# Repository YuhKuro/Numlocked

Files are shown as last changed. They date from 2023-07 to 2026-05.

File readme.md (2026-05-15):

GIF
## Directory:
- [Keyboard Hardware](hardware/readme.md)
- [Keyboard Firmware](firmware/readme.md)
- [Keyboard Case and Plate](case/readme.md)
- [Revision 1](Revision1/readme.md)
## Features
### **Keyboard Features:**
#### - **Modular split design**: Split 75% layout, flexible configuration with or without numpad
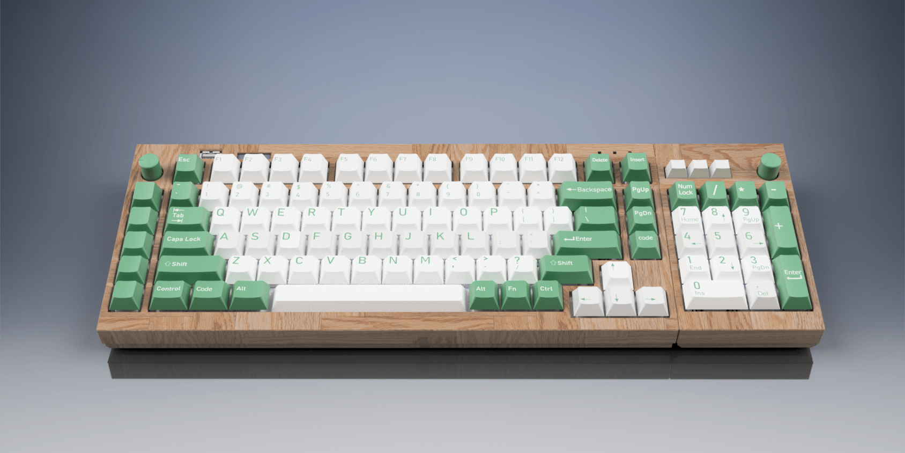
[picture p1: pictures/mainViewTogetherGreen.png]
Front

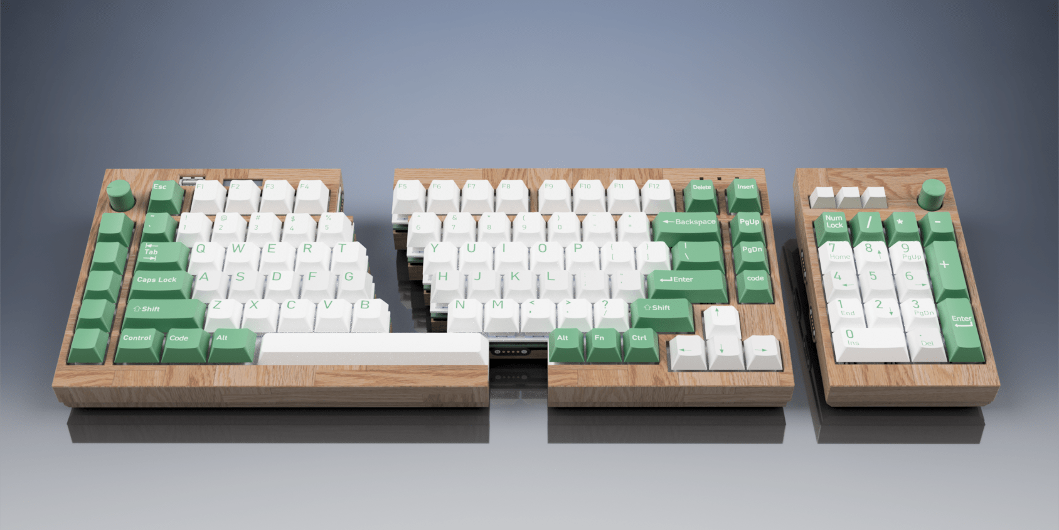
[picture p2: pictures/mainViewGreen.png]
Main

#### - **Magnetic connectors for quick configuration changes**
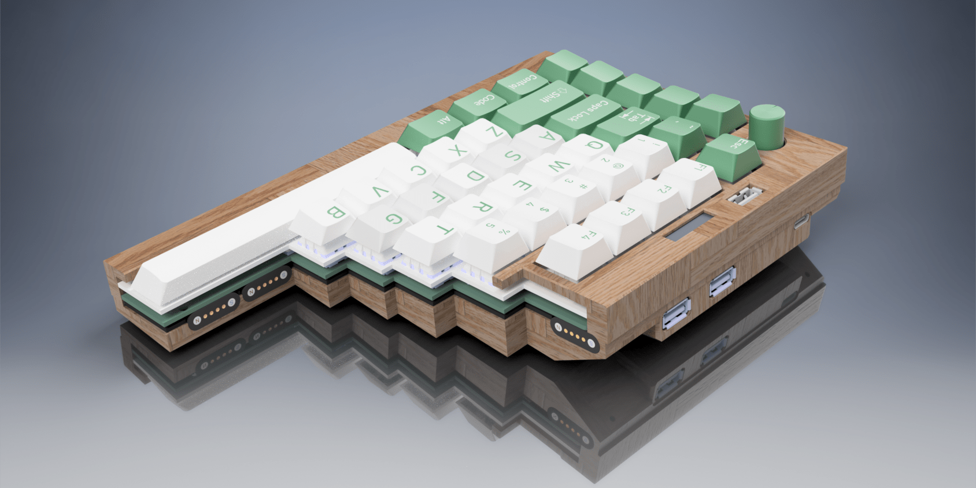
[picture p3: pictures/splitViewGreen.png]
magnets

#### - **Hot swappable & Gasket mount design**
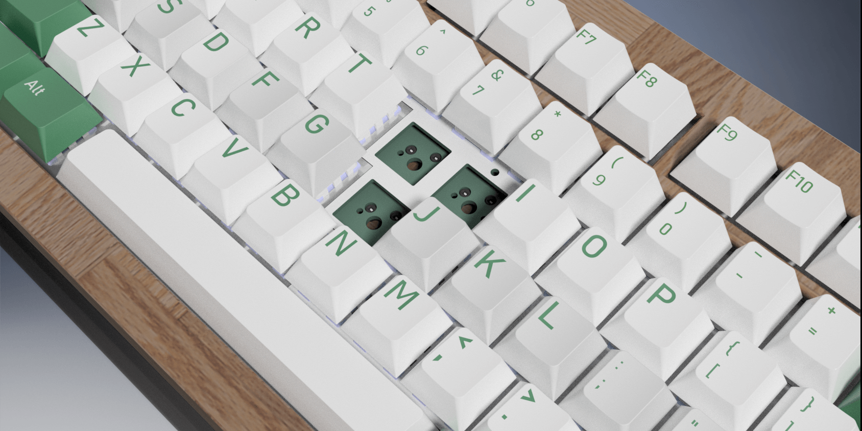
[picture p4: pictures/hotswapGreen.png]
Hotswap

#### - **Built-in USB Hub**: 3 USB-A ports (1 vertical, 2 horizontal)
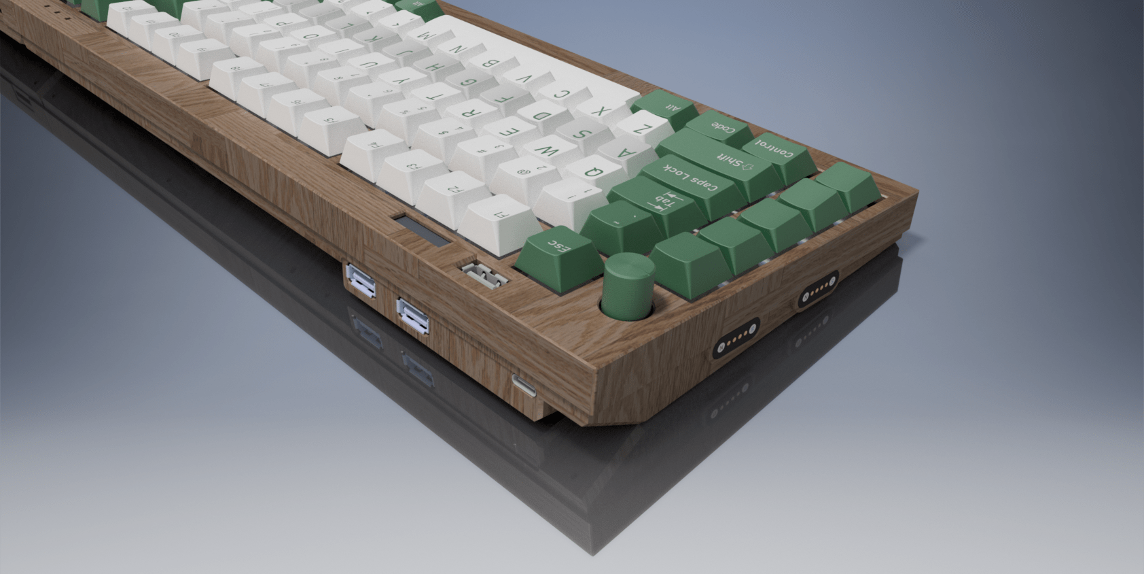
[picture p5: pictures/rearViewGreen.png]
Rear

#### - **Volume Knobs and Five Macro Keys**: Customizable for any function
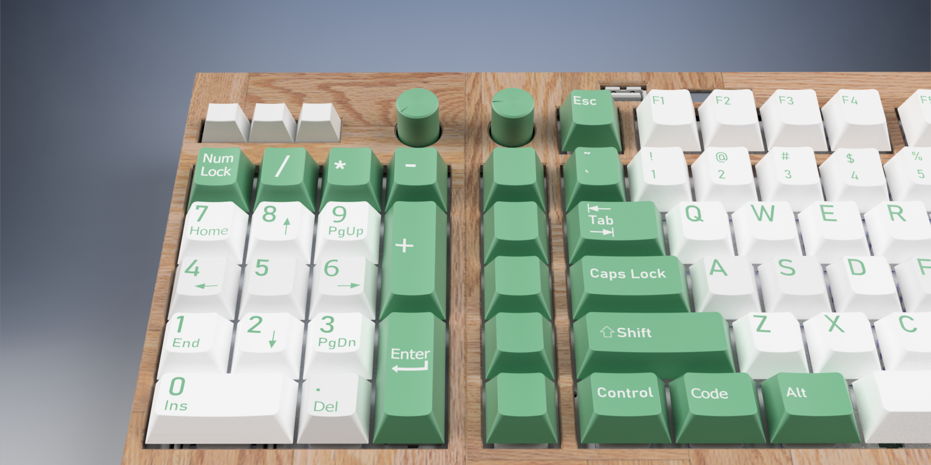
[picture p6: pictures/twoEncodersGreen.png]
Encoder

#### - **128x32 OLED**: Custom animations
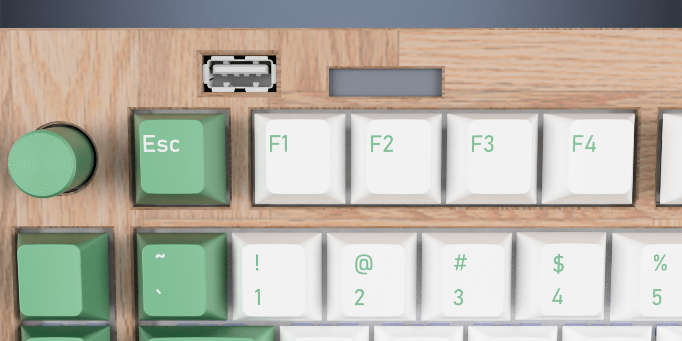
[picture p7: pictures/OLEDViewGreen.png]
OLED

#### - **Caps-lock, Num-lock and Scroll-Lock LEDs**
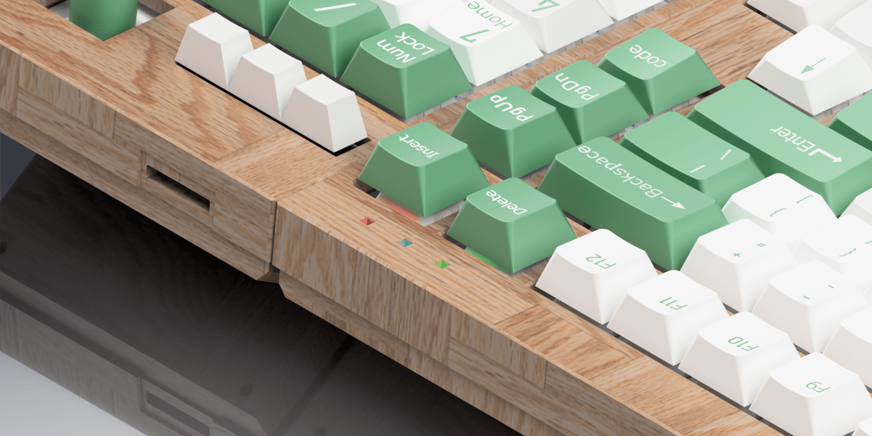
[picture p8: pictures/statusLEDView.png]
LEDs

#### -**Custom Hardware**: Three multilayer PCBs custom designed for Numlocked
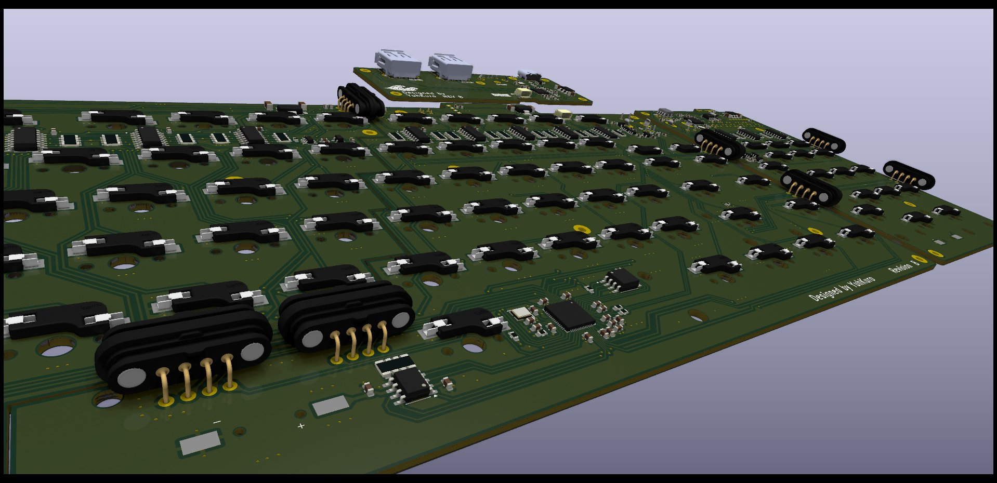
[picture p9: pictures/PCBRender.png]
Hardware

- **Shift-Registered Design**: Faster scanning than traditional matrix-based keyboards.
- **RP2040 chip**: Easy to program, very customizable, affordable.
- **Real-Time Clock (RTC)**: Keeps accurate time for the user.
#### - **Open Source**
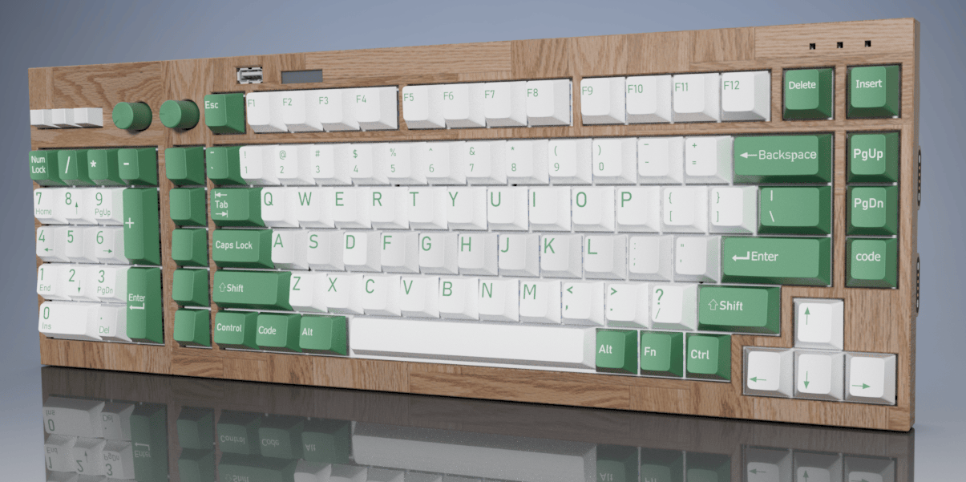
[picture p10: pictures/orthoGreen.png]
Ortho

- **Home Build**:
	- Akko CS Silver Switches
	- Durock V2 PCB Mount Stabilizers + holee mod
	- FR4 Plate
	- Resin 3D Printed case
- **Work Build**:
	- Akko CS Penguin case
	- Durock V2 PCB Mount Stabilizers + holee mod
	- FR4 Plate
	- Resin 3D Printed case

## Build Instructions
*See the [Build Guide](hardware/docs/buildInstructions.md) for detailed steps.*
## Customization
Firmware, coded in C, which leverages all the features of this keyboard are provided in this repo. [Learn more](firmware/readme.md)
Please note that QMK/VIA are currently incompatible with shift-register based keyboard designs.
## Commonly Asked Questions
- Why is it split?
	- I wanted to experiment with ergonomics. Another reason was production, The largest surface area my hotplate could manage was 400x400mm for reflow soldering.
- What was the total cost?
	- Will update once everything is complete.

## Thank you to:
- [SSD1306 library] (https://github.com/daschr/pico-ssd1306) by dachr. I added a function to print both images and text, but it was with his foundations that I was able to quickly get the OLED working.
- [cJSON library] (https://github.com/DaveGamble/cJSON) by DaveGamble. I swear I'm always using this. Its never failed me once. 
- And you, for viewing!

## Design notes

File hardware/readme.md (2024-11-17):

# Hardware

## Table of Contents
- [Introduction](#introduction)
- [Keyboard Fundamentals](#keyboard-fundamentals)
- [HUB PCB](#hub-pcb)
- [Leftside PCB](#left-side-pcb)
- [Rightside PCB](#right-side-pcb)
- [Numpad PCB](numpad-pcb)

## Introduction
The keyboard consists of four PCBs: A USB-Hub and three PCBs for each part of the keyboard: Leftside, Rightside and Numpad.
Each component is connected via magnetic pogo pins to transmit Power, Ground, keyboard signals and LED signals.

## Keyboard Fundamentals
Although most keyboards use a matrix-and-diode system, this keyboard uses a Parallel-load Serial-Shift shift-register approach.

Think of it like a train with containers moving along a circular track. Each container represents a key position, and the train can either load or shift its contents.

When the train is in "Load" mode, each container is set based on whether its corresponding key is pressed. If a key is not pressed, the container remains full; if it's pressed, the container will empty its contents out. 

In "Shift" mode, the train moves each container along, allowing us to check them one by one and identify which keys are pressed by checking which containers are empty.

In this keyboard, all shift registers are pulled up to 3V3 through a 10k-ohm resistor, so each key naturally sits at a high (3.3V) state, much like a full train car. When a key is pressed, it ground that bit on the shift register, reading it as low. By shifting the bits in the register the exact number of keys and feeding the information into an array, we will have a snapshot of what keys are pressed in that cycle. 

Since the SN74HC165DR Shift Registers used in this keyboard allow clocking in the range of a few MHz, there is practically zero chance a key input is missed as the next "load" phase is a just a few microseconds away.

This system also allows for minimal debouncing, requires zero diodes, only requires three pins to read any number of keys and true n-key rollover.

### Why this method?
Using shift registers allows for overall less individual soldering, easier programming and most importantly, only requires three pins (SH/~LD, CLK and Serial-Out).
If we chain shift registers beginning with the removable parts, such as the numpad, and transmit the serial-out to the next removable part, such as the right side, and finally to the left-side, we can manage a system with only one MCU by using multiplexers to avoid unknown values. 
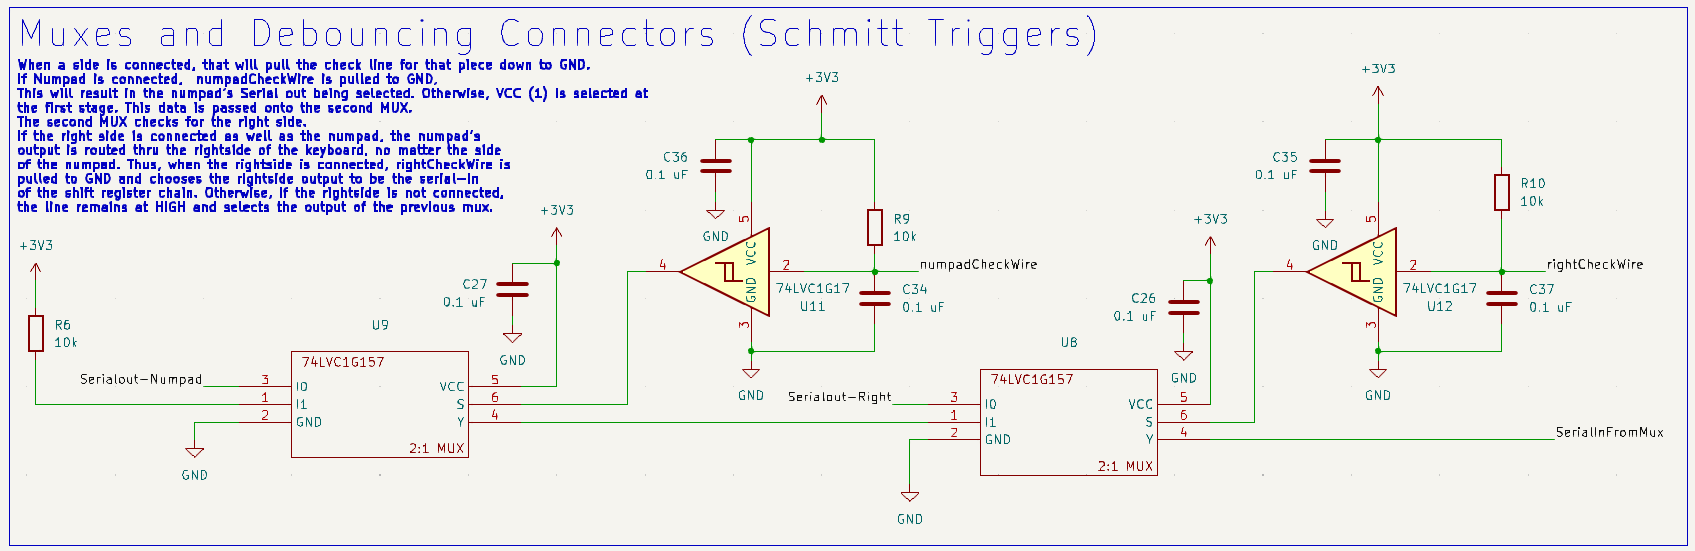
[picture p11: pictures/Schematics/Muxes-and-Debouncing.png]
Muxes and Connectors

We can do this by using multiplexers, which are basically data switches, and schmitt triggers which help ensure a clear signal. By using the schmitt triggers, the multiplexers always have a clean input on which component is connected. 

The flow chart into the first shift register of the left side is the following:

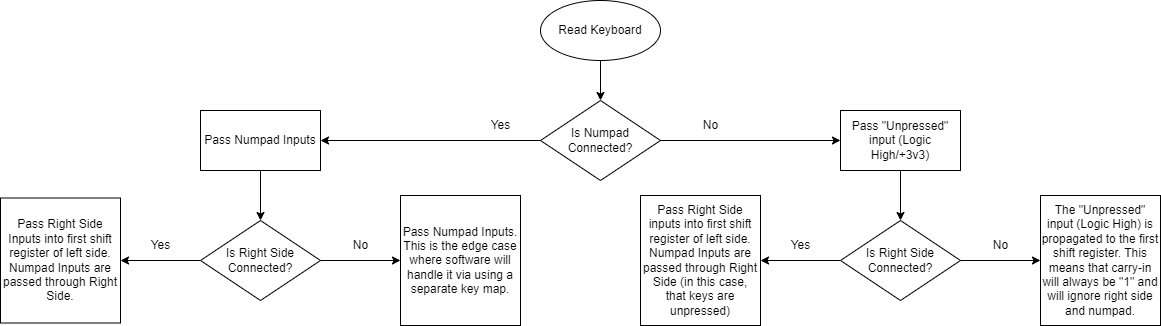
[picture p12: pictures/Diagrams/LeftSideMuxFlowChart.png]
Mux Flowchart


The edge case of numpad connected, but no right side is handled in software.

## Hub PCB
The Hub PCB is centered around a one-to-four USB 2.0 Full Speed HUB. There is one upstream USB-C port which connects to the user's computer and three USB-A ports for other peripherals, as well as an FFC cable which connects it to the keyboard itself.

To minimize space used in the case, there is a notched hole on the PCB itself to allow the FFC Cable to connect between the Hub to the keyboard PCB even when the two PCBs may be flush.

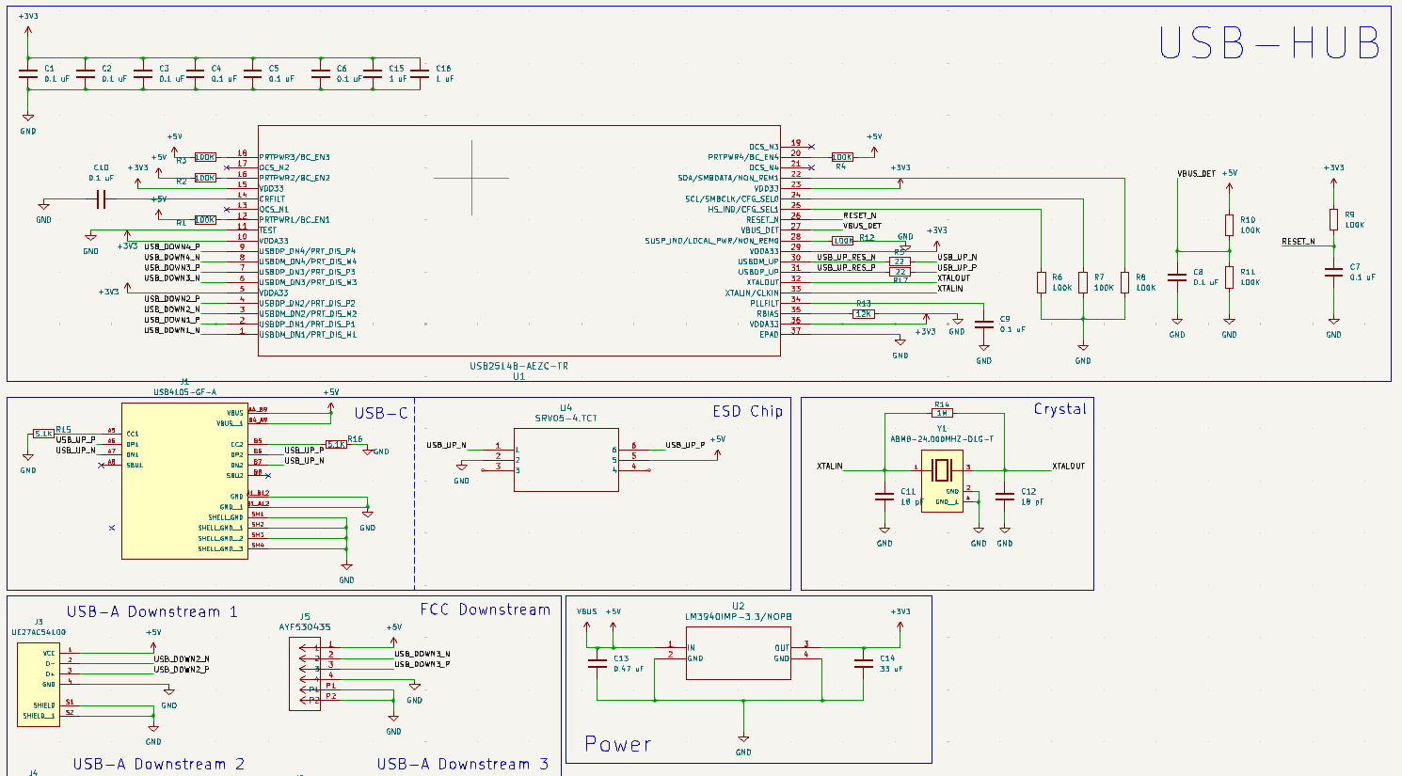
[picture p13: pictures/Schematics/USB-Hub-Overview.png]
USB Hub

## Left-Side PCB
The Left-Side PCB serves as the core of the keyboard’s functionality and is the only component capable of operating independently. This is due to the onboard RP2040 microcontroller, which manages all keyboard input processing. The Left-Side PCB features an FFC connector linking it to the USB Hub PCB, enabling seamless integration within the keyboard assembly.
The Left-Side PCB Features:
- FFC Connector to connect to the Hub
- RP2040 Microcontroller
	- 128 Mbit SPI Flash Memory
	- Crystal Oscillator
	- Header pins for Reset and USB Boot
- Five SN74HC165DR parallel-load serial-out shift registers to handle inputs
- Two four-pin magnetic pogo pins (2x4) to connect to the Numpad PCB.
- Three four-pin magnetic pogo pins (3x4) to connect to the Right-Side PCB
- Muxes and Debouncing Schmitt Triggers
- Real-time Clock (RTC) and CR1220 coin battery
### RP2040
The MCU for this keyboard is the RP2040, select for its cost, power efficiency and ease-of-programming, along with its plethora of GPIO pins and IO options. 
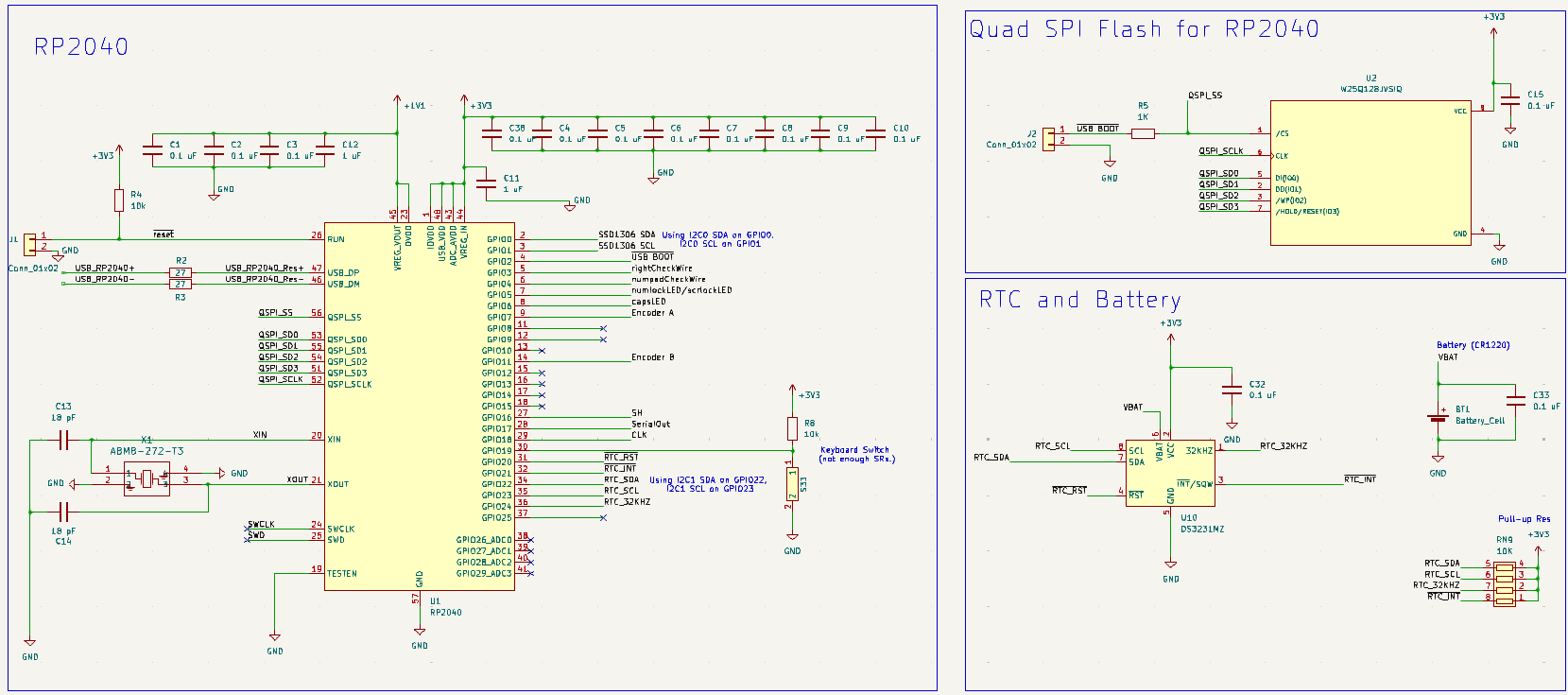
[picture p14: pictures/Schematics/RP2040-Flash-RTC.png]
RP2040 and Components

## Right-Side PCB
The Right-side PCB handles the right side of the keyboard's inputs and passes it the left-side of the keyboard.
Furthermore, the Right-Side PCB (if present) will also pass through the Numpad's data to the left side of the keyboard. This design was chosen to minimize the number of Magnetic Pogo Pin Connectors
## Numpad PCB
The Numpad PCB contains much of the same components as the Left-Side PCB.

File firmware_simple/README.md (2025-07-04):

# Firmware for Numlocked Keyboard

Firmware used to interface with windows/linux/probably MacOS but I don't have one to test :(

## To Build:

### Prerequisites:
You need the following:
1. [Raspberry Pi Pico SDK](https://github.com/raspberrypi/pico-sdk)
2. cmake, python3, a native compiler, and a GCC compiler: ```sudo apt install cmake python3 build-essential gcc-arm-none-eabi libnewlib-arm-none-eabi libstdc++-arm-none-eabi-newlib```
3. [Picotool](https://github.com/raspberrypi/picotool) is nice to have for flashing

### Commands:

You will likely have to modify the `CMakeLists.txt` file's fifth line which sets the Pico SDK directory. By default, it is set to my setup where the pico-sdk directory is located two directoies above this one.

It is the usual cmake.
```
mkdir build
cd build
cmake ..
make
```

Then, you can use picotool to flash. Move to wherever you installed picotool and:  
```
sudo ./picotool load PARENT/Numlocked/firmware/build/numlocked.uf2

sudo ./picotool verify PARENT/Numlocked/firmware/build/numlocked.uf2

sudo ./picotool reboot
```

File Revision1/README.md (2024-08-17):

# Numlocked: Shift
 A 75% + 25% Keyboard with extras
 ## Features:
 - "standard" 75% ANSI US QWERTY Layout
 - Hot Swappable
 - Integrated Fingerprint Sensor
 - Leftside Numpad
 - Volume Knob, Dedicated Media Keys
 - Four extra keys above the keypad, nine extra F keys. 
 - Separate USB hub with two USB-A ports and one USB-C connection
 - 128x32 OLED
 
Front of Keyboard PCB:
Front of Keyboard PCB
Back of keyboard PCB:
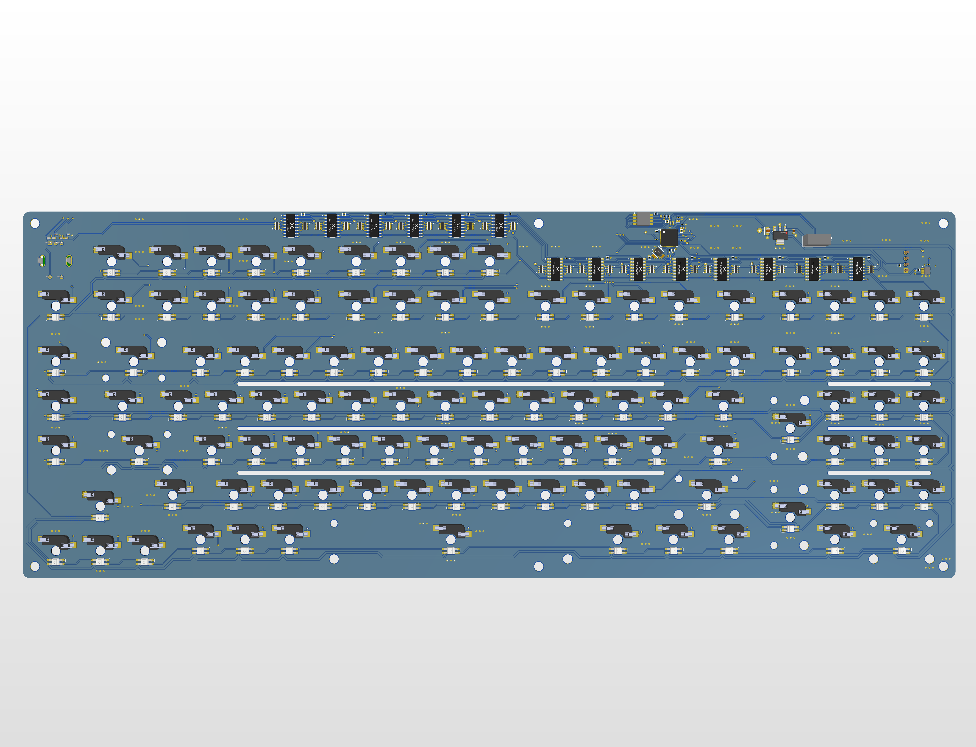
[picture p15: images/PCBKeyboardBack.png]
Back of Keyboard PCB


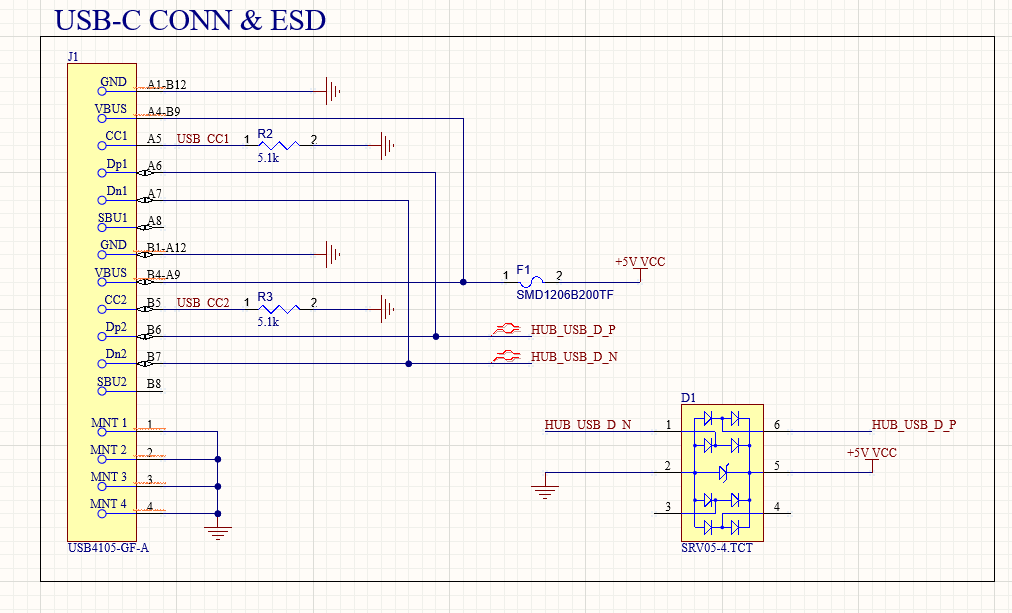
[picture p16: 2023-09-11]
Revision1/images/Schematic/HUB/USB-CSCH.png

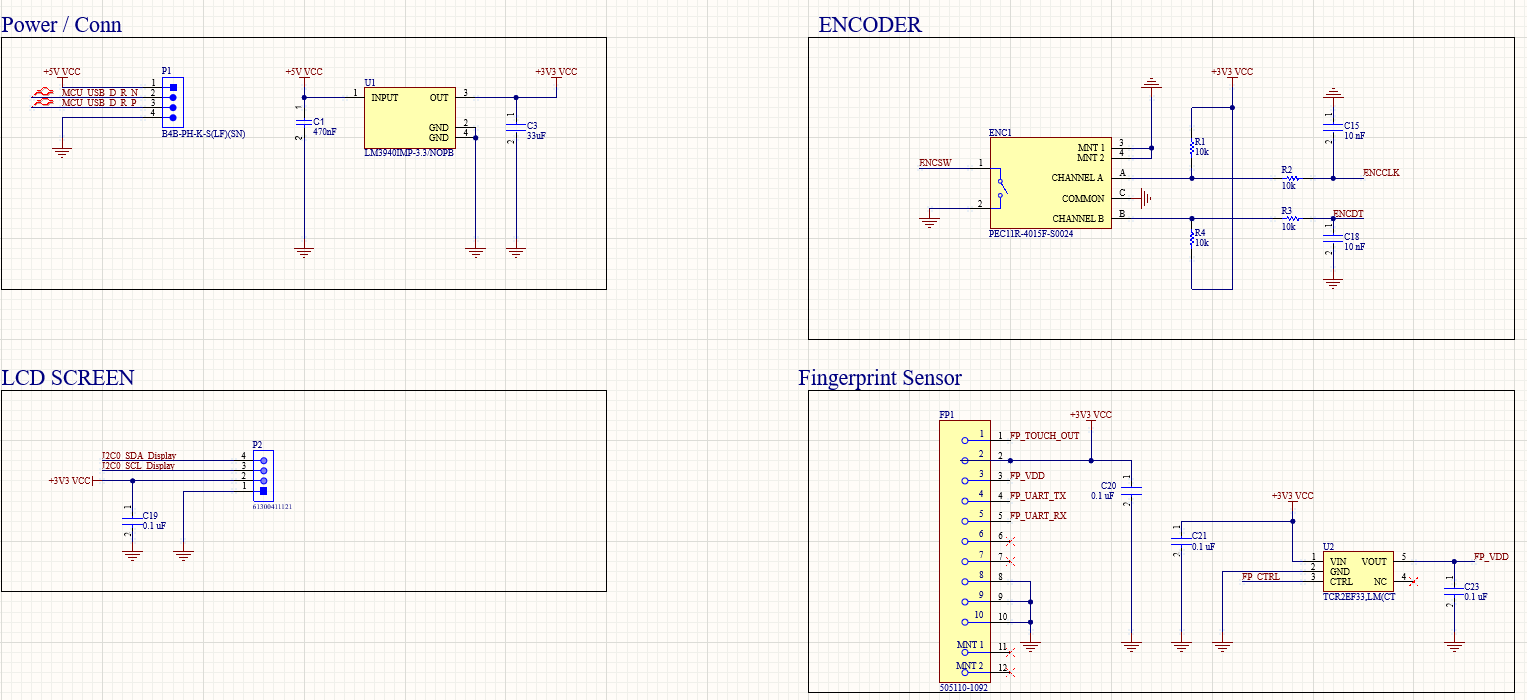
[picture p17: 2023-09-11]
Revision1/images/Schematic/Keyboard/AuxilarySch.PNG

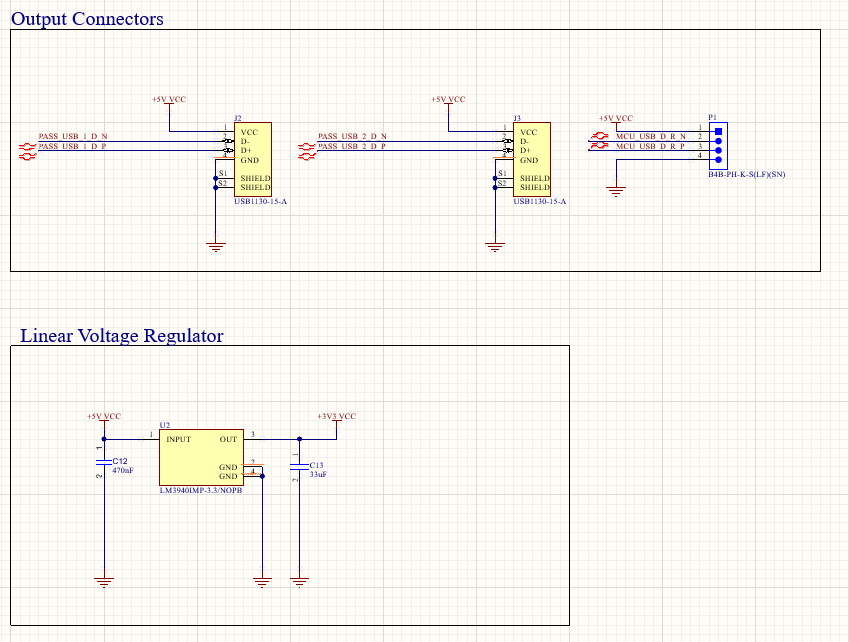
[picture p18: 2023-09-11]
Revision1/images/Schematic/HUB/OutputandPower.PNG

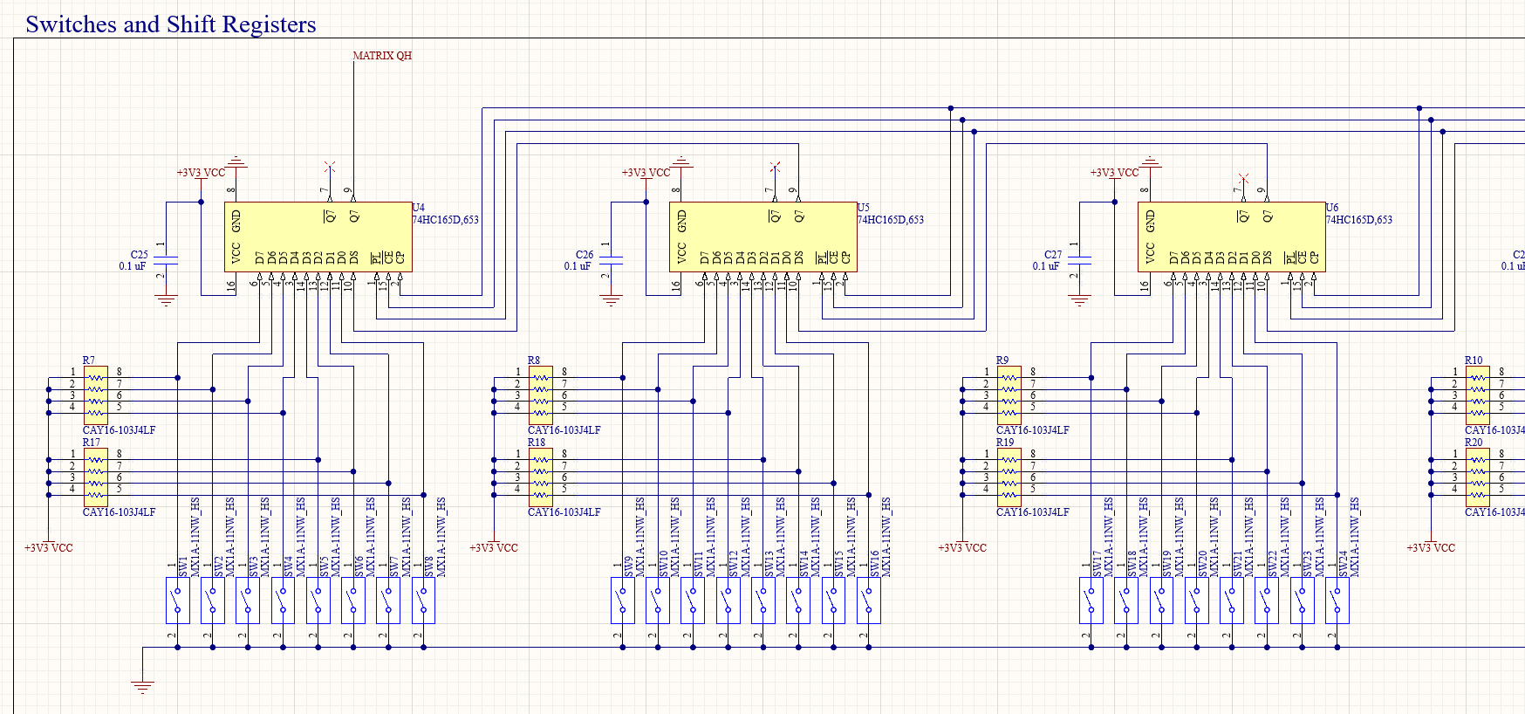
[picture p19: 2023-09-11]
Revision1/images/Schematic/Keyboard/ShiftRegisterSCH.png

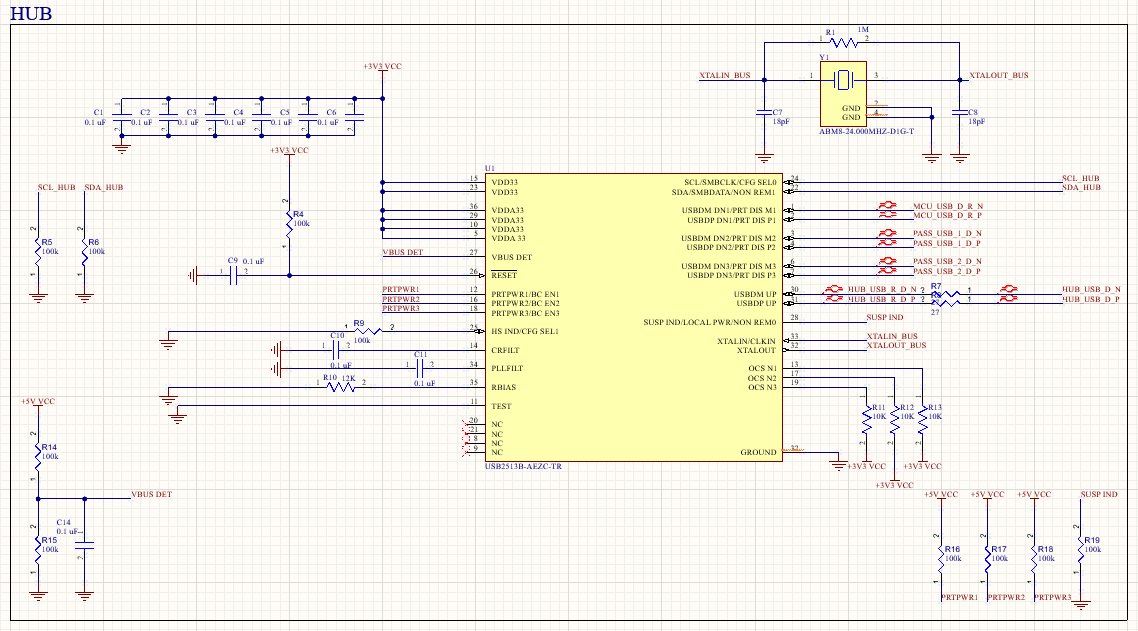
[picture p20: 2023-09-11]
Revision1/images/Schematic/HUB/HUBsch.PNG

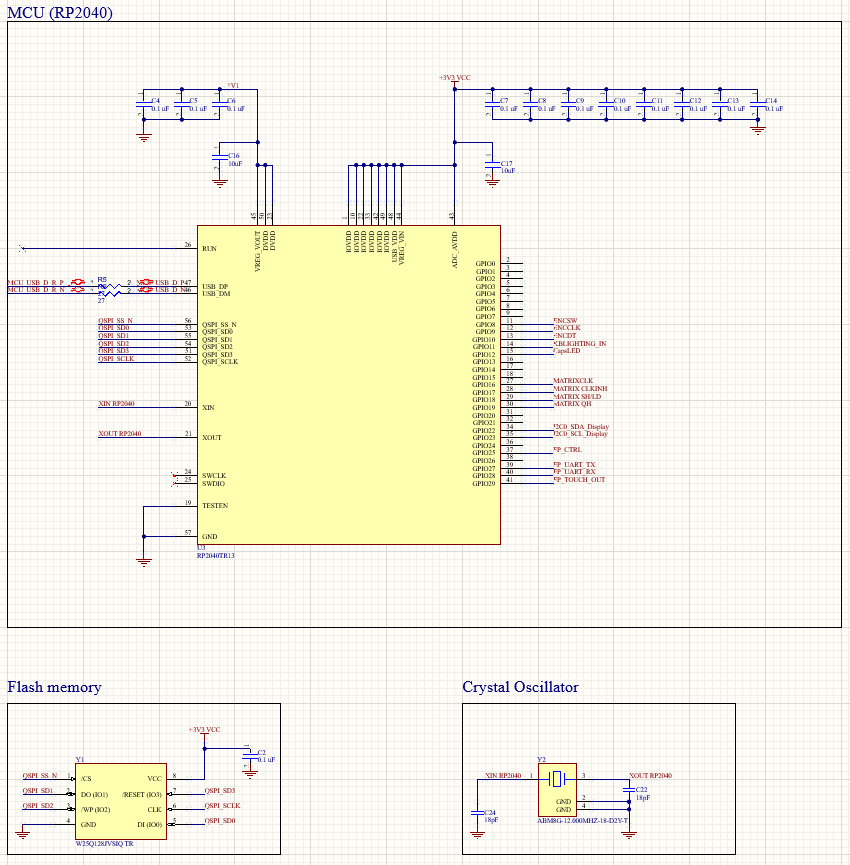
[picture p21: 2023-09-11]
Revision1/images/Schematic/Keyboard/RP2040SCH.PNG

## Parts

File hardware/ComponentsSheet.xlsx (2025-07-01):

Type | Value | Package | Amount
Res | 5.1k | 0603 | 95
RP2040 |  | QFN | 4
Cap | 1 uF | 0603 | 480
Res Array | 10k | 1206 | 100
1x2 pin |  | 2mm | 50
USB-C |  |  | 9
Res | 100k | 0402 | 500
Cap | 10 uF | 0603 | 100
Bat |  | CR1220 | 5
USB-A |  | Vert | 5
USB Hub | 1 to 4 | QFN | 2
Res | 10k | 0603 | 990
Schmitt Trig |  |  | 16
Cap | 18 pF | 0603 | 91
Cap | 10 uF | 1206 | 97
Res Array | 10k | 2012 | 78
Res | 100k | 603 | 474
PEC-11R |  |  | 1
LED |  | 2401 | 50
Res | 1M | 603 | 99
FFC | 4 pin | 0.5 mm | 1
Shift Reg | 8-to-1 | SOP-16 | 28
Push Switch |  |  | 5
LDO | 5V to 3.3V | SOT-223 | 2 - 3?
ESD |  | SOT-23-6 | 3
Res | 82 ohm | 603 | 18
Flash | 128mBit |  | 2
Res | 240 ohm | 603 | 100
Mux | 2 to 1 | TSOP | 6
Crystal | 12 Mhz |  | 2
Cap | 0.1 uF | 603 | 450
Cap | 0.1 uF | 1206 | 100
Cap | 0.47 uF |  | 16
Cap | 0.33 uF |  | 2
XTAL | 24 mHz |  | 3
Res | 27 ohm | 603 | 4
Res | 22 ohm | 603 | 8

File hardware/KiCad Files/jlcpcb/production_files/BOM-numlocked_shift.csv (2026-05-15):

Comment | Designator | Footprint | LCSC
0.1 uF | C1,C10,C15,C18,C2,C22,C23,C24,C25,C26,C27,C28,C3,C30,C34,C35,C36,C37,C38,C39,C4,C5,C6,C7,C8,C9 | C_0603_1608Metric | C129176
1K | R5 | R_0603_1608Metric | C14676
10 uF | C29,C31 | C_0603_1608Metric | C18800
RP2040 | U1 | QFN-56-1EP_7x7mm_P0.4mm_EP3.2x3.2mm | C2040
ABM8-272-T3 | X1 | Crystal_SMD_Abracon_ABM8AIG-4Pin_3.2x2.5mm | C20625731
1 uF | C11,C12 | C_0603_1608Metric | C2214844
18 pF | C13,C14 | C_0603_1608Metric | C388905
27 | R2,R3 | R_0603_1608Metric | C403127
SN74HC165DR | U13,U4,U5,U6,U7 | SOP-16_3.9x9.9mm_P1.27mm | C61060
74LVC1G17 | U11,U12 | SOT-23-5 | C7836
10K | RN1,RN10,RN11,RN2,RN3,RN4,RN5,RN6,RN7,RN8 | R_Array_Convex_4x1206 | C784821
W25Q128JVSIQ | U2 | SOIC127P790X216-8N | C97521
10k | R10,R4,R6,R9 | R_0603_1608Metric | C98220
~ | S32 | SW_Cherry_Kalih_1.00u
Conn_01x02 | J2 | PinSocket_1x02_P2.00mm_Vertical
~ | S38 | SW_Cherry_Kalih_1.00u
~ | S36 | SW_Cherry_Kalih_1.00u
~ | S4 | SW_Cherry_Kalih_1.00u
~ | S31 | SW_Cherry_Kalih_1.00u
~ | S20 | SW_Cherry_Kalih_1.00u
~ | S2 | SW_Cherry_Kalih_1.00u
~ | S35 | SW_Cherry_Kalih_1.00u
~ | S8 | SW_Cherry_Kalih_2.25u
~ | S30 | SW_Cherry_Kalih_1.00u
~ | S37 | SW_Cherry_Kalih_1.00u
~ | S33 | SW_Cherry_Kalih_6.25u
~ | S10 | SW_Cherry_Kalih_1.00u
~ | S25 | SW_Cherry_Kalih_1.00u
~ | S24 | SW_Cherry_Kalih_1.00u
Conn_01x04 | J7 | Magnetic_Pogo_Pin_4pos
~ | S21 | SW_Cherry_Kalih_1.00u
~ | S14 | SW_Cherry_Kalih_1.00u
~ | S29 | SW_Cherry_Kalih_1.00u
~ | S19 | SW_Cherry_Kalih_1.00u
Conn_01x04 | J6 | Magnetic_Pogo_Pin_4pos
~ | S1 | SW_Cherry_Kalih_1.00u
~ | S34 | SW_Cherry_Kalih_1.00u
~ | S26 | SW_Cherry_Kalih_1.00u
~ | S11 | SW_Cherry_Kalih_1.25u
~ | S15 | SW_Cherry_Kalih_1.00u
~ | S9 | SW_Cherry_Kalih_1.25u
~ | S6 | SW_Cherry_Kalih_1.5u
~ | S17 | SW_Cherry_Kalih_1.00u
~ | S28 | SW_Cherry_Kalih_1.00u
~ | S7 | SW_Cherry_Kalih_1.75u
~ | S3 | SW_Cherry_Kalih_1.00u
~ | S16 | SW_Cherry_Kalih_1.00u
~ | S18 | SW_Cherry_Kalih_1.00u
~ | S5 | SW_Cherry_Kalih_1.00u
SSD1306 | Brd1 | SSD1306-0.91-OLED-4pin-128x32
~ | S27 | SW_Cherry_Kalih_1.00u
~ | S12 | SW_Cherry_Kalih_1.25u
Conn_01x04 | J5 | Magnetic_Pogo_Pin_4pos
~ | S13 | SW_Cherry_Kalih_1.00u
~ | S23 | SW_Cherry_Kalih_1.00u
~ | S22 | SW_Cherry_Kalih_1.00u
NC | C19 | C_0603_1608Metric
Conn_01x04 | J3 | Magnetic_Pogo_Pin_4pos
~ | U9 | SC-74-6_1.55x2.9mm_P0.95mm
33 uF | C17 | C_1206_3216Metric
SM04B-SRSS-TB | J8 | CONN_SM04B-SRSS-TB_JST
0.47 uF | C16 | C_1206_3216Metric
LM3940IMP-3.3/NOPB | U3 | SOT-223
~ | U8 | SC-74-6_1.55x2.9mm_P0.95mm
Conn_01x04 | J4 | Magnetic_Pogo_Pin_4pos
1K | R8 | R_0603_1608Metric
LED (capslock R) | D2 | LED_0805_2012Metric_Pad1.15x1.40mm_HandSolder
82 | R11 | R_0603_1608Metric_Pad0.98x0.95mm_HandSolder
Conn_01x02 | J1 | PinSocket_1x02_P2.00mm_Vertical
PEC11R-4215F-S0024 | MT1 | XDCR_PEC11R-4215F-S0024
10k | R1 | R_0603_1608Metric
10k | R7 | R_0603_1608Metric
10k | R14 | R_0603_1608Metric
0.01 uF | C20 | C_0603_1608Metric
10k | R12 | R_0603_1608Metric
10k | R13 | R_0603_1608Metric
0.01 uF | C21 | C_0603_1608Metric
~ | S39 | SW_Cherry_Kalih_1.00u
~ | S40 | SW_Cherry_Kalih_1.00u
DNF | R15 | R_0603_1608Metric

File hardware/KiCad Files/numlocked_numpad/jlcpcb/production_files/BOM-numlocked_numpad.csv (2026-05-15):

Comment | Designator | Footprint | LCSC
240 | R5 | R_0603_1608Metric | C114613
0.1 uF | C12,C13,C14,C17,C18,C19,C2,C20,C21,C22,C23,C24,C25,C26,C28,C29,C3,C4,C9 | C_0603_1608Metric | C129176
1K | R11 | R_0603_1608Metric | C14676
RP2040 | U6 | QFN-56-1EP_7x7mm_P0.4mm_EP3.2x3.2mm | C2040
ABM8G-12.000MHZ-18-D2Y-T | X1 | Crystal_SMD_Abracon_ABM8AIG-4Pin_3.2x2.5mm | C20625731
15 pF | C10,C11 | C_0603_1608Metric | C388905
27 | R8,R9 | R_0603_1608Metric | C403127
SN74HC165DR | U2,U3,U4 | SN74HC165DR | C61060
1 uF | C15,C16 | C_0603_1608Metric | C77046
10K | RN1,RN2,RN3,RN4,RN5,RN6 | R_Array_Convex_4x1206 | C784821
W25Q128JVSIQ | U7 | SOIC_128JVSIQ_WIN | C97521
10k | R1,R12,R13,R14,R2,R6,R7 | R_0603_1608Metric | C98220
~ | S9 | SW_Cherry_Kalih_1.00u
~ | S2 | SW_Cherry_Kalih_1.00u
~ | S17 | SW_Cherry_Kalih_1.00u
~ | S8 | SW_Cherry_Kalih_1.00u
Conn_01x04 | J3 | Magnetic_Pogo_Pin_4pos
~ | S6 | SW_Cherry_Kalih_1.00u
~ | S3 | SW_Cherry_Kalih_1.00u
~ | OLED1 | PinSocket_1x07_P2.54mm_Vertical
~ | S12 | SW_Cherry_Kalih_1.00u
Conn_01x04 | J4 | Magnetic_Pogo_Pin_4pos
~ | S11 | SW_Cherry_Kalih_1.00u
~ | S10 | SW_Cherry_Kalih_1.00u
~ | S16 | SW_Cherry_Kalih_1.00u
~ | S15 | SW_Cherry_Kalih_2.00u_vert
~ | S1 | SW_Cherry_Kalih_1.00u
~ | S18 | SW_Cherry_Kalih_1.00u
~ | S19 | SW_Cherry_Kalih_1.00u
~ | SW1 | SK13D07VG4
~ | S7 | SW_Cherry_Kalih_2.00u
~ | S20 | SW_Cherry_Kalih_2.00u_vert
~ | S14 | SW_Cherry_Kalih_1.00u
Conn_01x02 | J5 | PinSocket_1x02_P2.00mm_Vertical
33 uF | C7 | C_1206_3216Metric
1k | R3 | R_0603_1608Metric
~ | U5 | SC-74-6_1.55x2.9mm_P0.95mm
0.47 uF | C6 | C_1206_3216Metric
Conn_01x04 | J2 | Magnetic_Pogo_Pin_4pos
~ | U9 | SC-74-6_1.55x2.9mm_P0.95mm
LM3940IMP-3.3/NOPB | U1 | SOT-223
~ | U10 | SC-74-6_1.55x2.9mm_P0.95mm
Conn_01x04 | J1 | Magnetic_Pogo_Pin_4pos
LED Power | D1 | LED_0603_1608Metric
SM04B-SRSS-TB | J7 | CONN_SM04B-SRSS-TB_JST
Conn_01x02 | J6 | PinSocket_1x02_P2.00mm_Vertical
0 | R10 | R_0603_1608Metric
10 uF | C1 | C_0603_1608Metric

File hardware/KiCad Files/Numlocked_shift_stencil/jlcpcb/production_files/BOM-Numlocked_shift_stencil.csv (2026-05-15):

Comment | Designator | Footprint | LCSC
0.1 uF | C1,C10,C15,C18,C2,C22,C23,C24,C25,C26,C27,C28,C3,C30,C34,C35,C36,C37,C38,C39,C4,C5,C6,C7,C8,C9 | C_0603_1608Metric | C129176
1K | R5 | R_0603_1608Metric | C14676
10 uF | C29,C31 | C_0603_1608Metric | C18800
RP2040 | U1 | QFN-56-1EP_7x7mm_P0.4mm_EP3.2x3.2mm | C2040
ABM8-272-T3 | X1 | Crystal_SMD_Abracon_ABM8AIG-4Pin_3.2x2.5mm | C20625731
1 uF | C11,C12 | C_0603_1608Metric | C2214844
18 pF | C13,C14 | C_0603_1608Metric | C388905
27 | R2,R3 | R_0603_1608Metric | C403127
SN74HC165DR | U13,U4,U5,U6,U7 | SOP-16_3.9x9.9mm_P1.27mm | C61060
74LVC1G17 | U11,U12 | SOT-23-5 | C7836
10K | RN1,RN10,RN11,RN2,RN3,RN4,RN5,RN6,RN7,RN8 | R_Array_Convex_4x1206 | C784821
W25Q128JVSIQ | U2 | SOIC127P790X216-8N | C97521
10k | R10,R4,R6,R9 | R_0603_1608Metric | C98220
Conn_01x02 | J1 | PinSocket_1x02_P2.00mm_Vertical
~ | S4 | SW_Cherry_Kalih_1.00u
~ | S20 | SW_Cherry_Kalih_1.00u
10k | R13 | R_0603_1608Metric
~ | U8 | SC-74-6_1.55x2.9mm_P0.95mm
0.01 uF | C21 | C_0603_1608Metric
1K | R8 | R_0603_1608Metric
10k | R12 | R_0603_1608Metric
LM3940IMP-3.3/NOPB | U3 | SOT-223
SM04B-SRSS-TB | J8 | CONN_SM04B-SRSS-TB_JST
10k | R14 | R_0603_1608Metric
10k | R7 | R_0603_1608Metric
~ | U9 | SC-74-6_1.55x2.9mm_P0.95mm
0.01 uF | C20 | C_0603_1608Metric
NC | C19 | C_0603_1608Metric
0.47 uF | C16 | C_1206_3216Metric
10k | R1 | R_0603_1608Metric
33 uF | C17 | C_1206_3216Metric
Conn_01x02 | J2 | PinSocket_1x02_P2.00mm_Vertical
~ | S3 | SW_Cherry_Kalih_1.00u
PEC11R-4215F-S0024 | MT1 | XDCR_PEC11R-4215F-S0024
SSD1306 | Brd1 | SSD1306-0.91-OLED-4pin-128x32
~ | S5 | SW_Cherry_Kalih_1.00u
Conn_01x04 | J5 | Magnetic_Pogo_Pin_4pos
~ | S21 | SW_Cherry_Kalih_1.00u

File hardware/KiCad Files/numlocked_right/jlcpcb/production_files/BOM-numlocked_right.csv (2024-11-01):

Comment | Designator | Footprint | LCSC
~ | S2 | SW_Cherry_Kalih_1.00u
~ | S26 | SW_Cherry_Kalih_1.00u
~ | S42 | SW_Cherry_Kalih_2.00u
~ | S12 | SW_Cherry_Kalih_1.00u
Conn_01x04 | J1 | Magnetic_Pogo_Pin_4pos
~ | S28 | SW_Cherry_Kalih_1.00u
~ | S11 | SW_Cherry_Kalih_1.00u
~ | S41 | SW_Cherry_Kalih_1.00u
Conn_01x04 | J2 | Magnetic_Pogo_Pin_4pos
~ | S36 | SW_Cherry_Kalih_1.00u
~ | S19 | SW_Cherry_Kalih_1.00u
~ | S31 | SW_Cherry_Kalih_1.00u
~ | S25 | SW_Cherry_Kalih_1.00u
~ | S23 | SW_Cherry_Kalih_1.00u
~ | S1 | SW_Cherry_Kalih_1.00u
~ | S33 | SW_Cherry_Kalih_1.00u
~ | S45 | SW_Cherry_Kalih_1.00u
~ | S13 | SW_Cherry_Kalih_1.00u
~ | S7 | SW_Cherry_Kalih_1.00u
~ | S49 | SW_Cherry_Kalih_1.00u
~ | S29 | SW_Cherry_Kalih_1.00u
~ | S40 | SW_Cherry_Kalih_1.00u
~ | S17 | SW_Cherry_Kalih_1.00u
~ | S24 | SW_Cherry_Kalih_1.00u
~ | S6 | SW_Cherry_Kalih_1.00u
~ | S37 | SW_Cherry_Kalih_2.25u
~ | S15 | SW_Cherry_Kalih_1.00u
~ | S34 | SW_Cherry_Kalih_1.00u
~ | S9 | SW_Cherry_Kalih_1.00u
~ | S21 | SW_Cherry_Kalih_1.00u
~ | S43 | SW_Cherry_Kalih_1.00u
~ | S4 | SW_Cherry_Kalih_1.00u
~ | S10 | SW_Cherry_Kalih_1.00u
~ | S16 | SW_Cherry_Kalih_1.00u
~ | S38 | SW_Cherry_Kalih_1.75u
~ | S3 | SW_Cherry_Kalih_1.00u
~ | S20 | SW_Cherry_Kalih_1.00u
~ | S27 | SW_Cherry_Kalih_1.00u
LED (capslock R) | D1 | LED_0805_2012Metric
~ | S22 | SW_Cherry_Kalih_1.00u
~ | S18 | SW_Cherry_Kalih_1.00u
LED (numlock G) | D3 | LED_0805_2012Metric
~ | S32 | SW_Cherry_Kalih_1.00u
~ | S30 | SW_Cherry_Kalih_1.00u
~ | S44 | SW_Cherry_Kalih_1.00u
~ | S46 | SW_Cherry_Kalih_1.00u
~ | S35 | SW_Cherry_Kalih_1.75u
~ | S5 | SW_Cherry_Kalih_1.00u
~ | S8 | SW_Cherry_Kalih_1.00u
LED (scrlock Y) | D4 | LED_0805_2012Metric
~ | S39 | SW_Cherry_Kalih_1.00u
~ | S47 | SW_Cherry_Kalih_1.00u
~ | S14 | SW_Cherry_Kalih_1.00u
~ | S48 | SW_Cherry_Kalih_1.00u
Conn_01x04 | J4 | Magnetic_Pogo_Pin_4pos
10K | RN5 | R_Array_Convex_4x1206
10K | RN4 | R_Array_Convex_4x1206
LM3940IMP-3.3/NOPB | U8 | SOT-223
R | R1 | R_0603_1608Metric
10k | R6 | R_0603_1608Metric
SN74HC165DR | U2 | SOIC127P600X175-16N
10K | RN14 | R_Array_Convex_4x1206
R | R4 | R_0603_1608Metric
0.1 uF | C16 | C_0603_1608Metric
10K | RN3 | R_Array_Convex_4x1206
0.1 uF | C5 | C_0603_1608Metric
10K | RN6 | R_Array_Convex_4x1206
0.1 uF | C9 | C_0603_1608Metric
~ | U7 | SC-74-6_1.55x2.9mm_P0.95mm
10K | RN1 | R_Array_Convex_4x1206
SN74HC165DR | U3 | SOIC127P600X175-16N
10K | RN7 | R_Array_Convex_4x1206
33 uF | C13 | C_1206_3216Metric
10K | RN2 | R_Array_Convex_4x1206
R | R3 | R_0603_1608Metric
0.1 uF | C3 | C_0603_1608Metric
SN74HC165DR | U4 | SOIC127P600X175-16N
10K | RN11 | R_Array_Convex_4x1206
0.1 uF | C2 | C_0603_1608Metric
0.47 uF | C12 | C_1206_3216Metric
SN74HC165DR | U6 | SOIC127P600X175-16N
SN74HC165DR | U5 | SOIC127P600X175-16N
10K | RN12 | R_Array_Convex_4x1206
10 uF | C11 | C_0603_1608Metric
0.1 uF | C1 | C_0603_1608Metric
0.1 uF | C7 | C_0603_1608Metric
SN74HC165DR | U9 | SOIC127P600X175-16N
0.1 uF | C6 | C_0603_1608Metric
10K | RN8 | R_Array_Convex_4x1206
10K | RN13 | R_Array_Convex_4x1206
10 uF | C8 | C_0603_1608Metric
R | R5 | R_0603_1608Metric
10K | RN9 | R_Array_Convex_4x1206
Conn_01x04 | J3 | Magnetic_Pogo_Pin_4pos
0.1 uF | C15 | C_0603_1608Metric
0.1 uF | C14 | C_0603_1608Metric
Conn_01x04 | J5 | Magnetic_Pogo_Pin_4pos
0.1 uF | C10 | C_0603_1608Metric
10k | R7 | R_0603_1608Metric
10K | RN10 | R_Array_Convex_4x1206
0.1 uF | C4 | C_0603_1608Metric
SN74HC165DR | U1 | SOIC127P600X175-16N
74LVC1G17 | U10 | SOT-23-5

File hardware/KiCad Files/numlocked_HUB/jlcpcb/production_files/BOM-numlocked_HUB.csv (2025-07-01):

Comment | Designator | Footprint | LCSC
1 uF | C15 | C_0603_1608Metric
100K | R6 | R_0603_1608Metric
USB4105-GF-A | J1 | GCT_USB4105-GF-A
UE27AC54100 | J3 | AMPHENOL_UE27AC54100
SM04B-SRSS-TB | J5 | CONN_SM04B-SRSS-TB_JST
0.1 uF | C5 | C_0603_1608Metric
USB2514B-AEZC-TR | U1 | QFN36_6X6MC_MCH
5.1K | R16 | R_0603_1608Metric
0.1 uF | C9 | C_0603_1608Metric
100K | R8 | R_0603_1608Metric
UE27AC54100 | J4 | AMPHENOL_UE27AC54100
0.1 uF | C1 | C_0603_1608Metric
0.1 uF | C10 | C_0603_1608Metric
22 | R5 | R_0603_1608Metric
100K | R12 | R_0603_1608Metric
18 pF | C11 | C_0603_1608Metric
0.47 uF | C13 | C_1206_3216Metric
100K | R7 | R_0603_1608Metric
0.1 uF | C4 | C_0603_1608Metric
100K | R3 | R_0603_1608Metric
0.1 uF | C6 | C_0603_1608Metric
33 uF | C14 | C_1206_3216Metric
1M | R14 | R_0603_1608Metric
0.1 uF | C8 | C_0603_1608Metric
100K | R9 | R_0603_1608Metric
100K | R4 | R_0603_1608Metric
SRV05-4.TCT | U4 | SO6_SOT23-6L
5.1K | R15 | R_0603_1608Metric
0.1 uF | C2 | C_0603_1608Metric
100K | R10 | R_0603_1608Metric
12K | R13 | R_0603_1608Metric
100K | R1 | R_0603_1608Metric
0.1 uF | C7 | C_0603_1608Metric
18 pF | C12 | C_0603_1608Metric
0.1 uF | C3 | C_0603_1608Metric
ABM8-24.000MHZ-D1G-T | Y1 | Crystal_SMD_Abracon_ABM8G-4Pin_3.2x2.5mm
100K | R2 | R_0603_1608Metric
LM3940IMP-3.3/NOPB | U2 | SOT-223
100K | R11 | R_0603_1608Metric
1 uF | C16 | C_0603_1608Metric
~ | J2 | UBAS-4R-D14D-4D(LF)(SN)
22 | R17 | R_0603_1608Metric

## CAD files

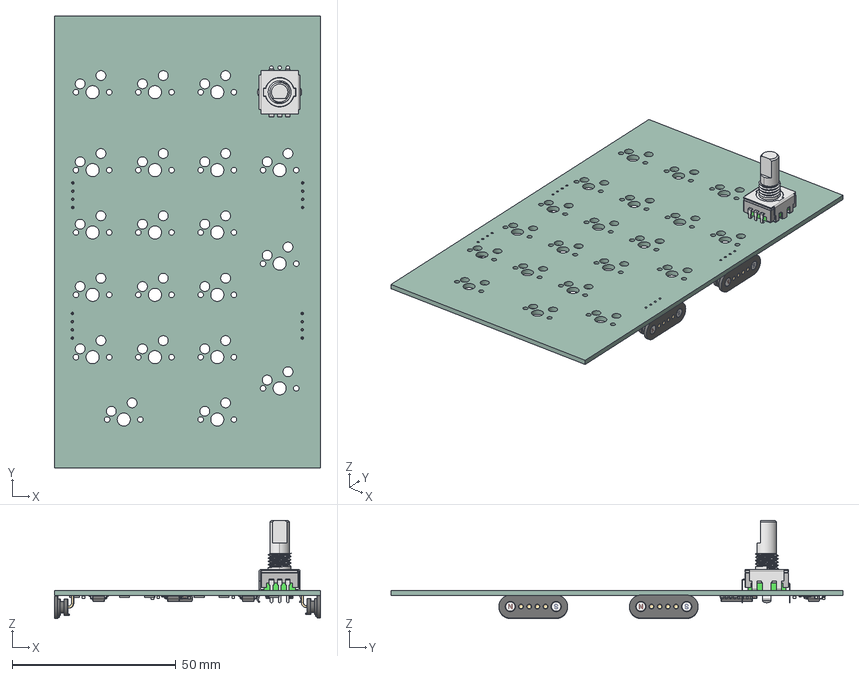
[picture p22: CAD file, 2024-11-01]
hardware/KiCad Files/numlocked_numpad/numlocked_numpad.step
81.4 x 138.1 x 30.1 mm
PEC11R-4215F-S0024
Magnetic Pogo Connector 4 Pin (Type 3) x 4
R_Array_Convex_4x1206 x 6
C_0603_1608Metric x 7
R_0603_1608Metric x 5
SOIC_16_39x99mm_P127mm x 3
SOT_223
LED_0603_1608Metric
numlocked_numpad_PCB

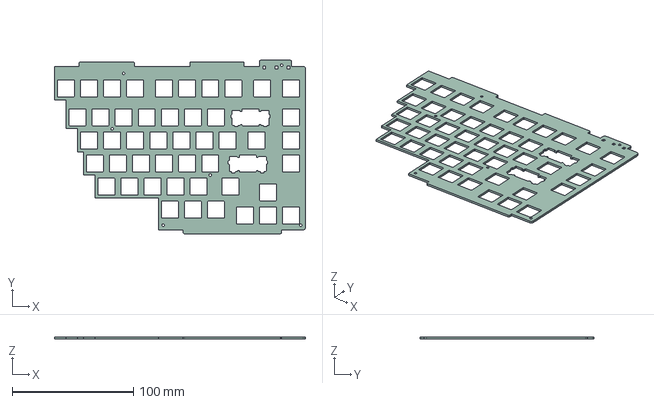
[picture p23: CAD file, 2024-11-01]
hardware/KiCad Files/numlocked_right_plate/numlocked_right_plate.step
207.1 x 143.2 x 1.60 mm

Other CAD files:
case/BotNumpadCase.ipt
case/BottomLeftCase.ipt
case/BottomRightCase.ipt
case/NumpadPlate.ipt
case/TopCase.ipt
case/TopNumpadCase.ipt
case/TopRightCase.ipt
case/keycaps/ASDF Row/4_Numpad.ipt
case/keycaps/ASDF Row/5_Numpad.ipt
case/keycaps/ASDF Row/6_Numpad.ipt
case/keycaps/ASDF Row/Key_A.ipt
case/keycaps/ASDF Row/Key_Apostrophe.ipt
case/keycaps/ASDF Row/Key_Caps_Lock.ipt
case/keycaps/ASDF Row/Key_D.ipt
case/keycaps/ASDF Row/Key_F.ipt
case/keycaps/ASDF Row/Key_G.ipt
case/keycaps/ASDF Row/Key_H.ipt
case/keycaps/ASDF Row/Key_J.ipt
case/keycaps/ASDF Row/Key_K.ipt
case/keycaps/ASDF Row/Key_L.ipt
case/keycaps/ASDF Row/Key_S.ipt
case/keycaps/ASDF Row/Key_Semicolon.ipt
case/keycaps/ASDF Row/Key_code.ipt
case/keycaps/ASDF Row/Key_empty.ipt
case/keycaps/ASDF Row/OldVersions/4_Numpad.0001.ipt
case/keycaps/ASDF Row/OldVersions/6_Numpad.0001.ipt
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

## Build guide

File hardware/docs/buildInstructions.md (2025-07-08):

# Build Instructions

## PCB

#### Required Tools

- [400mm x 400 mm Hot Plate]

- [Hot Air Rework Station]†

- [Solder Paste]

- [Soldering Iron]

- [Solder]

- A few fine pairs of tweezers

- [Solder Wick]†
  
  Non-technical tools

- [Nitrile Gloves]

- An unused plastic card or something to spread the solder paste

- Isopropyl Alcohol, I suggest above 90% (99% is my go-to.)
  
  - Or better yet, [Board Cleaner]
  
  †: You do not *need* these items if you execute making them perfectly (Impossible).

#### Soldering (Reflow)

Begin by placing your stencil over your pads and spreading your solder paste thinly.

Place the SMD components carefully onto the PCB, ensuring orientation is accurate.

Place your PCB and preheat to around 180 C. Leave for around 3 minutes.

Ramp up heat to 350 C. 

Let rest.

### Case
Drill

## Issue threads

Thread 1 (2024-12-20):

Shift modifer not working off cold boot

YuhKuro, 2024-12-20:
There is a known issue where the when booting on Windows with the keyboard already plugged in, the shift modifier will refuse to function.
Other modifier keys such as "Alt" and "Ctrl" function as normal, and the "shift" keypress itself is registered.

Unplugging and replugging in the keyboard will not resolve the issue. Restarting has resolved it everytime.

This issue happens very rarely (once every 50 or so boots), I have never had it happen twice in one day.

YuhKuro, 2025-06-26:
This was an issue with Windows powertools, Not the keyboard.

Closed 2025-06-26.

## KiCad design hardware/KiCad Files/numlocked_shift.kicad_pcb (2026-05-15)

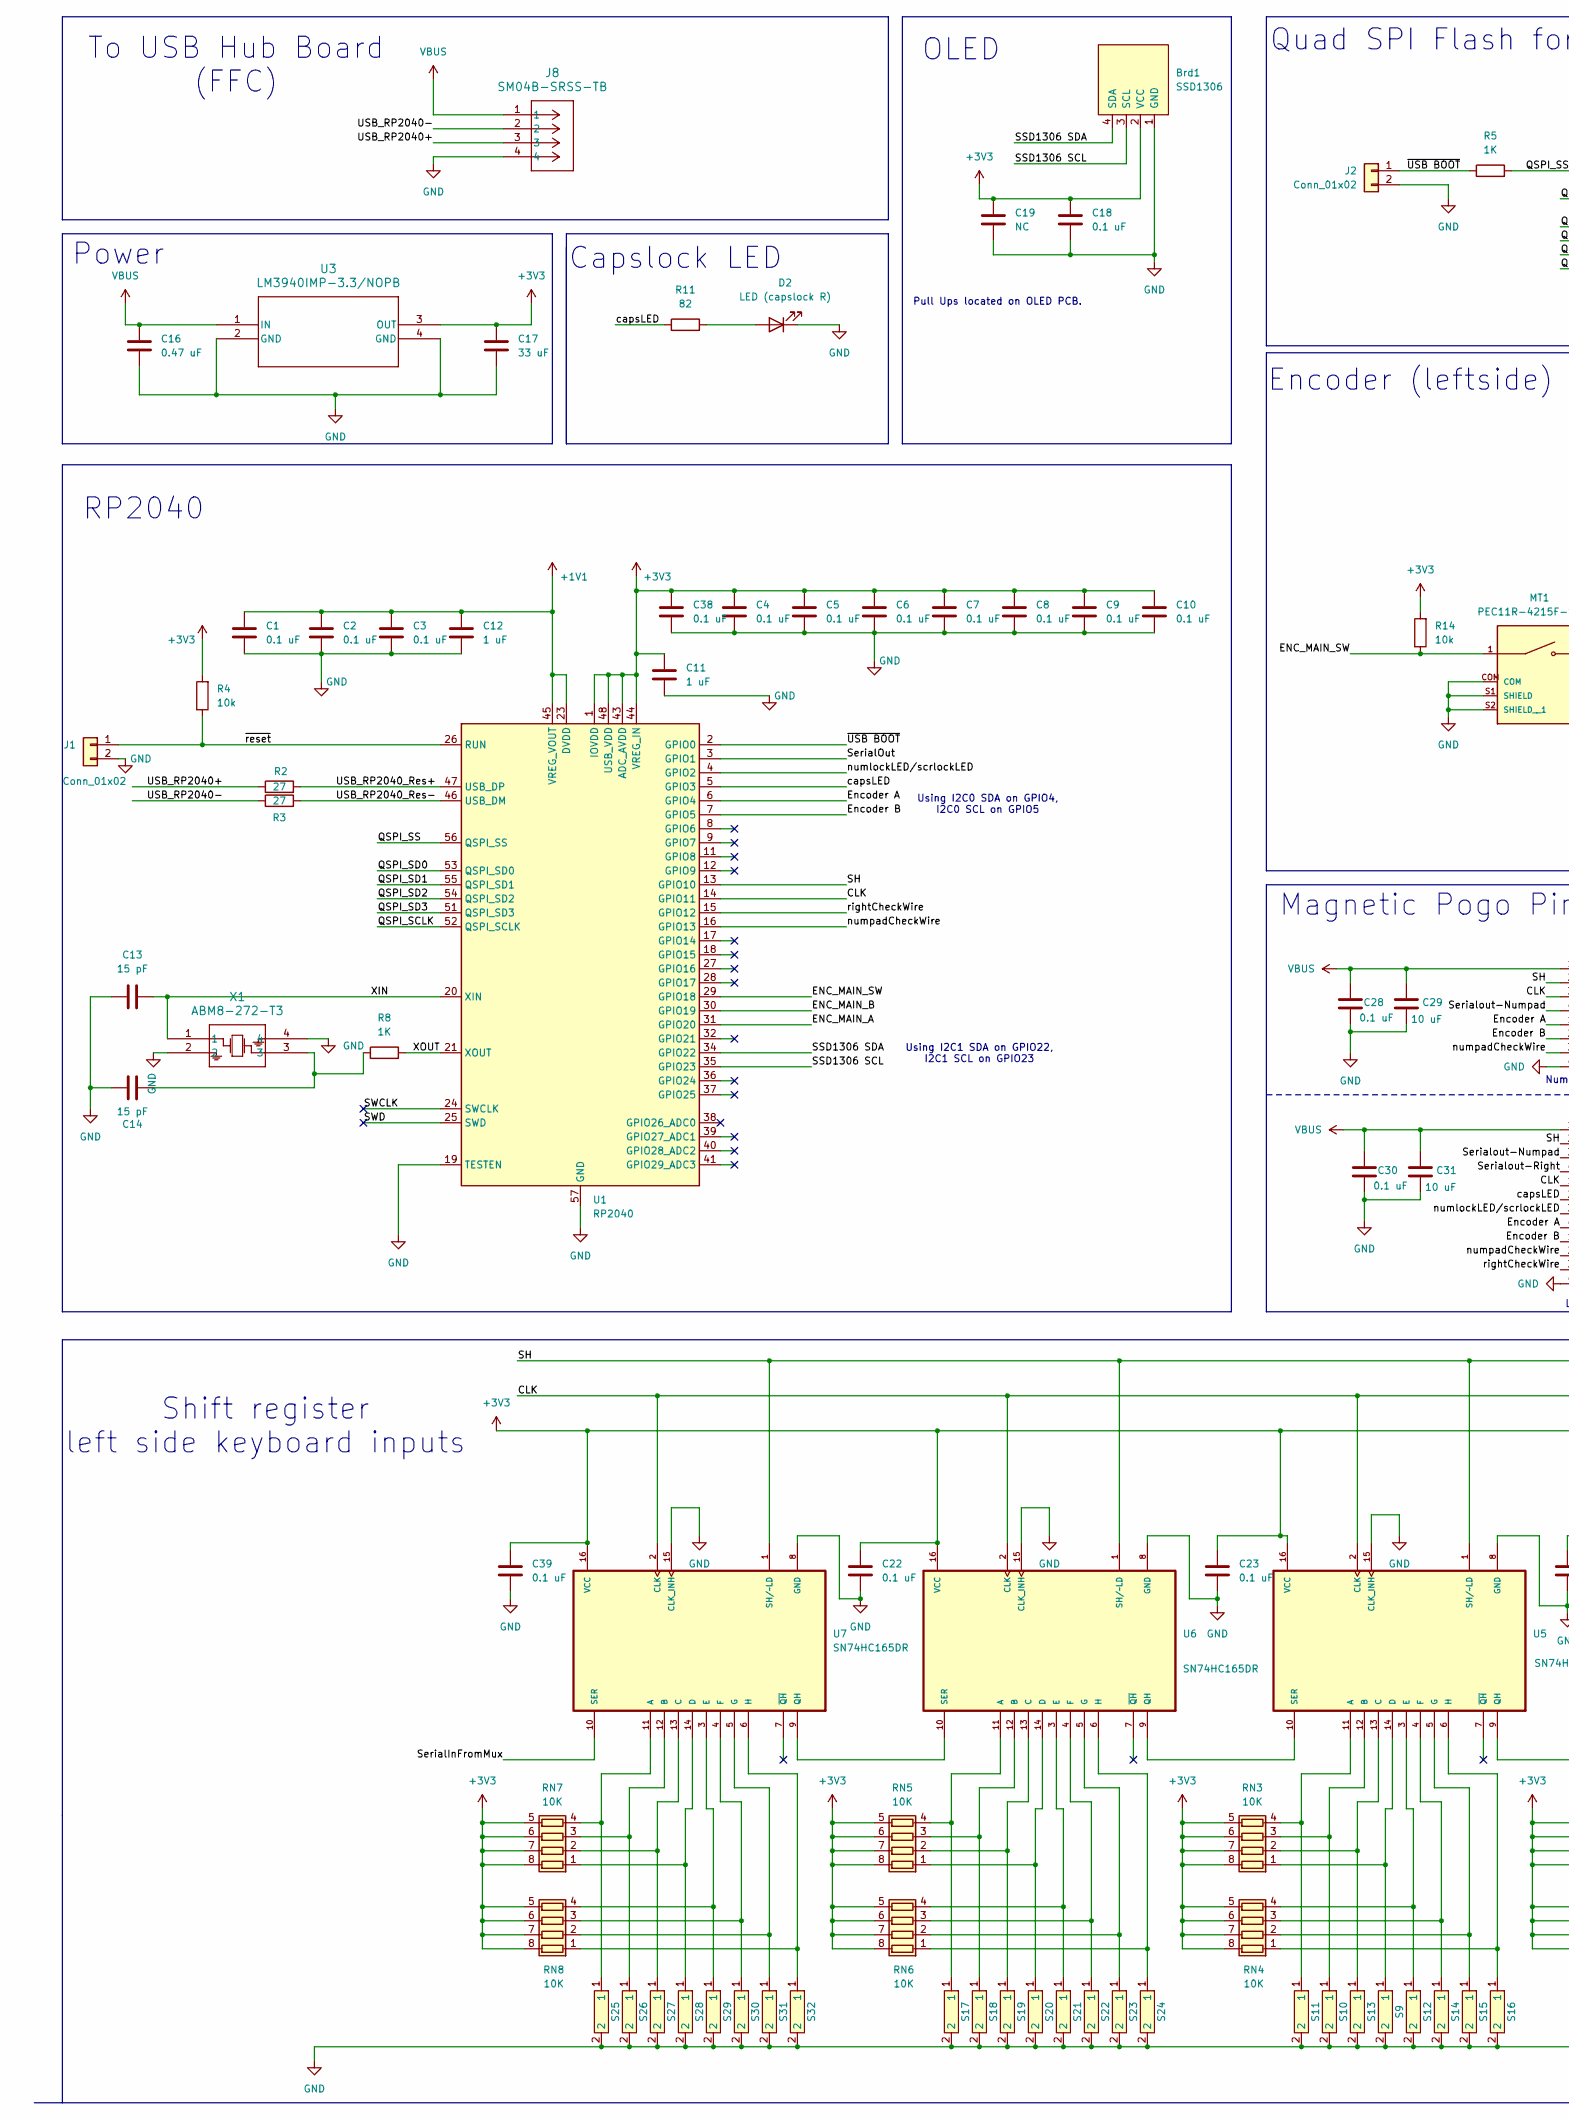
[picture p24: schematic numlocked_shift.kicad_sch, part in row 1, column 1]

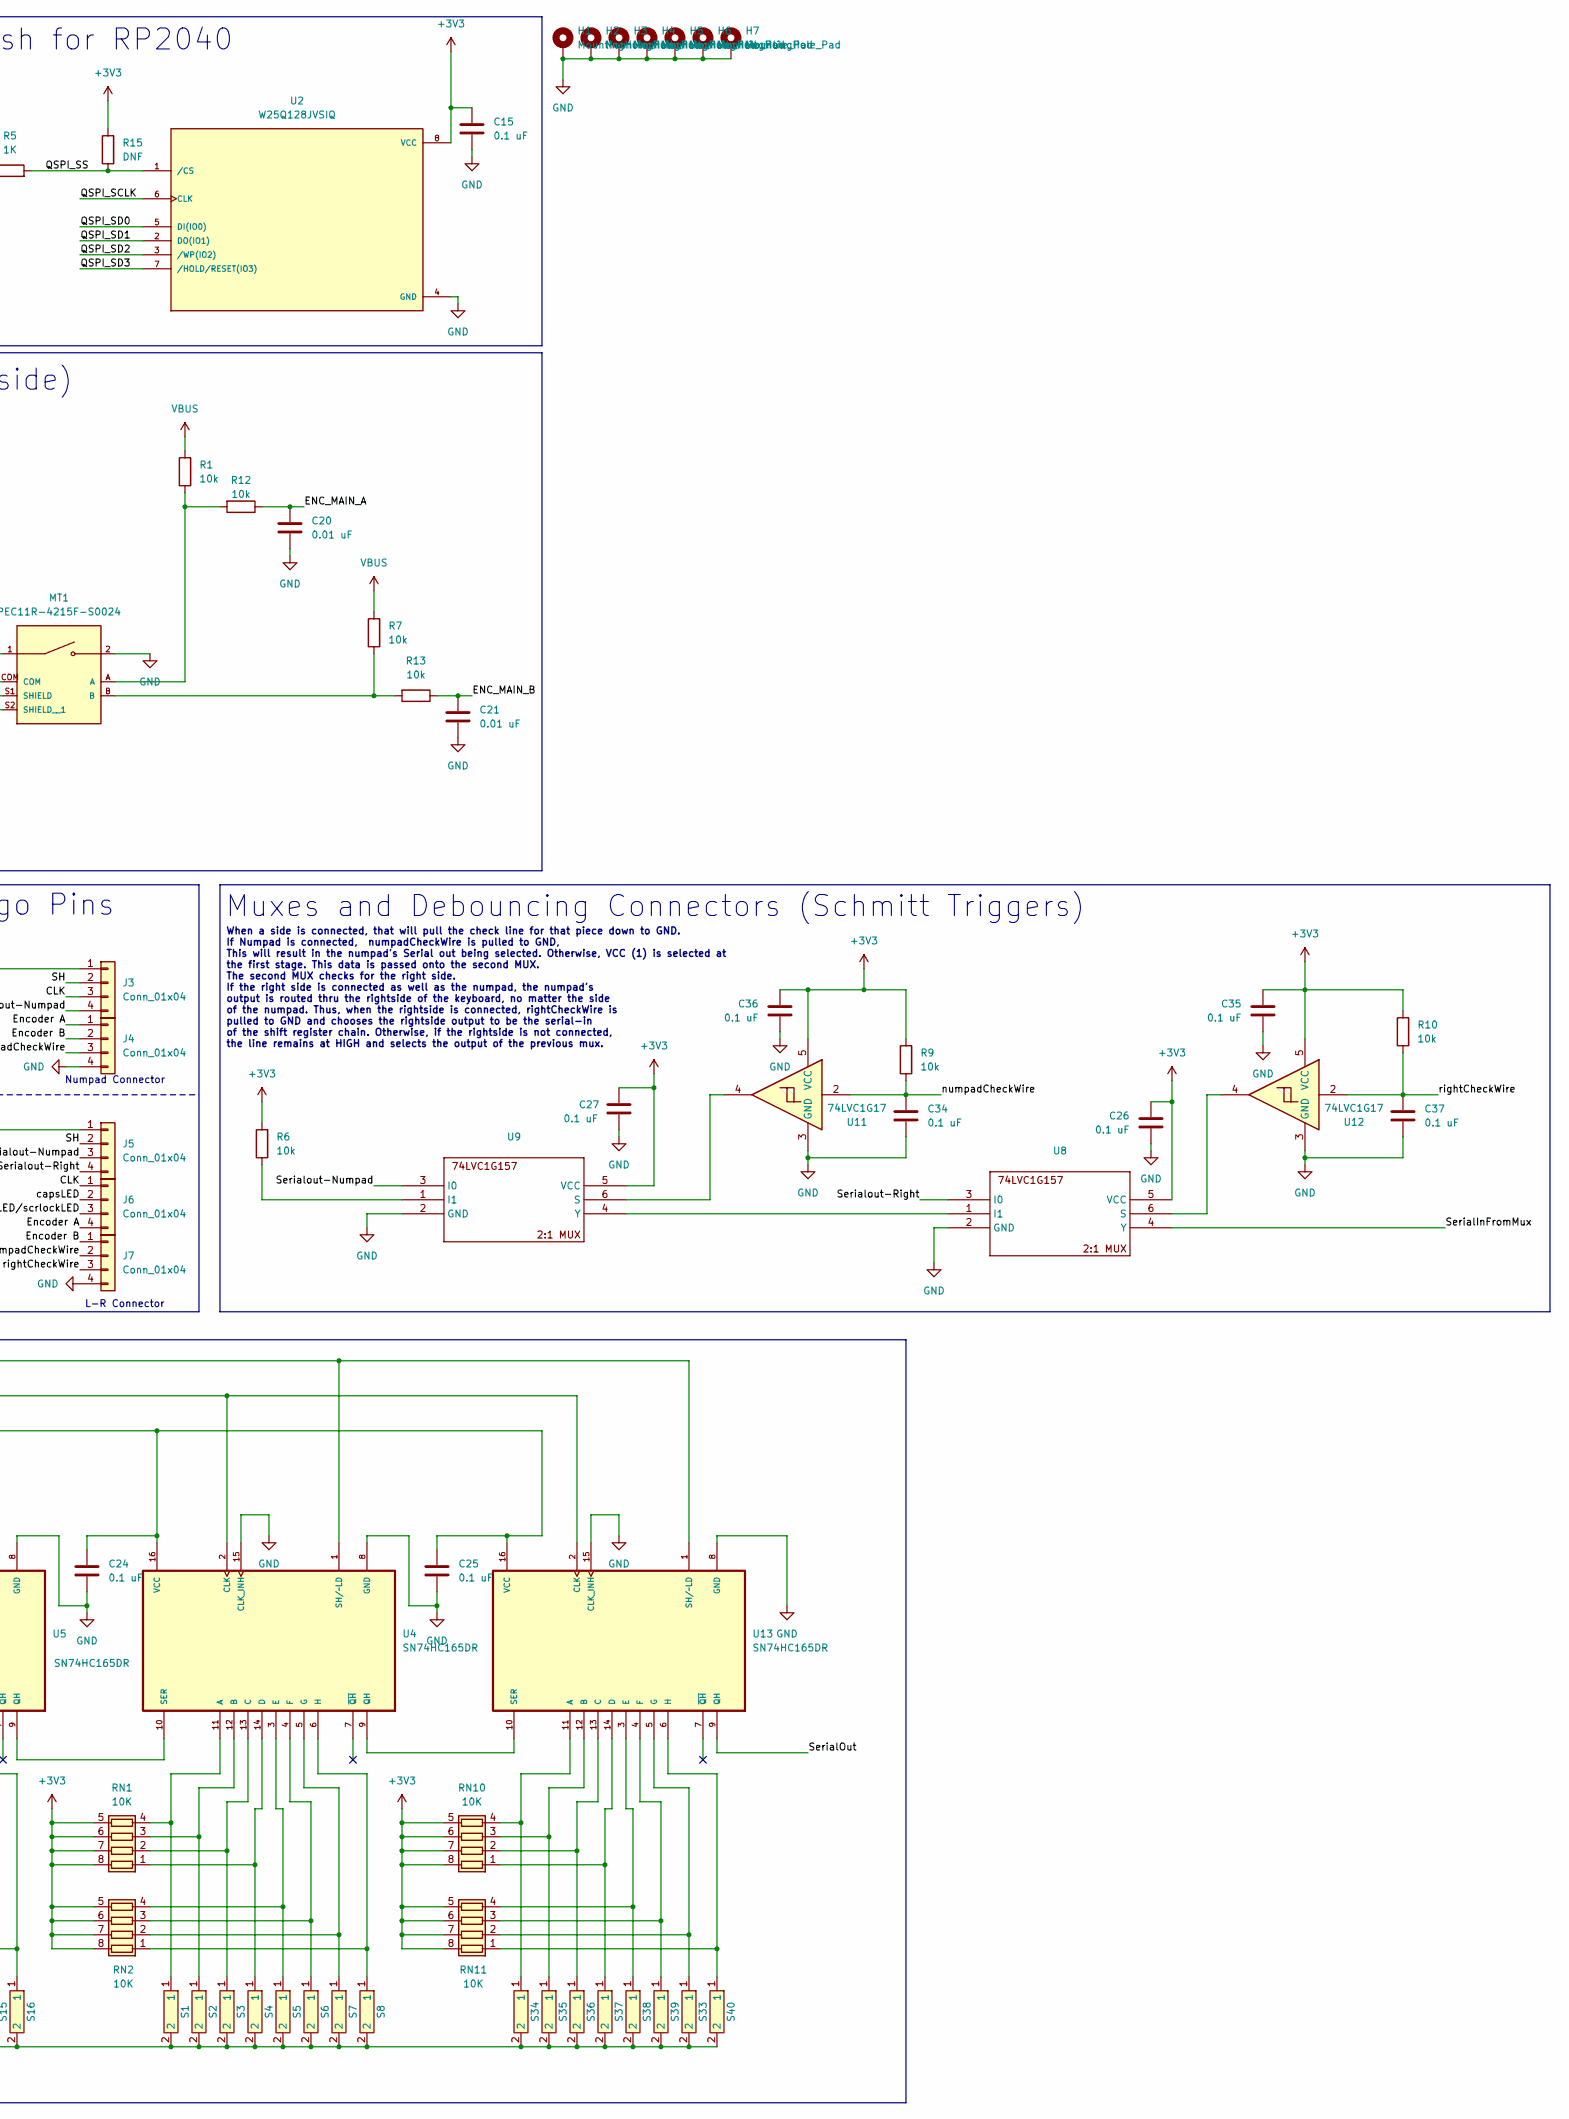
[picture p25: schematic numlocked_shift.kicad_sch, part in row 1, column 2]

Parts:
Brd1: SSD1306; SSD1306-0.91-OLED-4pin-128x32
C1, C2, C3, C4, C5, C6, C7, C8, C9, C10, C18, C22, C23, C24, C25, C26, C27, C28, C30, C34, C35, C36, C37, C38, C39: 0.1 uF; C_0603_1608Metric
C11, C12: 1 uF; C_0603_1608Metric
C13, C14: 15 pF; C_0603_1608Metric
C15: 0.1 uF; C_0603_1608Metric; PARTREV 8/11/2022
C16: 0.47 uF; C_1206_3216Metric
C17: 33 uF; C_1206_3216Metric
C19: NC; C_0603_1608Metric
C20, C21: 0.01 uF; C_0603_1608Metric
C29, C31: 10 uF; C_0603_1608Metric
D2: LED (capslock R); LED_0805_2012Metric_Pad1.15x1.40mm_HandSolder
H1, H2, H3, H4, H5, H6, H7: MountingHole_Pad; MountingHole_2.2mm_M2_Pad
J1, J2: Conn_01x02; PinSocket_1x02_P2.00mm_Vertical
J3, J4, J5, J6, J7: Conn_01x04; Magnetic_Pogo_Pin_4pos
J8: SM04B-SRSS-TB; CONN_SM04B-SRSS-TB_JST
MT1: PEC11R-4215F-S0024; XDCR_PEC11R-4215F-S0024; PARTREV Rev. 09/19
R1, R4, R6, R7, R9, R10, R12, R13, R14: 10k; R_0603_1608Metric
R2, R3: 27; R_0603_1608Metric
R5, R8: 1K; R_0603_1608Metric
R11: 82; R_0603_1608Metric_Pad0.98x0.95mm_HandSolder
R15: DNF; R_0603_1608Metric
RN1, RN2, RN3, RN4, RN5, RN6, RN7, RN8, RN10, RN11: 10K; R_Array_Convex_4x1206
S1, S2, S3, S4, S5, S10, S13, S14, S15, S16, S17, S18, S19, S20, S21, S22, S23, S24, S25, S26, S27, S28, S29, S30, S31, S32, S34, S35, S36, S37, S38, S39, S40: SW_Cherry_Kalih_1.00u
S6: SW_Cherry_Kalih_1.5u
S7: SW_Cherry_Kalih_1.75u
S8: SW_Cherry_Kalih_2.25u
S9, S11, S12: SW_Cherry_Kalih_1.25u
S33: SW_Cherry_Kalih_6.25u
U1: RP2040; QFN-56-1EP_7x7mm_P0.4mm_EP3.2x3.2mm
U2: W25Q128JVSIQ; SOIC127P790X216-8N; PARTREV I
U3: LM3940IMP-3.3/NOPB; SOT-223
U4, U5, U6, U7: SN74HC165DR; SOIC127P600X175-16N
U8, U9: SC-74-6_1.55x2.9mm_P0.95mm
U11, U12: 74LVC1G17; SOT-23-5
U13: SN74HC165DR; SOP-16_3.9x9.9mm_P1.27mm
X1: ABM8-272-T3; Crystal_SMD_Abracon_ABM8AIG-4Pin_3.2x2.5mm

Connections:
+1V1: C1.1, C2.1, C3.1, C12.1, U1.23 (DVDD), U1.45 (VREG_VOUT), U1.50 (DVDD)
+3V3: Brd1.2 (VCC), C4.1, C5.1, C6.1, C7.1, C8.1, C9.1, C10.1, C11.1, C15.1, C17.1, C18.1, C19.1, C22.1, C23.1, C24.1, C25.1, C26.1, C27.1, C35.1, C36.1, C38.1, C39.1, R4.2, R6.2, R9.2, R10.2, R14.2, R15.2, RN1.5 (R4.2), RN1.6 (R3.2), RN1.7 (R2.2), RN1.8 (R1.2), RN2.5 (R4.2), RN2.6 (R3.2), RN2.7 (R2.2), RN2.8 (R1.2), RN3.5 (R4.2), RN3.6 (R3.2), RN3.7 (R2.2), RN3.8 (R1.2), RN4.5 (R4.2), RN4.6 (R3.2), RN4.7 (R2.2), RN4.8 (R1.2), RN5.5 (R4.2), RN5.6 (R3.2), RN5.7 (R2.2), RN5.8 (R1.2), RN6.5 (R4.2), RN6.6 (R3.2), RN6.7 (R2.2), RN6.8 (R1.2), RN7.5 (R4.2), RN7.6 (R3.2), RN7.7 (R2.2), RN7.8 (R1.2), RN8.5 (R4.2), RN8.6 (R3.2), RN8.7 (R2.2), RN8.8 (R1.2), RN10.5 (R4.2), RN10.6 (R3.2), RN10.7 (R2.2), RN10.8 (R1.2), RN11.5 (R4.2), RN11.6 (R3.2), RN11.7 (R2.2), RN11.8 (R1.2), U1.1 (IOVDD), U1.10 (IOVDD), U1.22 (IOVDD), U1.33 (IOVDD), U1.42 (IOVDD), U1.43 (ADC_AVDD), U1.44 (VREG_IN), U1.48 (USB_VDD), U1.49 (IOVDD), U2.8 (VCC), U3.3 (OUT), U4.16 (VCC), U5.16 (VCC), U6.16 (VCC), U7.16 (VCC), U8.5 (VCC), U9.5 (VCC), U11.5 (VCC), U12.5 (VCC), U13.16 (VCC)
/CLK: J3.3, J6.1, U1.14 (GPIO11), U4.2 (CLK), U5.2 (CLK), U6.2 (CLK), U7.2 (CLK), U13.2 (CLK)
/ENC_MAIN_A: C20.1, R12.1, U1.31 (GPIO20)
/ENC_MAIN_B: C21.1, R13.1, U1.30 (GPIO19)
/ENC_MAIN_SW: MT1.1, R14.1, U1.29 (GPIO18)
/Encoder A: J4.1, J6.4, U1.6 (GPIO4)
/Encoder B: J4.2, J7.1, U1.7 (GPIO5)
/QSPI_SCLK: U1.52 (QSPI_SCLK), U2.6 (CLK)
/QSPI_SD0: U1.53 (QSPI_SD0), U2.5 (DI(IO0))
/QSPI_SD1: U1.55 (QSPI_SD1), U2.2 (DO(IO1))
/QSPI_SD2: U1.54 (QSPI_SD2), U2.3 (/WP(IO2))
/QSPI_SD3: U1.51 (QSPI_SD3), U2.7 (/HOLD/RESET(IO3))
/QSPI_SS: R5.2, R15.1, U1.56 (QSPI_SS), U2.1 (/CS)
/SH: J3.2, J5.2, U1.13 (GPIO10), U4.1 (SH/~LD), U5.1 (SH/~LD), U6.1 (SH/~LD), U7.1 (SH/~LD), U13.1 (SH/~LD)
/SSD1306 SCL: Brd1.3 (SCL), U1.35 (GPIO23)
/SSD1306 SDA: Brd1.4 (SDA), U1.34 (GPIO22)
/SWCLK: U1.24 (SWCLK)
/SWD: U1.25 (SWD)
/SerialInFromMux: U7.10 (SER), U8.4 (Y)
/SerialOut: U1.3 (GPIO1), U13.9 (QH)
/Serialout-Numpad: J3.4, J5.3, U9.3 (I0)
/Serialout-Right: J5.4, U8.3 (I0)
/USB_RP2040+: J8.3, R2.1
/USB_RP2040-: J8.2, R3.1
/USB_RP2040_Res+: R2.2, U1.47 (USB_DP)
/USB_RP2040_Res-: R3.2, U1.46 (USB_DM)
/XIN: C13.2, U1.20 (XIN), X1.1
/XOUT: R8.2, U1.21 (XOUT)
/capsLED: J6.2, R11.1, U1.5 (GPIO3)
/numlockLED/scrlockLED: J6.3, U1.4 (GPIO2)
/numpadCheckWire: C34.1, J4.3, J7.2, R9.1, U1.16 (GPIO13), U11.2
/rightCheckWire: C37.1, J7.3, R10.1, U1.15 (GPIO12), U12.2
/~USB BOOT: J2.1, R5.1, U1.2 (GPIO0)
/~reset: J1.1, R4.1, U1.26 (RUN)
GND: Brd1.1 (GND), C1.2, C2.2, C3.2, C4.2, C5.2, C6.2, C7.2, C8.2, C9.2, C10.2, C11.2, C12.2, C13.1, C14.1, C15.2, C16.2, C17.2, C18.2, C19.2, C20.2, C21.2, C22.2, C23.2, C24.2, C25.2, C26.2, C27.2, C28.2, C29.2, C30.2, C31.2, C34.2, C35.2, C36.2, C37.2, C38.2, C39.2, D2.1 (K), H1.1, H2.1, H3.1, H4.1, H5.1, H6.1, H7.1, J1.2, J2.2, J4.4, J7.4, J8.4, MT1.2, MT1.COM, MT1.S1 (SHIELD), MT1.S2 (SHIELD__1), S1.2, S2.2, S3.2, S4.2, S5.2, S6.2, S7.2, S8.2, S9.2, S10.2, S11.2, S12.2, S13.2, S14.2, S15.2, S16.2, S17.2, S18.2, S19.2, S20.2, S21.2, S22.2, S23.2, S24.2, S25.2, S26.2, S27.2, S28.2, S29.2, S30.2, S31.2, S32.2, S33.2, S34.2, S35.2, S36.2, S37.2, S38.2, S39.2, S40.2, U1.19 (TESTEN), U1.57 (GND), U2.4 (GND), U3.2 (GND), U3.4 (GND), U4.8 (GND), U4.15 (CLK_INH), U5.8 (GND), U5.15 (CLK_INH), U6.8 (GND), U6.15 (CLK_INH), U7.8 (GND), U7.15 (CLK_INH), U8.2 (GND), U9.2 (GND), U11.3 (GND), U12.3 (GND), U13.8 (GND), U13.15 (CLK_INH), X1.2, X1.4
unnamed: C14.2, R8.1, X1.3
unnamed: D2.2 (A), R11.2
unnamed: MT1.A, R1.1, R12.2
unnamed: MT1.B, R7.1, R13.2
unnamed: RN1.1 (R1.1), S4.1, U4.14 (D)
unnamed: RN1.2 (R2.1), S3.1, U4.13 (C)
unnamed: RN1.3 (R3.1), S2.1, U4.12 (B)
unnamed: RN1.4 (R4.1), S1.1, U4.11 (A)
unnamed: RN2.1 (R1.1), S8.1, U4.6 (H)
unnamed: RN2.2 (R2.1), S7.1, U4.5 (G)
unnamed: RN2.3 (R3.1), S6.1, U4.4 (F)
unnamed: RN2.4 (R4.1), S5.1, U4.3 (E)
unnamed: RN3.1 (R1.1), S9.1, U5.14 (D)
unnamed: RN3.2 (R2.1), S13.1, U5.13 (C)
unnamed: RN3.3 (R3.1), S10.1, U5.12 (B)
unnamed: RN3.4 (R4.1), S11.1, U5.11 (A)
unnamed: RN4.1 (R1.1), S16.1, U5.6 (H)
unnamed: RN4.2 (R2.1), S15.1, U5.5 (G)
unnamed: RN4.3 (R3.1), S14.1, U5.4 (F)
unnamed: RN4.4 (R4.1), S12.1, U5.3 (E)
unnamed: RN5.1 (R1.1), S20.1, U6.14 (D)
unnamed: RN5.2 (R2.1), S19.1, U6.13 (C)
unnamed: RN5.3 (R3.1), S18.1, U6.12 (B)
unnamed: RN5.4 (R4.1), S17.1, U6.11 (A)
unnamed: RN6.1 (R1.1), S24.1, U6.6 (H)
unnamed: RN6.2 (R2.1), S23.1, U6.5 (G)
unnamed: RN6.3 (R3.1), S22.1, U6.4 (F)
unnamed: RN6.4 (R4.1), S21.1, U6.3 (E)
unnamed: RN7.1 (R1.1), S28.1, U7.14 (D)
unnamed: RN7.2 (R2.1), S27.1, U7.13 (C)
unnamed: RN7.3 (R3.1), S26.1, U7.12 (B)
unnamed: RN7.4 (R4.1), S25.1, U7.11 (A)
unnamed: RN8.1 (R1.1), S32.1, U7.6 (H)
unnamed: RN8.2 (R2.1), S31.1, U7.5 (G)
unnamed: RN8.3 (R3.1), S30.1, U7.4 (F)
unnamed: RN8.4 (R4.1), S29.1, U7.3 (E)
unnamed: RN10.1 (R1.1), S37.1, U13.14 (D)
unnamed: RN10.2 (R2.1), S36.1, U13.13 (C)
unnamed: RN10.3 (R3.1), S35.1, U13.12 (B)
unnamed: RN10.4 (R4.1), S34.1, U13.11 (A)
unnamed: RN11.1 (R1.1), S40.1, U13.6 (H)
unnamed: RN11.2 (R2.1), S33.1, U13.5 (G)
unnamed: RN11.3 (R3.1), S39.1, U13.4 (F)
unnamed: RN11.4 (R4.1), S38.1, U13.3 (E)
unnamed: U4.10 (SER), U5.9 (QH)
unnamed: U5.10 (SER), U6.9 (QH)
unnamed: U6.10 (SER), U7.9 (QH)
unnamed: U8.1 (I1), U9.4 (Y)
unnamed: U8.6 (S), U12.4
unnamed: R6.1, U9.1 (I1)
unnamed: U9.6 (S), U11.4
unnamed: U4.9 (QH), U13.10 (SER)
VBUS: C16.1, C28.1, C29.1, C30.1, C31.1, J3.1, J5.1, J8.1, R1.2, R7.2, U3.1 (IN)

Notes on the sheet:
When a side is connected, that will pull the check line for that piece down to GND. If Numpad is connected, numpadCheckWire is pulled to GND, This will result in the numpad's Serial out being selected. Otherwise, VCC (1) is selected at the first stage. This data is passed onto the second MUX. The s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
Power
L-R Connector
Using I2C1 SDA on GPIO22, I2C1 SCL on GPIO23
Quad SPI Flash for RP2040
Muxes and Debouncing Connectors (Schmitt Triggers)
Using I2C0 SDA on GPIO4, I2C0 SCL on GPIO5
Numpad Connector
OLED
Capslock LED
Pull Ups located on OLED PCB.
Shift register left side keyboard inputs
RP2040
Encoder (leftside)
To USB Hub Board (FFC)
Magnetic Pogo Pins

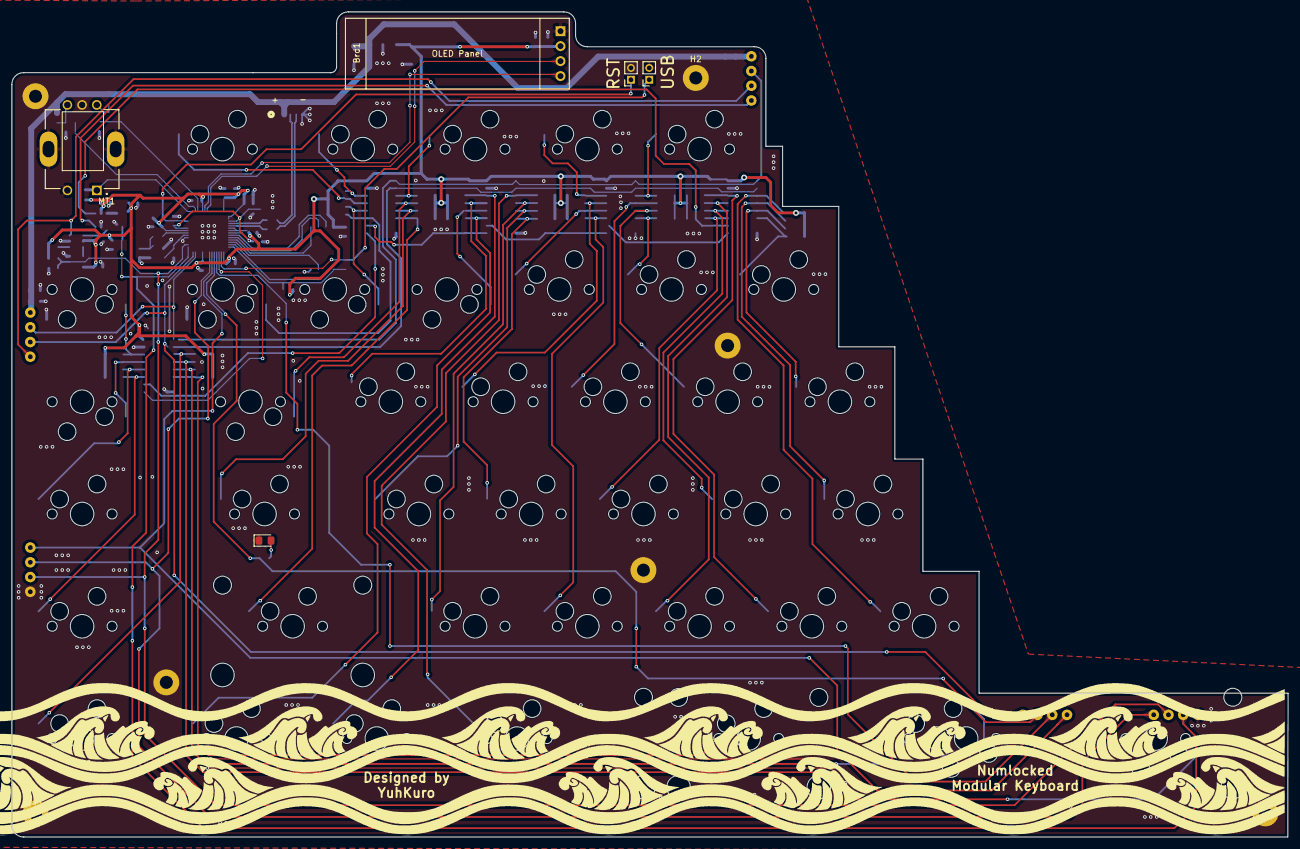
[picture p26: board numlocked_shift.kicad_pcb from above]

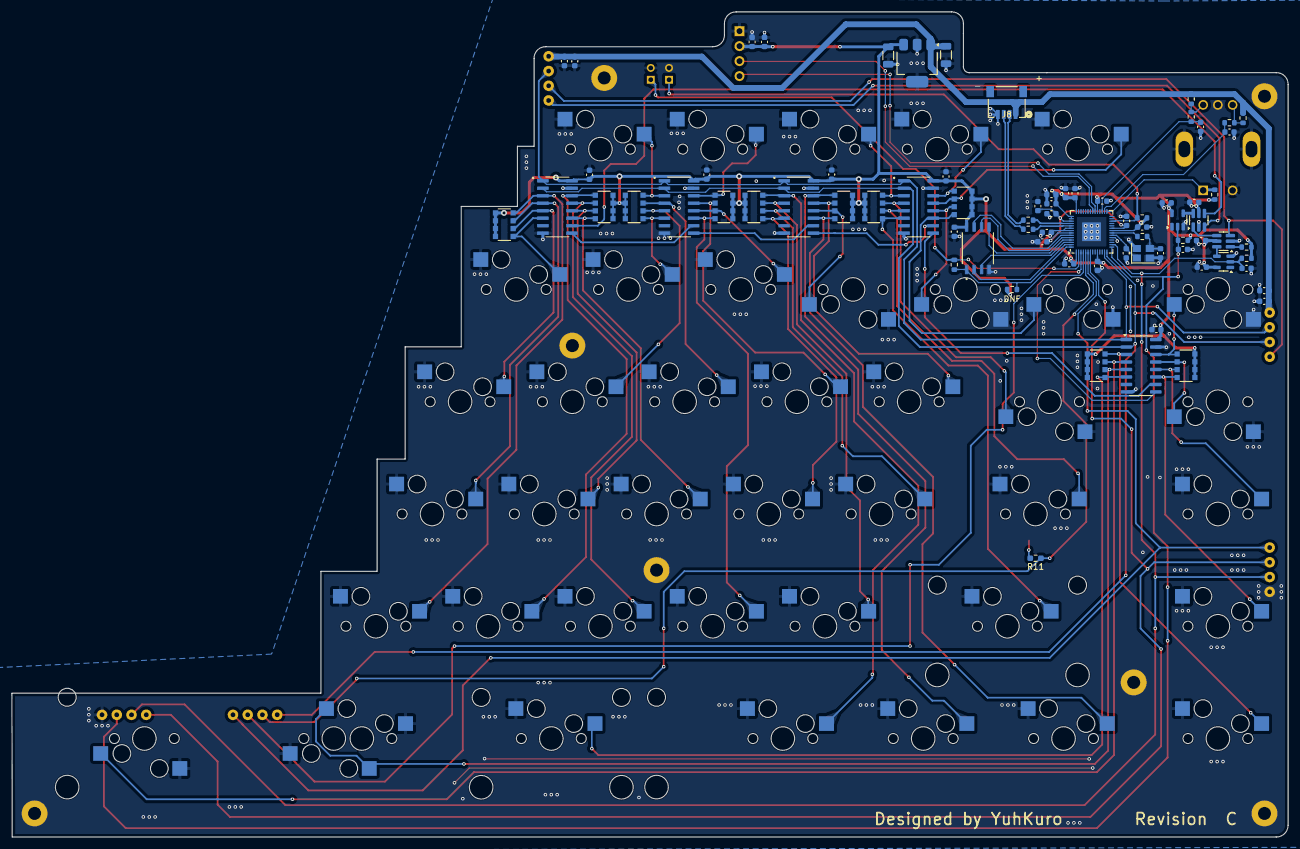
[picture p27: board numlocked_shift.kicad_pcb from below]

Board: 4 copper layers, 216.5 x 140.0 mm, 133 parts (78 on the bottom side), 87 nets.

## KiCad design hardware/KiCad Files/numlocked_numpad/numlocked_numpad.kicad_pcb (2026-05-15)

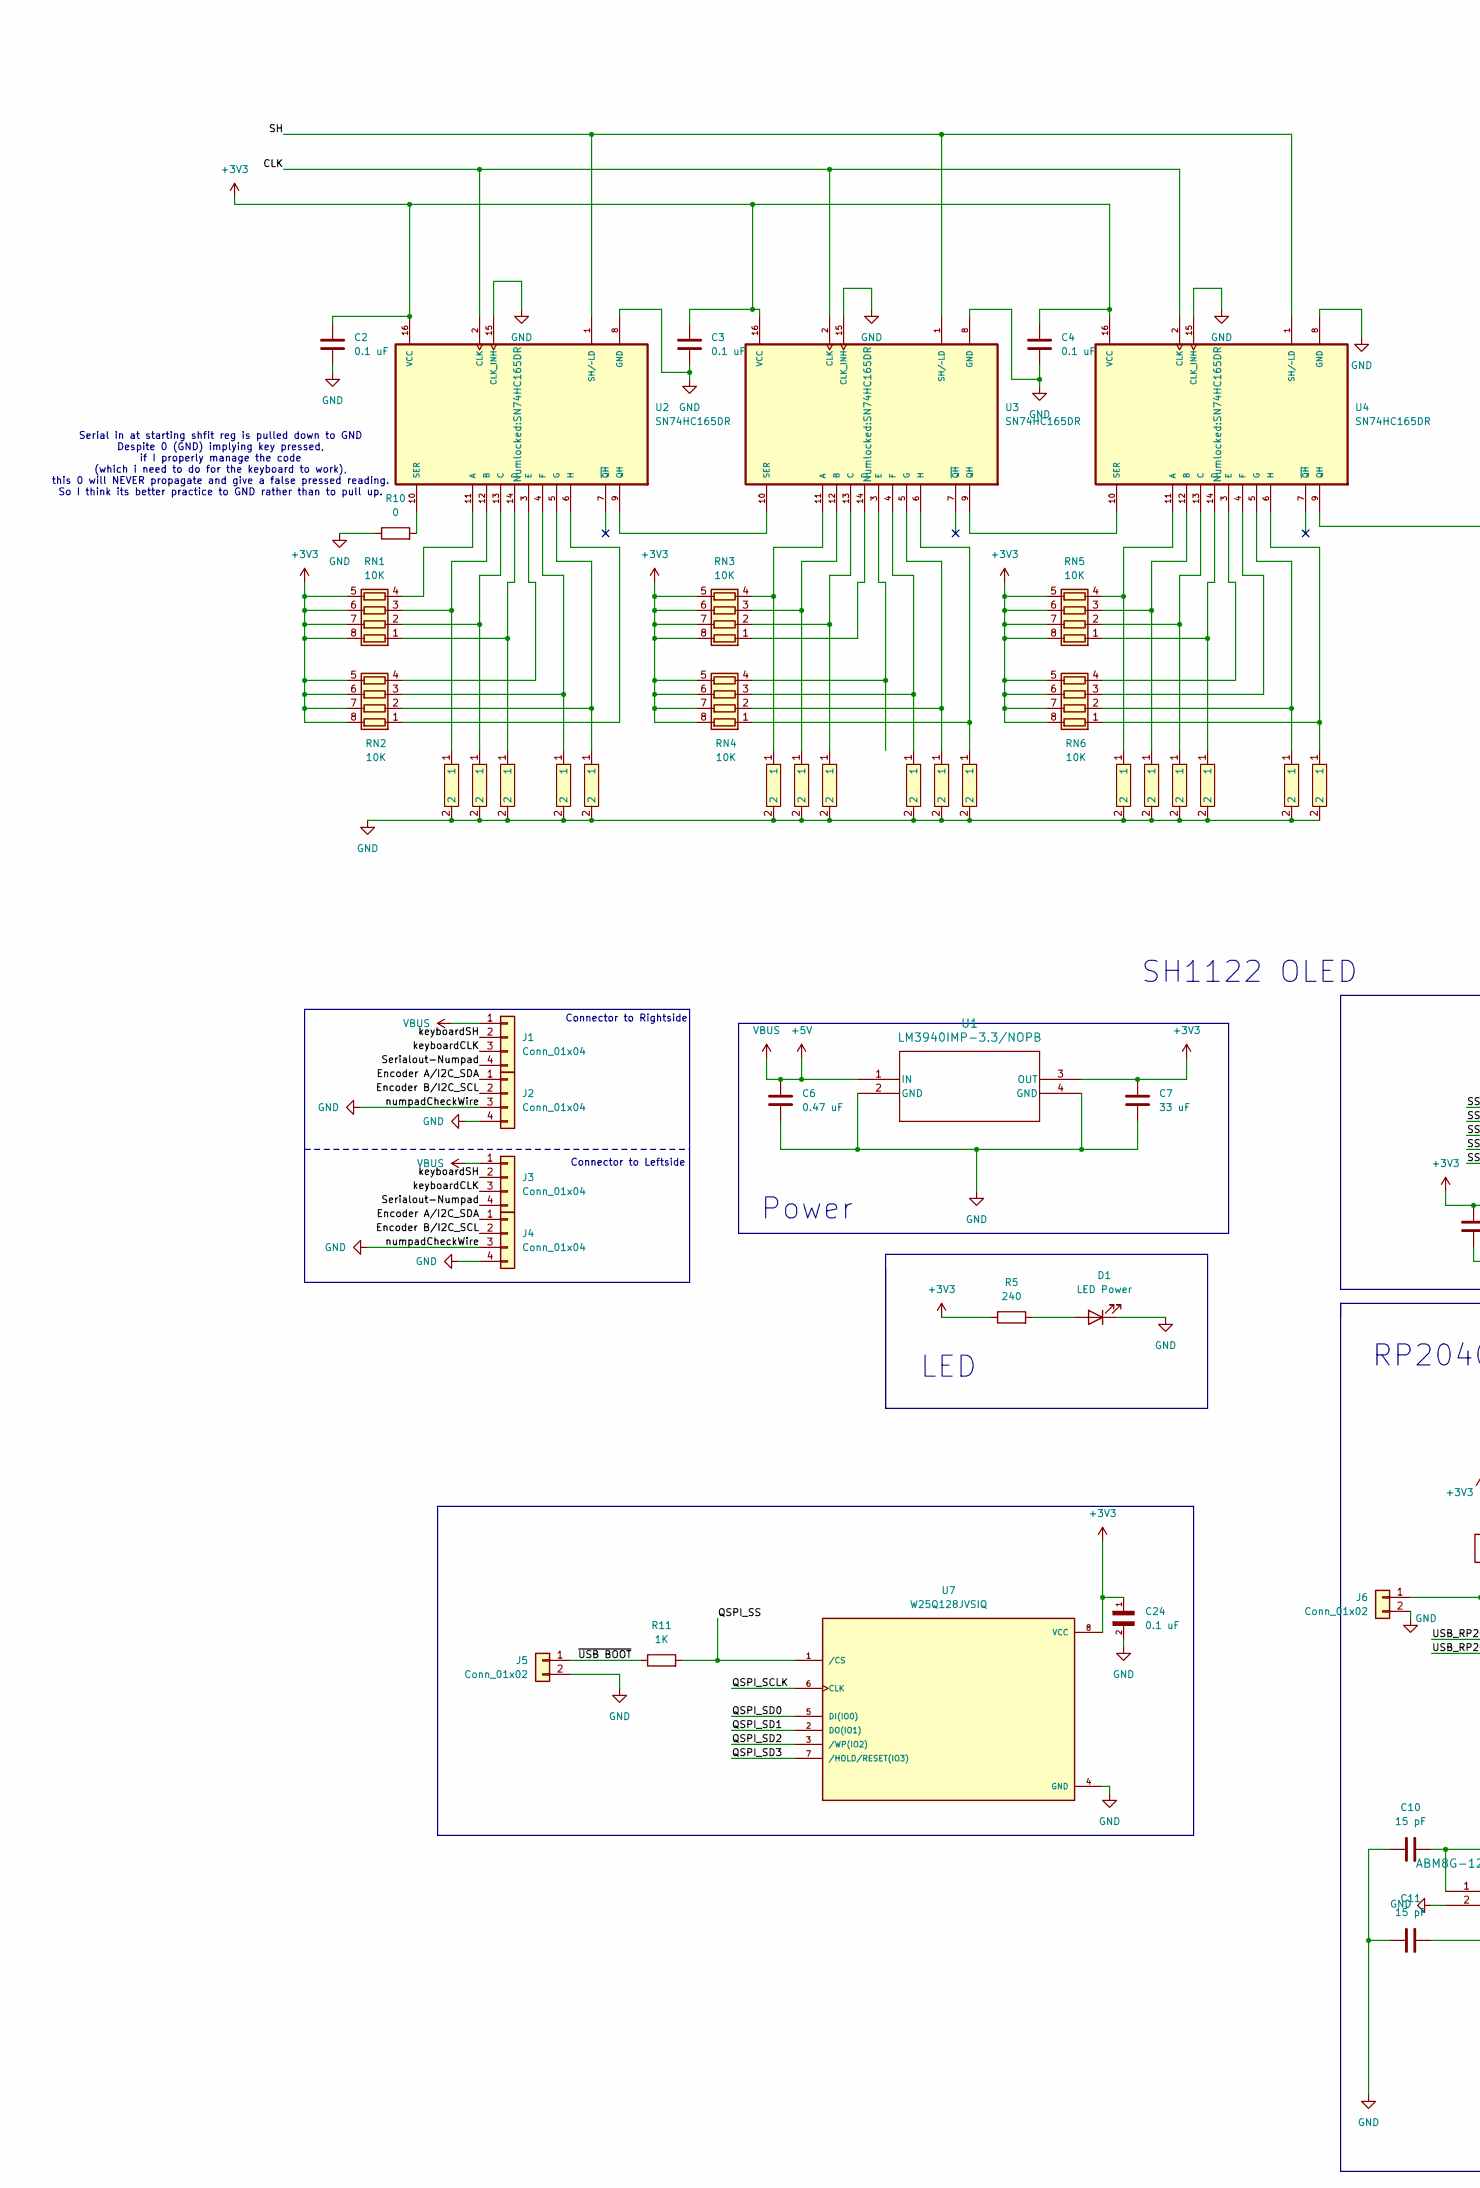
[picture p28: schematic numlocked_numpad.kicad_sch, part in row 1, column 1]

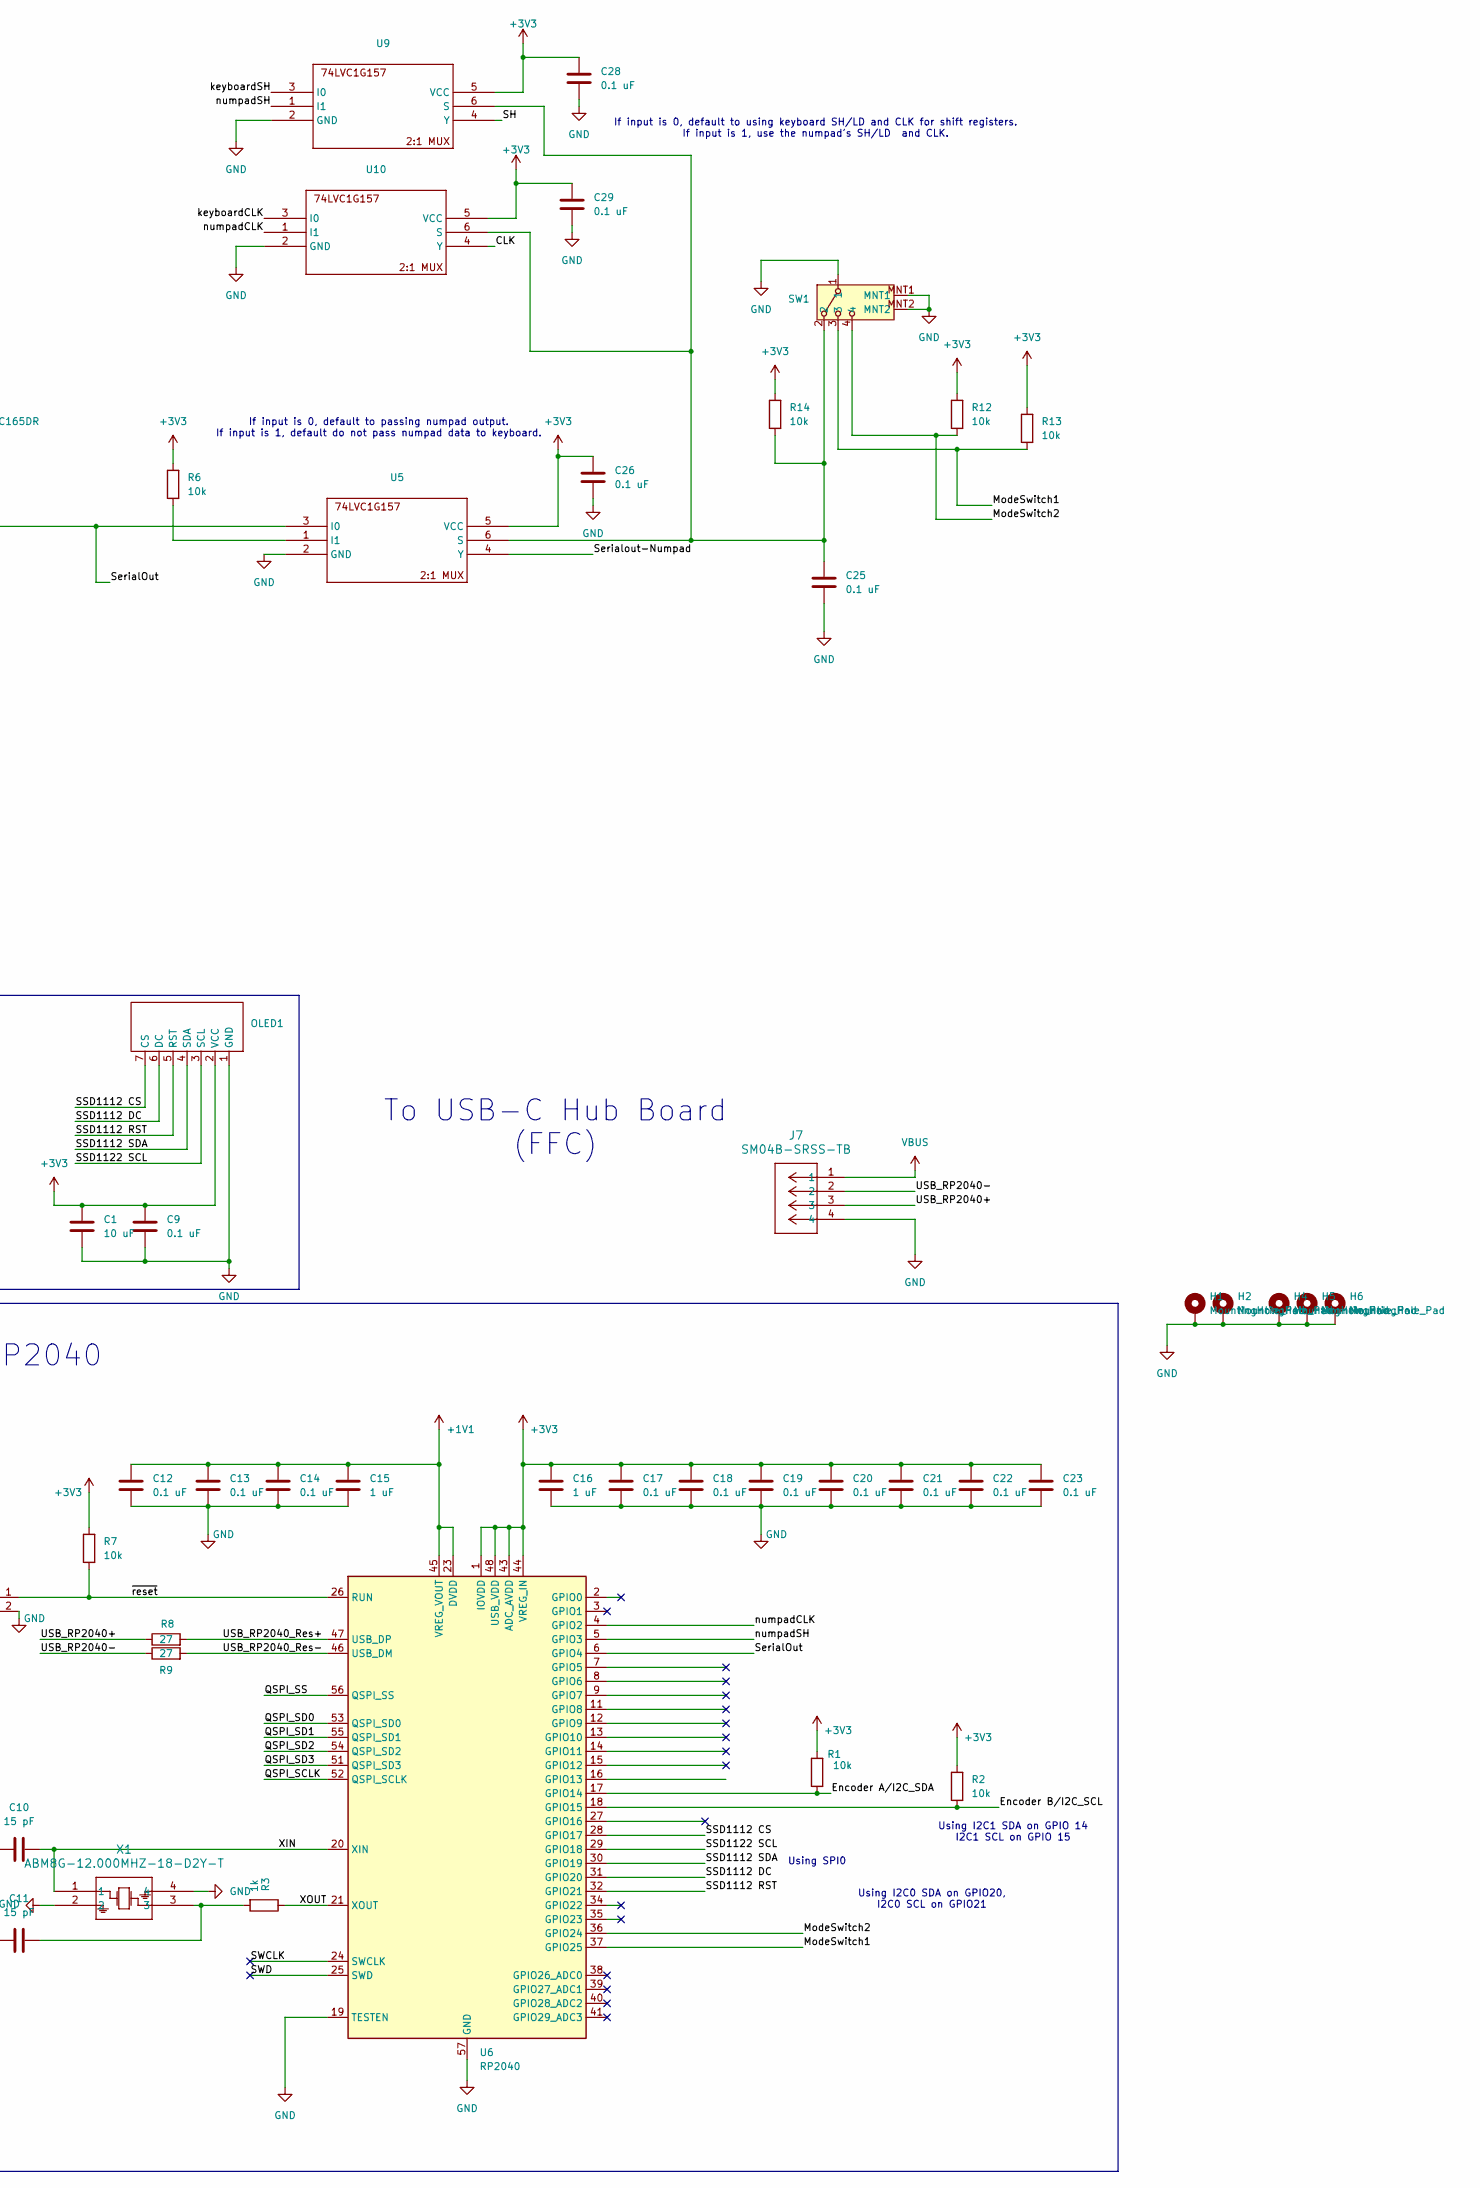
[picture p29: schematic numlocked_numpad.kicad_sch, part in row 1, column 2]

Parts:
C1: 10 uF; C_0603_1608Metric
C2, C3, C4, C9, C12, C13, C14, C17, C18, C19, C20, C21, C22, C23, C25, C26, C28, C29: 0.1 uF; C_0603_1608Metric
C6: 0.47 uF; C_1206_3216Metric
C7: 33 uF; C_1206_3216Metric
C10, C11: 15 pF; C_0603_1608Metric
C15, C16: 1 uF; C_0603_1608Metric
C24: 0.1 uF; C_0603_1608Metric; PARTREV 8/11/2022
D1: LED Power; LED_0603_1608Metric
H1, H2, H4, H5, H6: MountingHole_Pad; MountingHole_2.2mm_M2_Pad
J1, J2, J3, J4: Conn_01x04; Magnetic_Pogo_Pin_4pos
J5, J6: Conn_01x02; PinSocket_1x02_P2.00mm_Vertical
J7: SM04B-SRSS-TB; CONN_SM04B-SRSS-TB_JST
OLED1: PinSocket_1x07_P2.54mm_Vertical
R1, R2, R6, R7, R12, R13, R14: 10k; R_0603_1608Metric
R3: 1k; R_0603_1608Metric
R5: 240; R_0603_1608Metric
R8, R9: 27; R_0603_1608Metric
R10: 0; R_0603_1608Metric
R11: 1K; R_0603_1608Metric
RN1, RN2, RN3, RN4, RN5, RN6: 10K; R_Array_Convex_4x1206
S1, S2, S3, S6, S8, S9, S10, S11, S12, S14, S16, S17, S18, S19: SW_Cherry_Kalih_1.00u
S7: SW_Cherry_Kalih_2.00u
S15, S20: SW_Cherry_Kalih_2.00u_vert
SW1: SK13D07VG4
U1: LM3940IMP-3.3/NOPB; SOT-223
U2, U3, U4: SN74HC165DR
U5, U9, U10: SC-74-6_1.55x2.9mm_P0.95mm
U6: RP2040; QFN-56-1EP_7x7mm_P0.4mm_EP3.2x3.2mm
U7: W25Q128JVSIQ; SOIC_128JVSIQ_WIN; PARTREV I
X1: ABM8G-12.000MHZ-18-D2Y-T; Crystal_SMD_Abracon_ABM8AIG-4Pin_3.2x2.5mm

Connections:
+1V1: C12.1, C13.1, C14.1, C15.1, U6.23 (DVDD), U6.45 (VREG_VOUT), U6.50 (DVDD)
+3V3: C1.1, C2.1, C3.1, C4.1, C7.1, C9.1, C16.1, C17.1, C18.1, C19.1, C20.1, C21.1, C22.1, C23.1, C24.1, C26.1, C28.1, C29.1, OLED1.2 (VCC), R1.2, R2.2, R5.1, R6.2, R7.2, R12.2, R13.2, R14.2, RN1.5 (R4.2), RN1.6 (R3.2), RN1.7 (R2.2), RN1.8 (R1.2), RN2.5 (R4.2), RN2.6 (R3.2), RN2.7 (R2.2), RN2.8 (R1.2), RN3.5 (R4.2), RN3.6 (R3.2), RN3.7 (R2.2), RN3.8 (R1.2), RN4.5 (R4.2), RN4.6 (R3.2), RN4.7 (R2.2), RN4.8 (R1.2), RN5.5 (R4.2), RN5.6 (R3.2), RN5.7 (R2.2), RN5.8 (R1.2), RN6.5 (R4.2), RN6.6 (R3.2), RN6.7 (R2.2), RN6.8 (R1.2), U1.3 (OUT), U2.16 (VCC), U3.16 (VCC), U4.16 (VCC), U5.5 (VCC), U6.1 (IOVDD), U6.10 (IOVDD), U6.22 (IOVDD), U6.33 (IOVDD), U6.42 (IOVDD), U6.43 (ADC_AVDD), U6.44 (VREG_IN), U6.48 (USB_VDD), U6.49 (IOVDD), U7.8 (VCC), U9.5 (VCC), U10.5 (VCC)
+5V: C6.1, J1.1, J3.1, J7.1, U1.1 (IN)
/CLK: U2.2 (CLK), U3.2 (CLK), U4.2 (CLK), U10.4 (Y)
/Encoder A/I2C_SDA: J2.1, J4.1, R1.1, U6.17 (GPIO14)
/Encoder B/I2C_SCL: J2.2, J4.2, R2.1, U6.18 (GPIO15)
/ModeSwitch1: R13.1, SW1.3, U6.37 (GPIO25)
/ModeSwitch2: R12.1, SW1.4, U6.36 (GPIO24)
/QSPI_SCLK: U6.52 (QSPI_SCLK), U7.6 (CLK)
/QSPI_SD0: U6.53 (QSPI_SD0), U7.5 (DI(IO0))
/QSPI_SD1: U6.55 (QSPI_SD1), U7.2 (DO(IO1))
/QSPI_SD2: U6.54 (QSPI_SD2), U7.3 (/WP(IO2))
/QSPI_SD3: U6.51 (QSPI_SD3), U7.7 (/HOLD/RESET(IO3))
/QSPI_SS: R11.2, U6.56 (QSPI_SS), U7.1 (/CS)
/SH: U2.1 (SH/~LD), U3.1 (SH/~LD), U4.1 (SH/~LD), U9.4 (Y)
/SSD1112 CS: OLED1.7 (CS), U6.28 (GPIO17)
/SSD1112 DC: OLED1.6 (DC), U6.31 (GPIO20)
/SSD1112 RST: OLED1.5 (RST), U6.32 (GPIO21)
/SSD1112 SDA: OLED1.4 (SDA), U6.30 (GPIO19)
/SSD1122 SCL: OLED1.3 (SCL), U6.29 (GPIO18)
/SWCLK: U6.24 (SWCLK)
/SWD: U6.25 (SWD)
/SerialOut: U4.9 (QH), U5.3 (I0), U6.6 (GPIO4)
/Serialout-Numpad: J1.4, J3.4, U5.4 (Y)
/USB_RP2040+: J7.3, R8.1
/USB_RP2040-: J7.2, R9.1
/USB_RP2040_Res+: R8.2, U6.47 (USB_DP)
/USB_RP2040_Res-: R9.2, U6.46 (USB_DM)
/XIN: C10.2, U6.20 (XIN), X1.1
/XOUT: R3.1, U6.21 (XOUT)
/keyboardCLK: J1.3, J3.3, U10.3 (I0)
/keyboardSH: J1.2, J3.2, U9.3 (I0)
/numpadCLK: U6.4 (GPIO2), U10.1 (I1)
/numpadSH: U6.5 (GPIO3), U9.1 (I1)
/~USB BOOT: J5.1, R11.1
/~reset: J6.1, R7.1, U6.26 (RUN)
GND: C1.2, C2.2, C3.2, C4.2, C6.2, C7.2, C9.2, C10.1, C11.1, C12.2, C13.2, C14.2, C15.2, C16.2, C17.2, C18.2, C19.2, C20.2, C21.2, C22.2, C23.2, C24.2, C25.2, C26.2, C28.2, C29.2, D1.1 (K), H1.1, H2.1, H4.1, H5.1, H6.1, J2.3, J2.4, J4.3, J4.4, J5.2, J6.2, J7.4, OLED1.1 (GND), R10.1, S1.2, S2.2, S3.2, S6.2, S7.2, S8.2, S9.2, S10.2, S11.2, S12.2, S14.2, S15.2, S16.2, S17.2, S18.2, S19.2, S20.2, SW1.1, SW1.MNT1, SW1.MNT2, U1.2 (GND), U1.4 (GND), U2.8 (GND), U2.15 (CLK_INH), U3.8 (GND), U3.15 (CLK_INH), U4.8 (GND), U4.15 (CLK_INH), U5.2 (GND), U6.19 (TESTEN), U6.57 (GND), U7.4 (GND), U9.2 (GND), U10.2 (GND), X1.2, X1.4
unnamed: C11.2, R3.2, X1.3
unnamed: D1.2 (A), R5.2
unnamed: RN1.1 (R1.1), S1.1, U2.14 (D)
unnamed: RN1.2 (R2.1), S3.1, U2.13 (C)
unnamed: RN1.3 (R3.1), S2.1, U2.12 (B)
unnamed: RN1.4 (R4.1), U2.11 (A)
unnamed: RN2.1 (R1.1), U2.6 (H)
unnamed: RN2.2 (R2.1), S7.1, U2.5 (G)
unnamed: RN2.3 (R3.1), S6.1, U2.4 (F)
unnamed: RN2.4 (R4.1), U2.3 (E)
unnamed: RN3.1 (R1.1), U3.14 (D)
unnamed: RN3.2 (R2.1), S11.1, U3.13 (C)
unnamed: RN3.3 (R3.1), S10.1, U3.12 (B)
unnamed: RN3.4 (R4.1), S9.1, U3.11 (A)
unnamed: RN4.1 (R1.1), S8.1, U3.6 (H)
unnamed: RN4.2 (R2.1), S12.1, U3.5 (G)
unnamed: RN4.3 (R3.1), S14.1, U3.4 (F)
unnamed: RN4.4 (R4.1), U3.3 (E)
unnamed: RN5.1 (R1.1), S20.1, U4.14 (D)
unnamed: RN5.2 (R2.1), S19.1, U4.13 (C)
unnamed: RN5.3 (R3.1), S18.1, U4.12 (B)
unnamed: RN5.4 (R4.1), S17.1, U4.11 (A)
unnamed: RN6.1 (R1.1), S16.1, U4.6 (H)
unnamed: RN6.2 (R2.1), S15.1, U4.5 (G)
unnamed: RN6.3 (R3.1), U4.4 (F)
unnamed: RN6.4 (R4.1), U4.3 (E)
unnamed: U2.9 (QH), U3.10 (SER)
unnamed: R10.2, U2.10 (SER)
unnamed: U3.9 (QH), U4.10 (SER)
unnamed: R6.1, U5.1 (I1)
unnamed: C25.1, R14.1, SW1.2, U5.6 (S), U9.6 (S), U10.6 (S)

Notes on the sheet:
Power
Connector to Leftside
Serial in at starting shfit reg is pulled down to GND Despite 0 (GND) implying key pressed, if I properly manage the code (which i need to do for the keyboard to work), this 0 will NEVER propagate and give a false pressed reading. So I think its better practice to GND rather than to pull up.
SH1122 OLED
RP2040
If input is 0, default to using keyboard SH/LD and CLK for shift registers. If input is 1, use the numpad's SH/LD and CLK.
LED
Using SPI0
To USB-C Hub Board (FFC)
Using I2C0 SDA on GPIO20, I2C0 SCL on GPIO21
Using I2C1 SDA on GPIO 14 I2C1 SCL on GPIO 15
Connector to Rightside
If input is 0, default to passing numpad output. If input is 1, default do not pass numpad data to keyboard.

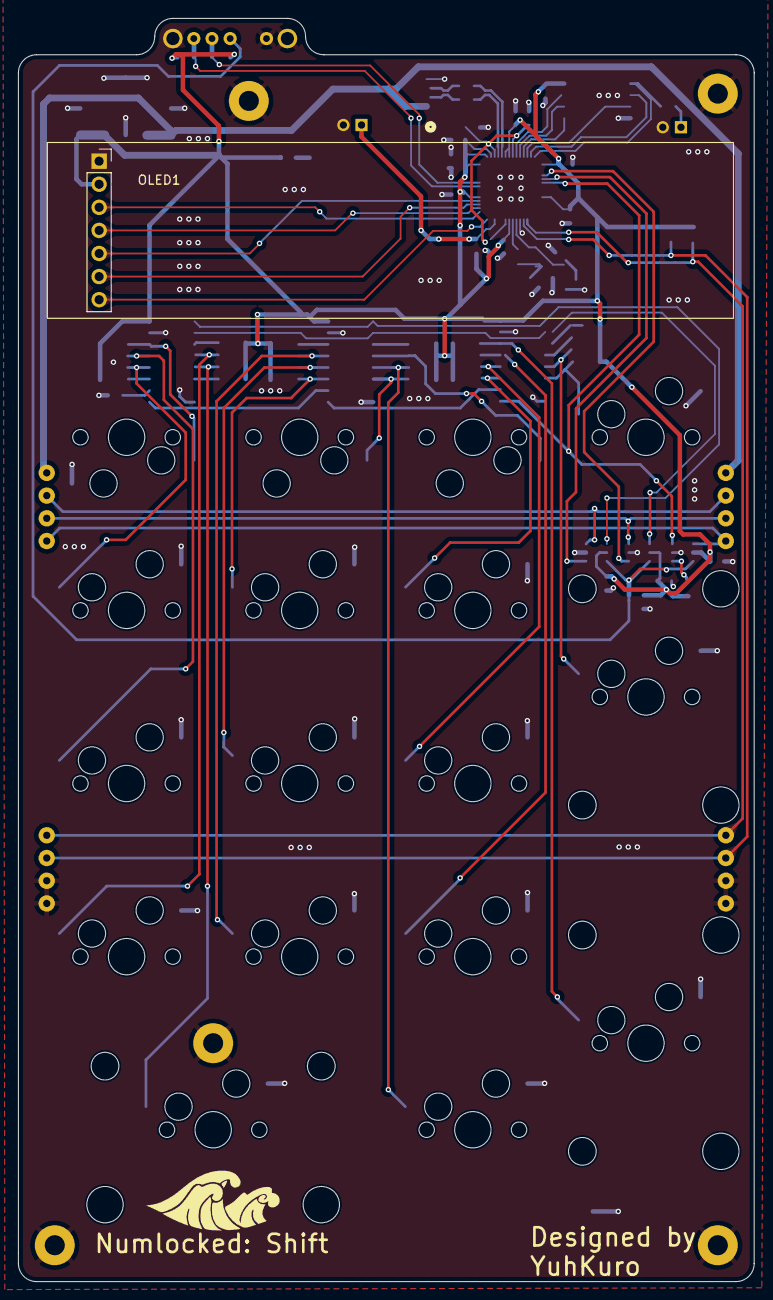
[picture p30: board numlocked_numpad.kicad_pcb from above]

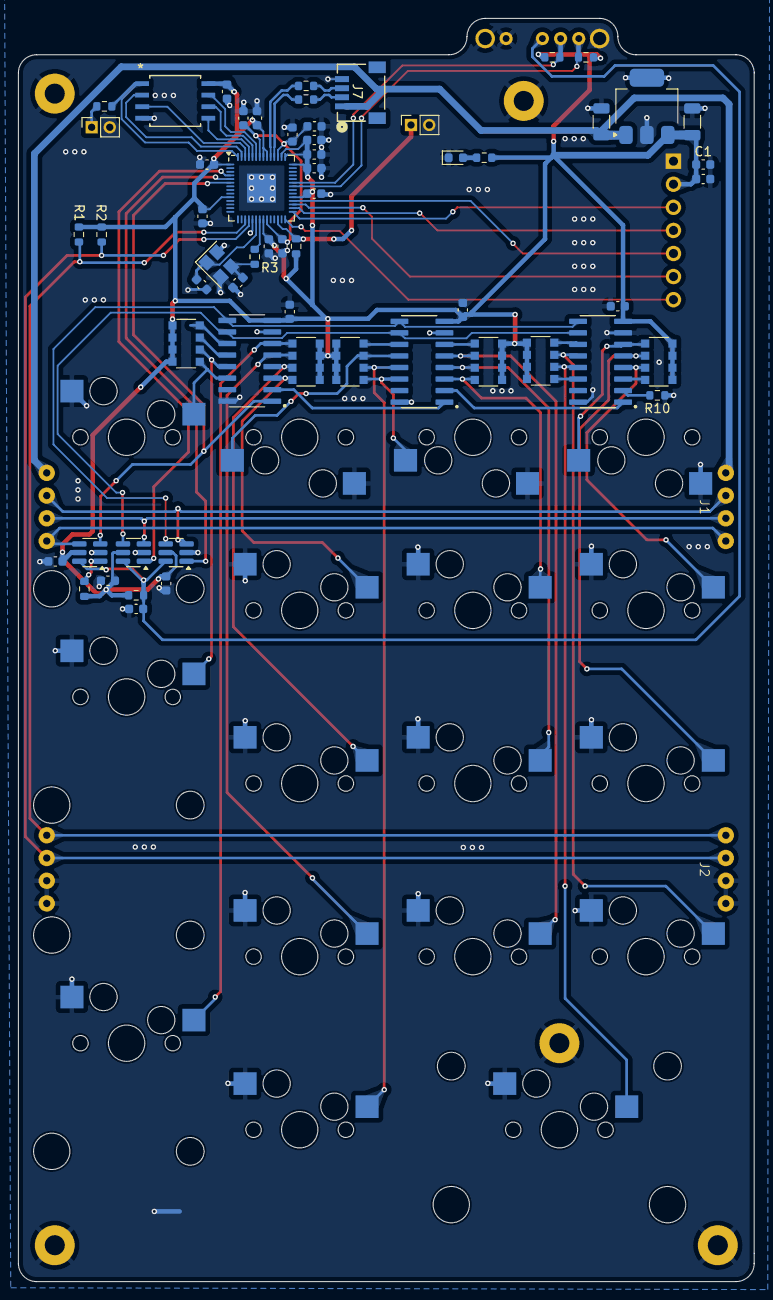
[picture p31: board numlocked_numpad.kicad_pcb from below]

Board: 4 copper layers, 81.0 x 139.0 mm, 87 parts (61 on the bottom side), 66 nets.

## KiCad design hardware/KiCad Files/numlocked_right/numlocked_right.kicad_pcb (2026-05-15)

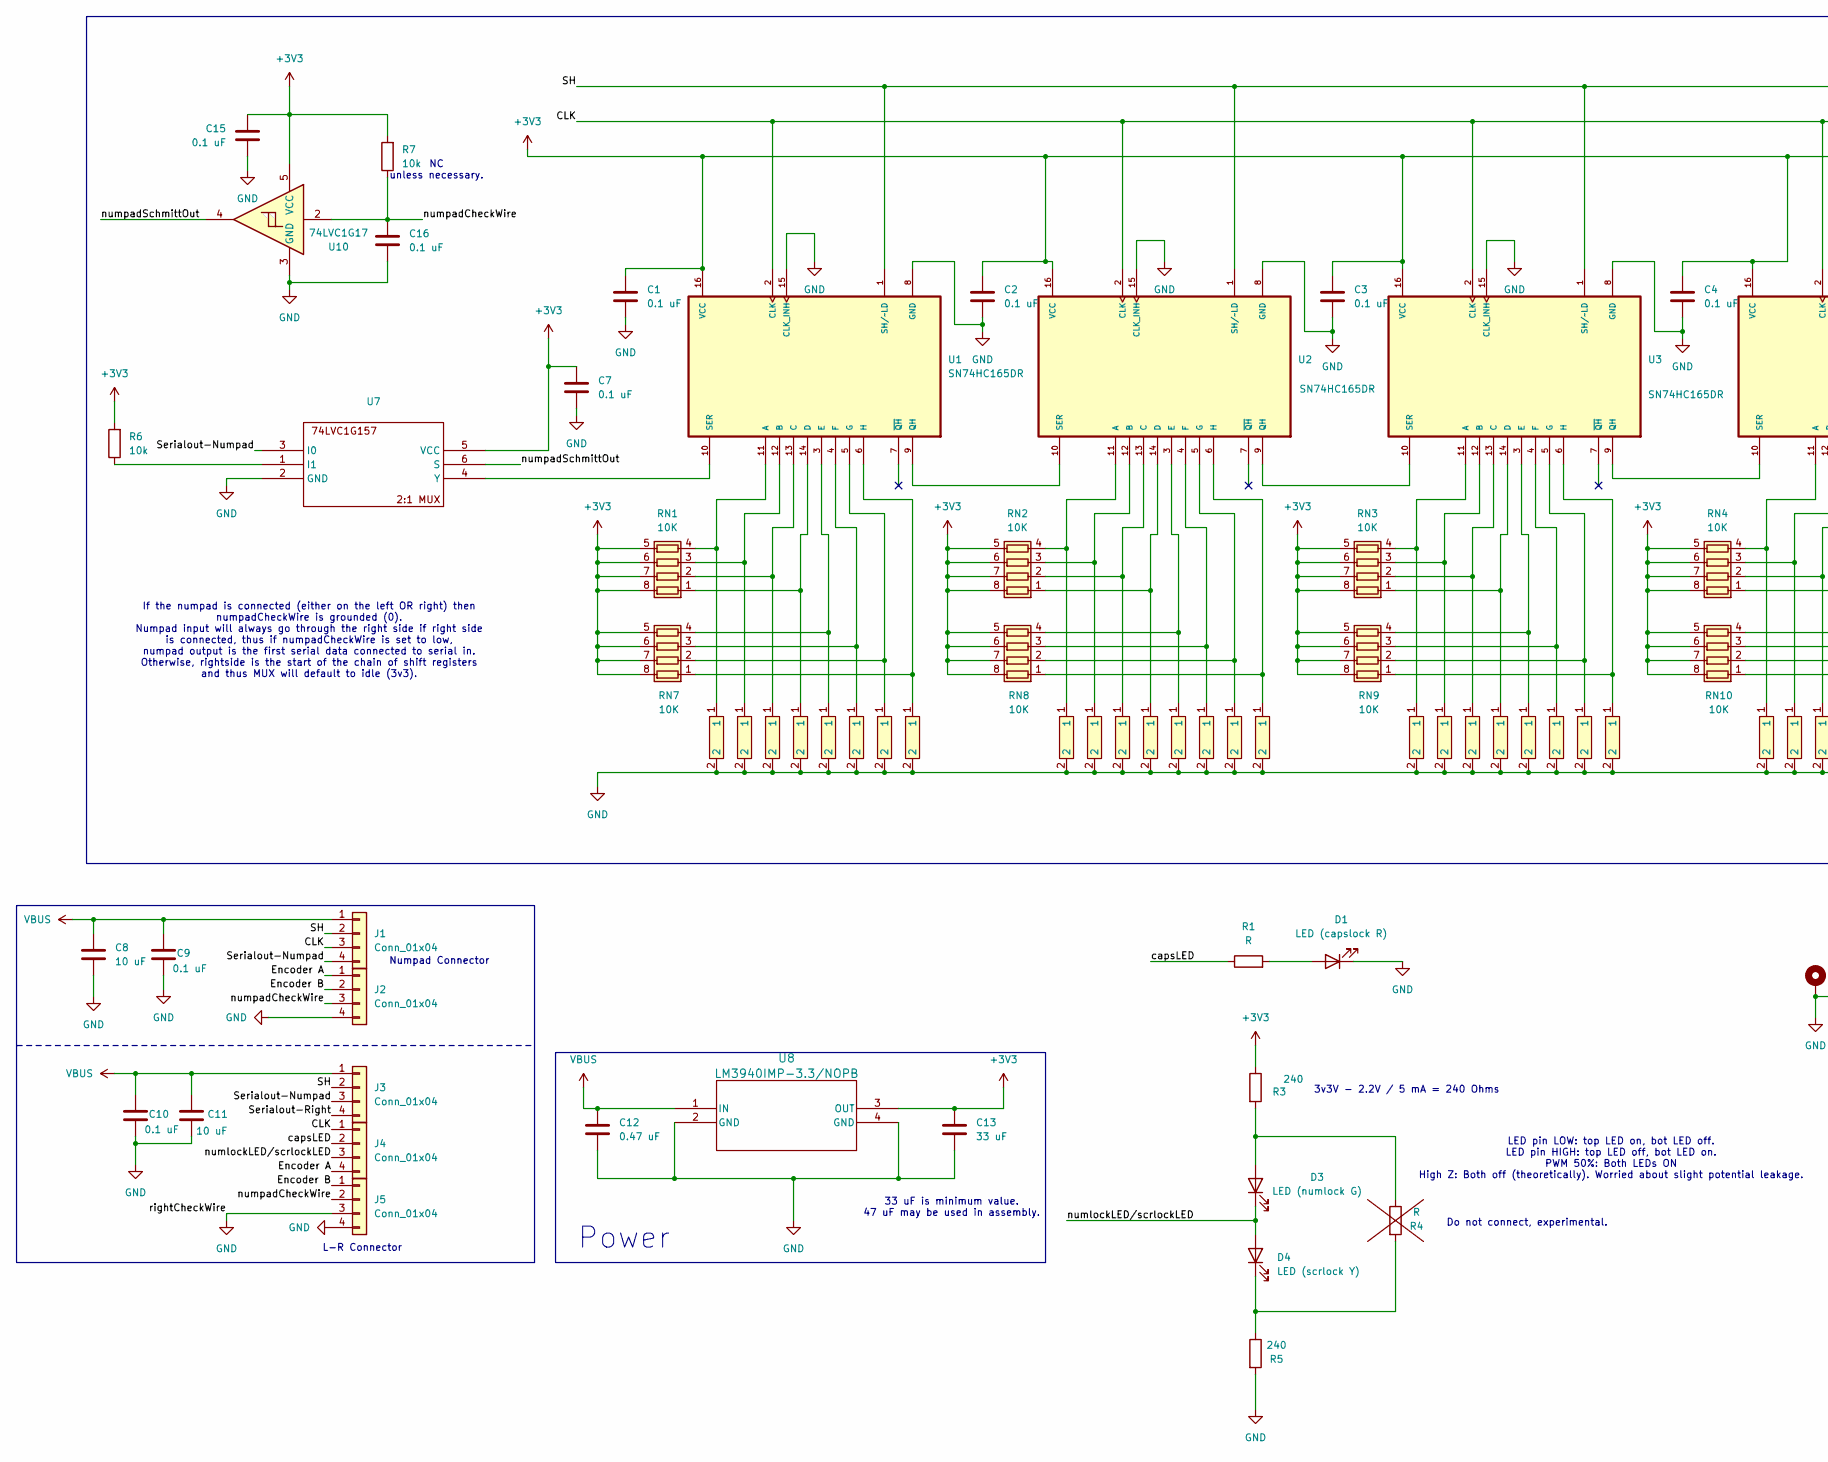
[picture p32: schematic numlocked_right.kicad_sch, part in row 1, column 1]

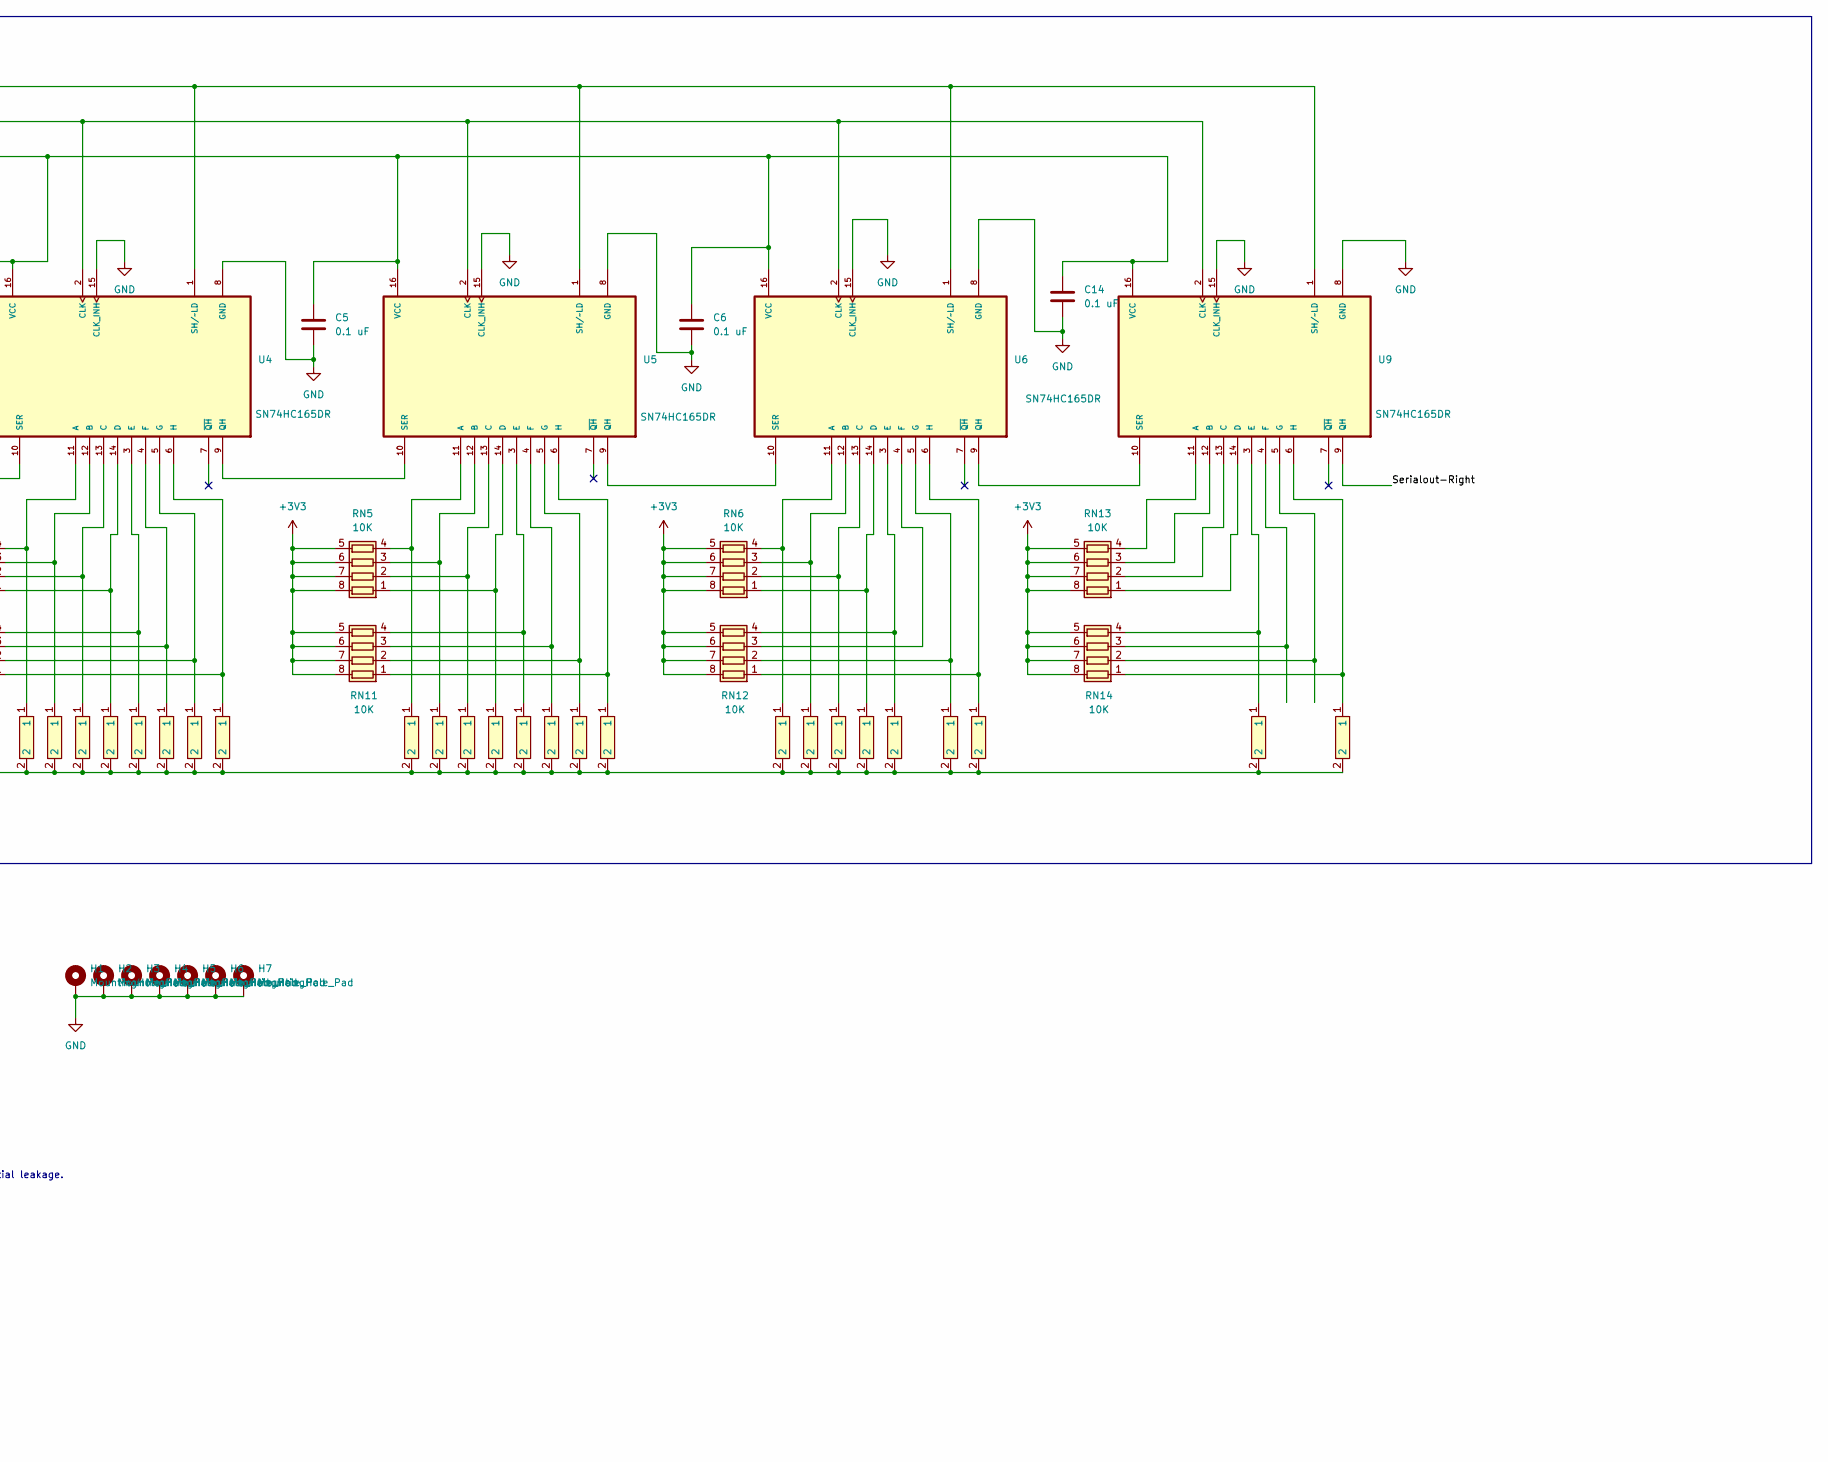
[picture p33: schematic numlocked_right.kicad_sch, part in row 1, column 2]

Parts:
C1, C2, C3, C4, C5, C6, C7, C9, C10, C14, C15, C16: 0.1 uF; C_0603_1608Metric
C8, C11: 10 uF; C_0603_1608Metric
C12: 0.47 uF; C_1206_3216Metric
C13: 33 uF; C_1206_3216Metric
D1: LED (capslock R); LED_0805_2012Metric
D3: LED (numlock G); LED_0805_2012Metric
D4: LED (scrlock Y); LED_0805_2012Metric
H1, H2, H3, H4, H5, H6, H7: MountingHole_Pad; MountingHole_2.2mm_M2_Pad
J1, J2, J3, J4, J5: Conn_01x04; Magnetic_Pogo_Pin_4pos
R1, R4: R; R_0603_1608Metric
R3, R5: 240; R_0603_1608Metric
R6, R7: 10k; R_0603_1608Metric
RN1, RN2, RN3, RN4, RN5, RN6, RN7, RN8, RN9, RN10, RN11, RN12, RN13, RN14: 10K; R_Array_Convex_4x1206
S1, S2, S3, S4, S5, S6, S7, S8, S9, S10, S11, S12, S13, S14, S15, S16, S17, S18, S19, S20, S21, S22, S23, S24, S25, S26, S27, S28, S29, S30, S31, S32, S33, S34, S36, S39, S40, S41, S43, S44, S45, S46, S47, S48, S49: SW_Cherry_Kalih_1.00u
S35, S38: SW_Cherry_Kalih_1.75u
S37: SW_Cherry_Kalih_2.25u
S42: SW_Cherry_Kalih_2.00u
U1, U2, U3, U4, U5, U6, U9: SN74HC165DR; SOIC127P600X175-16N
U7: SC-74-6_1.55x2.9mm_P0.95mm
U8: LM3940IMP-3.3/NOPB; SOT-223
U10: 74LVC1G17; SOT-23-5

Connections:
+3V3: C1.1, C2.1, C3.1, C4.1, C5.1, C6.1, C7.1, C13.1, C14.1, C15.1, R3.1, R6.2, R7.2, RN1.5 (R4.2), RN1.6 (R3.2), RN1.7 (R2.2), RN1.8 (R1.2), RN2.5 (R4.2), RN2.6 (R3.2), RN2.7 (R2.2), RN2.8 (R1.2), RN3.5 (R4.2), RN3.6 (R3.2), RN3.7 (R2.2), RN3.8 (R1.2), RN4.5 (R4.2), RN4.6 (R3.2), RN4.7 (R2.2), RN4.8 (R1.2), RN5.5 (R4.2), RN5.6 (R3.2), RN5.7 (R2.2), RN5.8 (R1.2), RN6.5 (R4.2), RN6.6 (R3.2), RN6.7 (R2.2), RN6.8 (R1.2), RN7.5 (R4.2), RN7.6 (R3.2), RN7.7 (R2.2), RN7.8 (R1.2), RN8.5 (R4.2), RN8.6 (R3.2), RN8.7 (R2.2), RN8.8 (R1.2), RN9.5 (R4.2), RN9.6 (R3.2), RN9.7 (R2.2), RN9.8 (R1.2), RN10.5 (R4.2), RN10.6 (R3.2), RN10.7 (R2.2), RN10.8 (R1.2), RN11.5 (R4.2), RN11.6 (R3.2), RN11.7 (R2.2), RN11.8 (R1.2), RN12.5 (R4.2), RN12.6 (R3.2), RN12.7 (R2.2), RN12.8 (R1.2), RN13.5 (R4.2), RN13.6 (R3.2), RN13.7 (R2.2), RN13.8 (R1.2), RN14.5 (R4.2), RN14.6 (R3.2), RN14.7 (R2.2), RN14.8 (R1.2), U1.16 (VCC), U2.16 (VCC), U3.16 (VCC), U4.16 (VCC), U5.16 (VCC), U6.16 (VCC), U7.5 (VCC), U8.3 (OUT), U9.16 (VCC), U10.5 (VCC)
/CLK: J1.3, J4.1, U1.2 (CLK), U2.2 (CLK), U3.2 (CLK), U4.2 (CLK), U5.2 (CLK), U6.2 (CLK), U9.2 (CLK)
/Encoder A: J2.1, J4.4
/Encoder B: J2.2, J5.1
/SH: J1.2, J3.2, U1.1 (SH/~LD), U2.1 (SH/~LD), U3.1 (SH/~LD), U4.1 (SH/~LD), U5.1 (SH/~LD), U6.1 (SH/~LD), U9.1 (SH/~LD)
/Serialout-Numpad: J1.4, J3.3, U7.3 (I0)
/Serialout-Right: J3.4, U9.9 (QH)
/capsLED: J4.2, R1.1
/numlockLED/scrlockLED: D3.1 (K), D4.2 (A), J4.3
/numpadCheckWire: C16.1, J2.3, J5.2, R7.1, U10.2
/numpadSchmittOut: U7.6 (S), U10.4
GND: C1.2, C2.2, C3.2, C4.2, C5.2, C6.2, C7.2, C8.2, C9.2, C10.2, C11.2, C12.2, C13.2, C14.2, C15.2, C16.2, D1.1 (K), H1.1, H2.1, H3.1, H4.1, H5.1, H6.1, H7.1, J2.4, J5.3, J5.4, R5.2, S1.2, S2.2, S3.2, S4.2, S5.2, S6.2, S7.2, S8.2, S9.2, S10.2, S11.2, S12.2, S13.2, S14.2, S15.2, S16.2, S17.2, S18.2, S19.2, S20.2, S21.2, S22.2, S23.2, S24.2, S25.2, S26.2, S27.2, S28.2, S29.2, S30.2, S31.2, S32.2, S33.2, S34.2, S35.2, S36.2, S37.2, S38.2, S39.2, S40.2, S41.2, S42.2, S43.2, S44.2, S45.2, S46.2, S47.2, S48.2, S49.2, U1.8 (GND), U1.15 (CLK_INH), U2.8 (GND), U2.15 (CLK_INH), U3.8 (GND), U3.15 (CLK_INH), U4.8 (GND), U4.15 (CLK_INH), U5.8 (GND), U5.15 (CLK_INH), U6.8 (GND), U6.15 (CLK_INH), U7.2 (GND), U8.2 (GND), U8.4 (GND), U9.8 (GND), U9.15 (CLK_INH), U10.3 (GND)
unnamed: D1.2 (A), R1.2
unnamed: D3.2 (A), R3.2, R4.1
unnamed: D4.1 (K), R4.2, R5.1
unnamed: RN1.1 (R1.1), S4.1, U1.14 (D)
unnamed: RN1.2 (R2.1), S3.1, U1.13 (C)
unnamed: RN1.3 (R3.1), S2.1, U1.12 (B)
unnamed: RN1.4 (R4.1), S1.1, U1.11 (A)
unnamed: RN2.1 (R1.1), S12.1, U2.14 (D)
unnamed: RN2.2 (R2.1), S11.1, U2.13 (C)
unnamed: RN2.3 (R3.1), S10.1, U2.12 (B)
unnamed: RN2.4 (R4.1), S9.1, U2.11 (A)
unnamed: RN3.1 (R1.1), S20.1, U3.14 (D)
unnamed: RN3.2 (R2.1), S19.1, U3.13 (C)
unnamed: RN3.3 (R3.1), S18.1, U3.12 (B)
unnamed: RN3.4 (R4.1), S17.1, U3.11 (A)
unnamed: RN4.1 (R1.1), S28.1, U4.14 (D)
unnamed: RN4.2 (R2.1), S27.1, U4.13 (C)
unnamed: RN4.3 (R3.1), S26.1, U4.12 (B)
unnamed: RN4.4 (R4.1), S25.1, U4.11 (A)
unnamed: RN5.1 (R1.1), S36.1, U5.14 (D)
unnamed: RN5.2 (R2.1), S35.1, U5.13 (C)
unnamed: RN5.3 (R3.1), S34.1, U5.12 (B)
unnamed: RN5.4 (R4.1), S33.1, U5.11 (A)
unnamed: RN6.1 (R1.1), S44.1, U6.14 (D)
unnamed: RN6.2 (R2.1), S43.1, U6.13 (C)
unnamed: RN6.3 (R3.1), S42.1, U6.12 (B)
unnamed: RN6.4 (R4.1), S41.1, U6.11 (A)
unnamed: RN7.1 (R1.1), S8.1, U1.6 (H)
unnamed: RN7.2 (R2.1), S7.1, U1.5 (G)
unnamed: RN7.3 (R3.1), S6.1, U1.4 (F)
unnamed: RN7.4 (R4.1), S5.1, U1.3 (E)
unnamed: RN8.1 (R1.1), S16.1, U2.6 (H)
unnamed: RN8.2 (R2.1), S15.1, U2.5 (G)
unnamed: RN8.3 (R3.1), S14.1, U2.4 (F)
unnamed: RN8.4 (R4.1), S13.1, U2.3 (E)
unnamed: RN9.1 (R1.1), S24.1, U3.6 (H)
unnamed: RN9.2 (R2.1), S23.1, U3.5 (G)
unnamed: RN9.3 (R3.1), S22.1, U3.4 (F)
unnamed: RN9.4 (R4.1), S21.1, U3.3 (E)
unnamed: RN10.1 (R1.1), S32.1, U4.6 (H)
unnamed: RN10.2 (R2.1), S31.1, U4.5 (G)
unnamed: RN10.3 (R3.1), S30.1, U4.4 (F)
unnamed: RN10.4 (R4.1), S29.1, U4.3 (E)
unnamed: RN11.1 (R1.1), S40.1, U5.6 (H)
unnamed: RN11.2 (R2.1), S39.1, U5.5 (G)
unnamed: RN11.3 (R3.1), S38.1, U5.4 (F)
unnamed: RN11.4 (R4.1), S37.1, U5.3 (E)
unnamed: RN12.1 (R1.1), S48.1, U6.6 (H)
unnamed: RN12.2 (R2.1), S47.1, U6.5 (G)
unnamed: RN12.3 (R3.1), U6.4 (F)
unnamed: RN12.4 (R4.1), S45.1, U6.3 (E)
unnamed: RN13.1 (R1.1), U9.14 (D)
unnamed: RN13.2 (R2.1), U9.13 (C)
unnamed: RN13.3 (R3.1), U9.12 (B)
unnamed: RN13.4 (R4.1), U9.11 (A)
unnamed: RN14.1 (R1.1), S49.1, U9.6 (H)
unnamed: RN14.2 (R2.1), U9.5 (G)
unnamed: RN14.3 (R3.1), U9.4 (F)
unnamed: RN14.4 (R4.1), S46.1, U9.3 (E)
unnamed: U1.9 (QH), U2.10 (SER)
unnamed: U1.10 (SER), U7.4 (Y)
unnamed: U2.9 (QH), U3.10 (SER)
unnamed: U3.9 (QH), U4.10 (SER)
unnamed: U4.9 (QH), U5.10 (SER)
unnamed: U5.9 (QH), U6.10 (SER)
unnamed: U6.9 (QH), U9.10 (SER)
unnamed: R6.1, U7.1 (I1)
VBUS: C8.1, C9.1, C10.1, C11.1, C12.1, J1.1, J3.1, U8.1 (IN)

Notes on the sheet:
NC unless necessary.
Numpad Connector
33 uF is minimum value. 47 uF may be used in assembly.
Power
If the numpad is connected (either on the left OR right) then numpadCheckWire is grounded (0). Numpad input will always go through the right side if right side is connected, thus if numpadCheckWire is set to low, numpad output is the first serial data connected to serial in. Otherwise, rightside is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
Do not connect, experimental.
LED pin LOW: top LED on, bot LED off. LED pin HIGH: top LED off, bot LED on. PWM 50%: Both LEDs ON High Z: Both off (theoretically). Worried about slight potential leakage.
3v3V - 2.2V / 5 mA = 240 Ohms
L-R Connector

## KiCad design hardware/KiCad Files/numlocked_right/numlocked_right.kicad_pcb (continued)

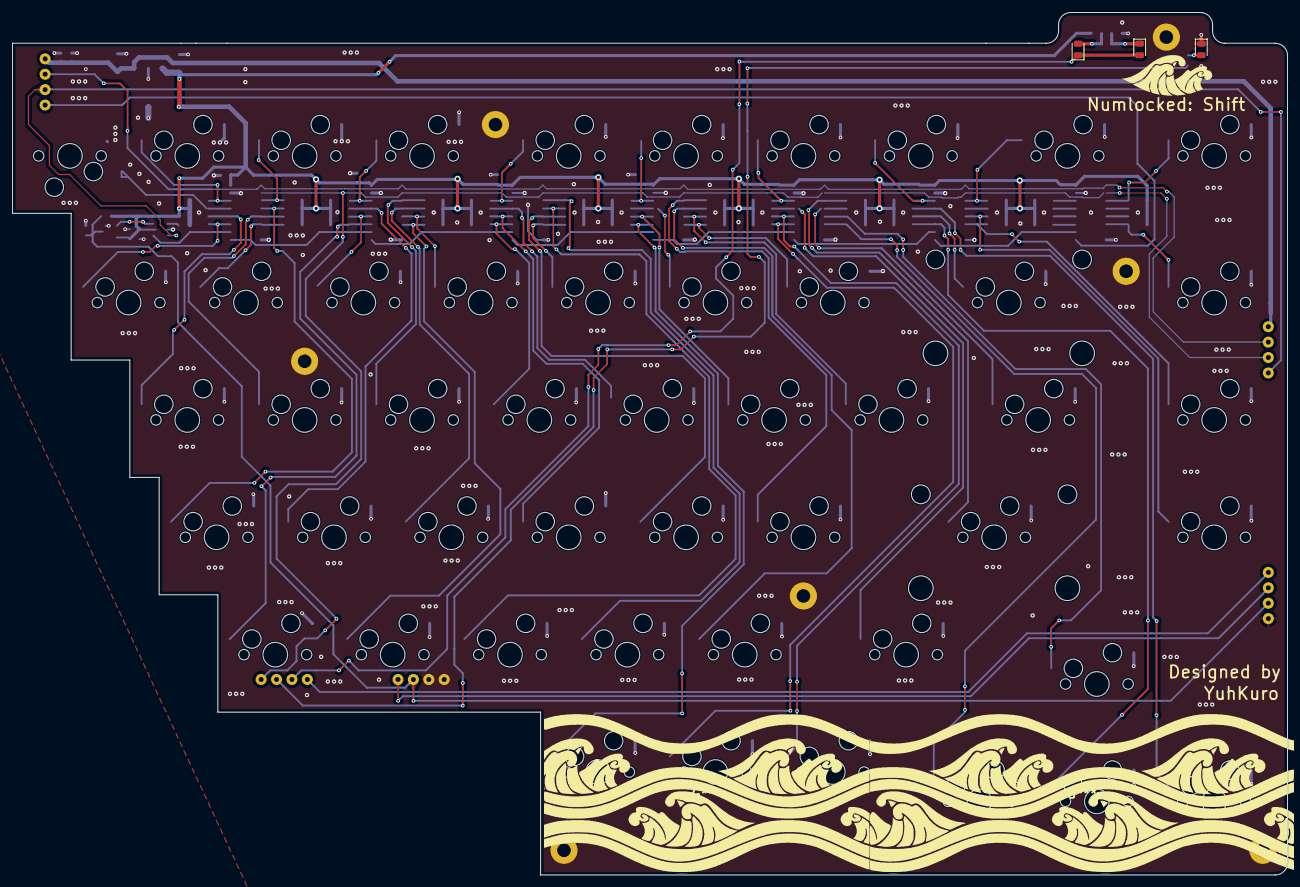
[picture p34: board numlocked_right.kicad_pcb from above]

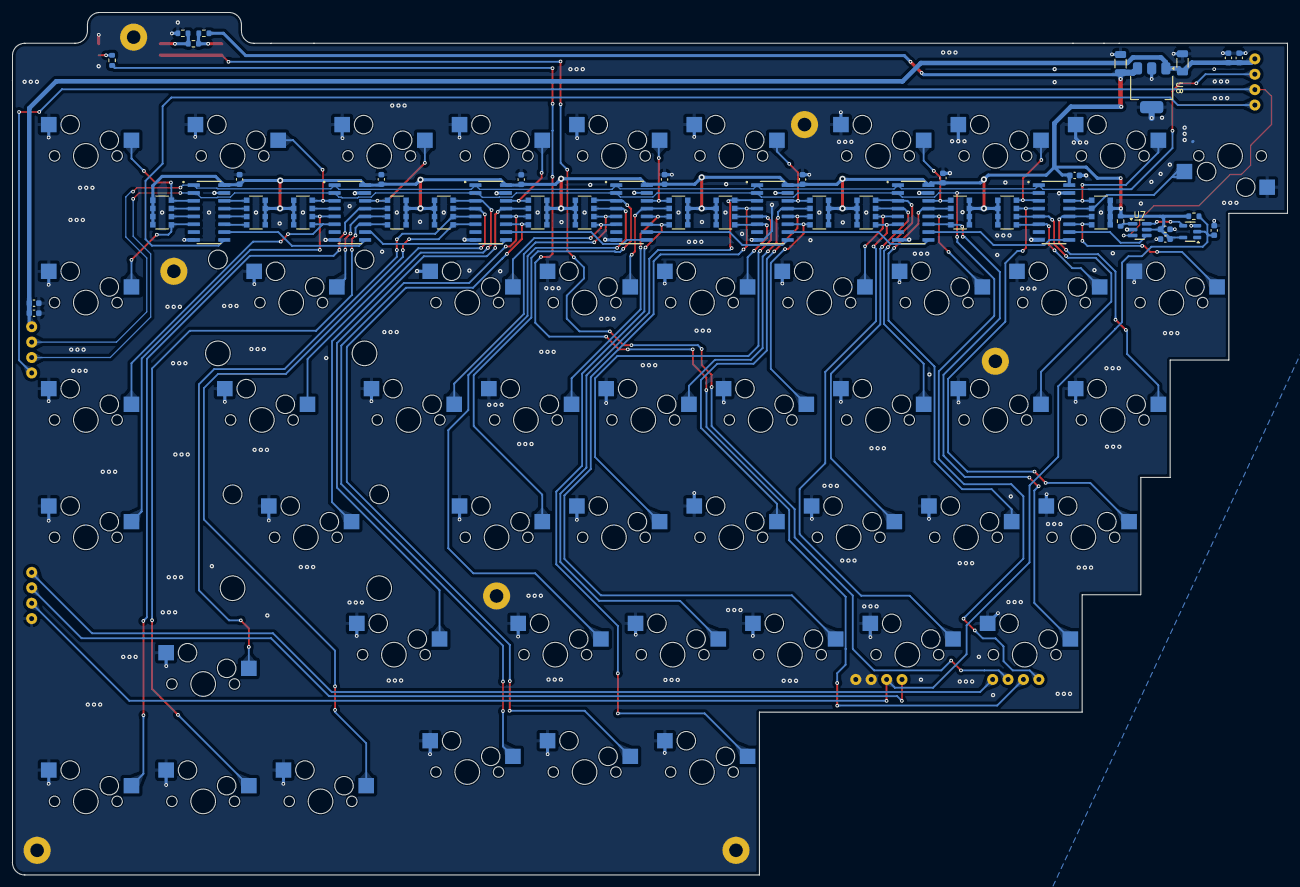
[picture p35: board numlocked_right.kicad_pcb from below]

Board: 2 copper layers, 207.0 x 140.0 mm, 110 parts (49 on the bottom side), 80 nets.

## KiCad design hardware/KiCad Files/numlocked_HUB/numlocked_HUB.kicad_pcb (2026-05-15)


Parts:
C1, C2, C3, C4, C5, C6, C7, C8, C9, C10: 0.1 uF; C_0603_1608Metric
C11, C12: 18 pF; C_0603_1608Metric
C13: 0.47 uF; C_1206_3216Metric
C14: 33 uF; C_1206_3216Metric
C15, C16: 1 uF; C_0603_1608Metric
H1, H2, H3, H4, H6: MountingHole_Pad; MountingHole_2.2mm_M2_Pad
J1: USB4105-GF-A; GCT_USB4105-GF-A; PARTREV B4
J2: UBAS-4R-D14D-4D(LF)(SN)
J3, J4: UE27AC54100; AMPHENOL_UE27AC54100; PARTREV E
J5: SM04B-SRSS-TB; CONN_SM04B-SRSS-TB_JST
R1, R2, R3, R4, R6, R7, R8, R9, R10, R11, R12: 100K; R_0603_1608Metric
R5, R17: 22; R_0603_1608Metric
R13: 12K; R_0603_1608Metric
R14: 1M; R_0603_1608Metric
R15, R16: 5.1K; R_0603_1608Metric
U1: USB2514B-AEZC-TR; QFN36_6X6MC_MCH
U2: LM3940IMP-3.3/NOPB; SOT-223
U4: SRV05-4.TCT; SO6_SOT23-6L
Y1: ABM8-24.000MHZ-D1G-T; Crystal_SMD_Abracon_ABM8G-4Pin_3.2x2.5mm; PARTREV 44041

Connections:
+3V3: C1.1, C2.1, C3.1, C4.1, C5.1, C6.1, C14.1, C15.1, C16.1, R9.1, U1.5 (VDDA33), U1.10 (VDDA33), U1.15 (VDD33), U1.23 (VDD33), U1.29 (VDDA33), U1.36 (VDDA33), U2.3 (OUT)
+5V: C13.1, J1.A4_B9 (VBUS), J1.B4_A9 (VBUS__1), J2.1 (VCC), J3.1 (VCC), J4.1 (VCC), J5.1, R1.2, R2.2, R3.2, R4.1, R10.1, U2.1 (IN), U4.5
/RESET_N: C7.1, R9.2, U1.26 (RESET_N)
/USB_DOWN1_N: J2.2 (D-), U1.1 (USBDM_DN1/PRT_DIS_M1)
/USB_DOWN1_P: J2.3 (D+), U1.2 (USBDP_DN1/PRT_DIS_P1)
/USB_DOWN2_N: J3.2 (D-), U1.3 (USBDM_DN2/PRT_DIS_M2)
/USB_DOWN2_P: J3.3 (D+), U1.4 (USBDP_DN2/PRT_DIS_P2)
/USB_DOWN3_N: J4.2 (D-), U1.6 (USBDM_DN3/PRT_DIS_M3)
/USB_DOWN3_P: J4.3 (D+), U1.7 (USBDP_DN3/PRT_DIS_P3)
/USB_DOWN4_N: J5.2, U1.8 (USBDM_DN4/PRT_DIS_M4)
/USB_DOWN4_P: J5.3, U1.9 (USBDP_DN4/PRT_DIS_P4)
/USB_UP_N: J1.A7 (DN1), J1.B7 (DN2), R5.2, U4.1
/USB_UP_P: J1.A6 (DP1), J1.B6 (DP2), R17.2, U4.6
/USB_UP_RES_N: R5.1, U1.30 (USBDM_UP)
/USB_UP_RES_P: R17.1, U1.31 (USBDP_UP)
/VBUS_DET: C8.1, R10.2, R11.1, U1.27 (VBUS_DET)
/XTALIN: C11.1, R14.1, U1.33 (XTALIN/CLKIN), Y1.1
/XTALOUT: C12.1, R14.2, U1.32 (XTALOUT), Y1.3
GND: C1.2, C2.2, C3.2, C4.2, C5.2, C6.2, C7.2, C8.2, C9.2, C10.1, C11.2, C12.2, C13.2, C14.2, C15.2, C16.2, H1.1, H2.1, H3.1, H4.1, H6.1, J1.A1_B12 (GND), J1.B1_A12 (GND__1), J1.SH1 (SHELL_GND), J1.SH2 (SHELL_GND__1), J1.SH3 (SHELL_GND__2), J1.SH4 (SHELL_GND__3), J2.4 (GND), J2.S1 (SHIELD), J2.S2 (SHIELD__1), J2.S3 (SHIELD__2), J3.4 (GND), J3.S1 (SHIELD), J3.S2 (SHIELD__1), J4.4 (GND), J4.S1 (SHIELD), J4.S2 (SHIELD__1), J5.4, R6.2, R7.2, R8.2, R11.2, R12.2, R13.2, R15.1, R16.1, U1.11 (TEST), U1.37 (EPAD), U2.2 (GND), U2.4 (GND), U4.2, Y1.2 (GND), Y1.4 (GND__1); also elsewhere on the board
unnamed: J1.A5 (CC1), R15.2
unnamed: J1.B5 (CC2), R16.2
unnamed: C10.2, U1.14 (CRFILT)
unnamed: R6.1, U1.25 (HS_IND/CFG_SEL1)
unnamed: C9.1, U1.34 (PLLFILT)
unnamed: R1.1, U1.12 (PRTPWR1/BC_EN1)
unnamed: R2.1, U1.16 (PRTPWR2/BC_EN2)
unnamed: R3.1, U1.18 (PRTPWR3/BC_EN3)
unnamed: R4.2, U1.20 (PRTPWR4/BC_EN4)
unnamed: R13.1, U1.35 (RBIAS)
unnamed: R7.1, U1.24 (SCL/SMBCLK/CFG_SEL0)
unnamed: R8.1, U1.22 (SDA/SMBDATA/NON_REM1)
unnamed: R12.1, U1.28 (SUSP_IND/LOCAL_PWR/NON_REM0)

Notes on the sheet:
Crystal
USB-A Downstream 1
Power
USB-HUB
JST to Keyboard
USB-A Downstream 2
USB-A Downstream 3
Connector is technically "reversed."
ESD Chip
USB-C
Mounting Holes (plated)


Board: 4 copper layers, 102.0 x 36.5 mm, 48 parts (1 on the bottom side), 32 nets.

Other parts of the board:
H2#2: MountingHole_Pad; MountingHole_2.2mm_M2_Pad

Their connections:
GND: H2#2.1; also elsewhere on the board

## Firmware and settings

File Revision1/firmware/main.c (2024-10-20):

/*
 * The MIT License (MIT)
 *
 * Copyright (c) 2019 Ha Thach (tinyusb.org)
 *
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
 */

#include <stdlib.h>
#include "pico/stdlib.h"
#include <stdio.h>
#include <string.h>

#include "bsp/board_api.h"
#include "tusb.h"
#include "usb_descriptors.h"

#include "ssd1306.h"
#include "pico/multicore.h"
#include "hardware/i2c.h"
#include "waveanim.h"
#include "bootanim.h"

#include <math.h>


// GPIO Definitions
#define LED_MAIN 11
#define LED_CAP 12

#define MATRIX_CLK 16
#define MATRIX_CLKINH 17
#define MATRIX_SHLD 18
#define MATRIX_QH 19

#define ENC_SW 8
#define ENC_A 9
#define ENC_B 10

#define OLED_SDA 22
#define OLED_SCL 23 

#define TOTAL_BITS 112 //The total number of keys on the keyboard. 8-bits x 14 shift regs = 112 bits.

#define REPORT_ID_KEYBOARD 1

#define DEBOUNCE_DELAY_MS 10           // Debounce delay to filter out bouncing
#define PRESS_AND_HOLD_DELAY_MS 250   // Time before key repeat starts
#define REPEAT_RATE_MS 50             // Delay between repeated keypresses

#define WPM_CALC_INTERVAL_MS 5000  // Interval to calculate WPM in milliseconds (e.g., 5 seconds)
#define CHARACTERS_PER_WORD 5

#define IDLE_SPEED 10  // below this wpm value your animation will idle

#define ACTIVE_SPEED 40  // above this wpm value typing animation to trigger


//static uint32_t last_encoder_state = 0;

typedef struct {
    uint32_t last_interrupt_time;
    uint32_t characters_typed;      // Counts characters typed
    uint32_t last_wpm_calc_time;    // Last time WPM was calculated
    volatile int wpm;               // Words per minute
    uint8_t currentFrame;
    bool gameMode;
} globalVariables;

globalVariables global = {0};
/*
globalVariables global = {
    .last_interrupt_time = 0,
    .characters_typed = 0,
    .last_wpm_calc_time = 0,
    .wpm = 0,
    .currentFrame = 0,
    .gameMode = false 
};
*/

void hid_task(void);
void gpio_initialize();
void animation();
static void calculate_wpm(uint32_t current_time);


/* OLED Animation function. */
/*Runs on the second RP2040 core (Core 1), separate from the keyboard main code.
* This function displays an animation on the OLED screen, with a WPM counter.
* The current animation consists of a wave that ripples across the screen through 
* 10 frames that loop continuously. The speed of the animation is controlled by the WPM value.
* Each frame is located in the wave array in images.h.

*/

void animation() {
    ssd1306_t disp;
    disp.external_vcc = false;
    ssd1306_init(&disp, 128, 32, 0x3C, i2c1);
    ssd1306_clear(&disp);

    char time_wpm_str[15] = {0};
    uint16_t delay_time;
    int wpm = 0;
    uint32_t last_wpm_time = board_millis();  // Track the last time WPM was non-zero
    const uint32_t timeout_ms = 30000;  // 30 seconds of inactivity before turning off display
    bool display_on = true;
    //TODO: Add startup animation.

    while (1) {
        wpm = global.wpm;

        if (wpm == 0) {
            // If WPM is zero, check how long it's been zero
            if (board_millis() - last_wpm_time >= timeout_ms) {
                if (display_on) {
                    ssd1306_clear(&disp);  // Clear the display
                    ssd1306_poweroff(&disp);  // Turn off the display
                    display_on = false;
                }
            }
        } else {
            // WPM is non-zero, reset the timer and ensure display is on
            last_wpm_time = board_millis();
            if (!display_on) {
                ssd1306_poweron(&disp);  // Turn on the display
                display_on = true;
            }
        }

        if (display_on) {
            if (wpm <= 10) {
                delay_time = 200;  // Slow FPS for "idle".
            } else if (wpm <= 40 && wpm > 10) {
                delay_time = 150;  // Steadily increase for each WPM range.
            } else if (wpm <= 80 && wpm > 40) {
                delay_time = 100;  
            } else if (wpm <= 100 && wpm > 80) {
                delay_time = 75;  
            } else {
                delay_time = 50;  // Fastest animation speed while looking good.
            }

            // Update the WPM string
            if (global.gameMode) {
                snprintf(time_wpm_str, sizeof(time_wpm_str), "GAMEMODE: ON");
            } else {
                snprintf(time_wpm_str, sizeof(time_wpm_str), "WPM:%03d", wpm);
            }
            // Display the current frame and WPM
            ssd1306_show_image_with_text(&disp, wave_frames[global.currentFrame], frameSize, time_wpm_str, 1, 0, 0);

            // Update the frame index
            global.currentFrame = (global.currentFrame + 1) % 10;  // Loop through 10 frames
        }

        // Delay before showing the next frame
        sleep_ms(delay_time);
    }
}


/*WPM CALCULATOR*/
/* Calculates the current WPM of the user by taking the number of keys typed, extrapolating to a minute
* and using an average of 5 letters per word. Its a little  inaccurate, so tweaking in the future is
*needed.
*/
static void calculate_wpm(uint32_t current_time) {
    uint32_t time_elapsed_ms = current_time - global.last_wpm_calc_time;

    if (time_elapsed_ms >= WPM_CALC_INTERVAL_MS) {
        if (global.characters_typed > 0) {
            // Calculate WPM only if new characters were typed
            float time_elapsed_min = (float)time_elapsed_ms / 60000.0;  // Convert ms to minutes
            float current_wpm = ((float)global.characters_typed / CHARACTERS_PER_WORD) / time_elapsed_min;

            // Update WPM directly with new value, no rolling average
            global.wpm = (uint32_t)current_wpm;

            // Reset characters_typed for the next interval
            global.characters_typed = 0;
        } else {
            // No new characters typed: Decay WPM towards zero
            if (global.wpm > 0) {
                // Decrease WPM over time, adjust the decay rate as needed
                global.wpm = global.wpm * 0.5; // Decays WPM by 10% each interval
            } else {
                global.wpm = 0; // Ensure WPM doesn't go negative
            }
        }

        // Update the last calculation time
        global.last_wpm_calc_time = current_time;
    }
}

static uint8_t last_state = 0b11;  // Initialize with the idle state (11)
    
/* Called when the encoder is rotated in clockwise or counterclockwise direction. */
void encoder_callback(uint gpio, uint32_t events) {


    uint32_t current_time = board_millis();

    // Debounce: Ignore interrupts occurring within 5ms of the last one
    if ((current_time - global.last_interrupt_time) < 5) {
        return;
    }
    global.last_interrupt_time = current_time;

    // Read current states of ENC_A and ENC_B
    uint8_t enc_a_state = gpio_get(ENC_A);
    uint8_t enc_b_state = gpio_get(ENC_B);

    // Combine the states into a single value (enc_a_state: bit 1, enc_b_state: bit 0)
    uint8_t current_state = (enc_a_state << 1) | enc_b_state;

    // Determine direction by comparing the current state to the previous state
    if ((last_state == 0b11 && current_state == 0b01) ||
        (last_state == 0b01 && current_state == 0b00) ||
        (last_state == 0b00 && current_state == 0b10) ||
        (last_state == 0b10 && current_state == 0b11)) {
        // Clockwise rotation
        uint16_t volume_up = HID_USAGE_CONSUMER_VOLUME_INCREMENT;
        tud_hid_report(REPORT_ID_CONSUMER_CONTROL, &volume_up, 1);
    } else if ((last_state == 0b11 && current_state == 0b10) ||
               (last_state == 0b10 && current_state == 0b00) ||
               (last_state == 0b00 && current_state == 0b01) ||
               (last_state == 0b01 && current_state == 0b11)) {
        // Counter-clockwise rotation
        uint16_t volume_down = HID_USAGE_CONSUMER_VOLUME_DECREMENT;
        tud_hid_report(REPORT_ID_CONSUMER_CONTROL, &volume_down, 1);
    }
    

    // Update the last state with the current state
    last_state = current_state;
}

void switch_callback(uint gpio, uint32_t events) {
    // Send the media key
    uint16_t play_pause = HID_USAGE_CONSUMER_PLAY_PAUSE;
    tud_hid_report(REPORT_ID_CONSUMER_CONTROL, &play_pause, 0.5);
}


void gpio_initialize() {

    gpio_init(MATRIX_CLK);
    gpio_set_dir(MATRIX_CLK, GPIO_OUT);

    gpio_init(MATRIX_CLKINH);
    gpio_set_dir(MATRIX_CLKINH, GPIO_OUT);    

    gpio_init(MATRIX_SHLD);
    gpio_set_dir(MATRIX_SHLD, GPIO_OUT);

    gpio_init(MATRIX_QH);
    gpio_set_dir(MATRIX_QH, GPIO_IN);
    gpio_init(ENC_A);
    gpio_set_dir(ENC_A, GPIO_IN);
    gpio_disable_pulls(ENC_A);

    gpio_init(ENC_B);
    gpio_set_dir(ENC_B, GPIO_IN);
    gpio_disable_pulls(ENC_B);

    gpio_init(ENC_SW);
    gpio_set_dir(ENC_SW, GPIO_IN);

    // Register the callback for ENC_A on falling edge
    gpio_set_irq_enabled_with_callback(ENC_A, GPIO_IRQ_EDGE_FALL, true, &encoder_callback);
    gpio_set_irq_enabled_with_callback(ENC_B, GPIO_IRQ_EDGE_FALL, true, &encoder_callback);

    // Register the callback for the encoder switch on falling edge
    gpio_pull_up(ENC_SW);
    gpio_set_irq_enabled_with_callback(ENC_SW, GPIO_IRQ_EDGE_FALL | GPIO_IRQ_EDGE_RISE, true, &switch_callback);

    i2c_init(i2c1, 400000);
    gpio_set_function(OLED_SDA, GPIO_FUNC_I2C);
    gpio_set_function(OLED_SCL, GPIO_FUNC_I2C);
    gpio_pull_up(OLED_SDA);
    gpio_pull_up(OLED_SCL);
}
/*------------- MAIN -------------*/
int main(void)
{
  board_init();

  // init device stack on configured roothub port
  tud_init(BOARD_TUD_RHPORT);

  gpio_initialize();

  if (board_init_after_tusb) {
    board_init_after_tusb();
  }

  multicore_launch_core1(animation);

  while (1)
  {
    tud_task(); // tinyusb device task
    hid_task();
  }


  return 0;
}


//--------------------------------------------------------------------+
// USB HID
//--------------------------------------------------------------------+
// HID_KEY_F21 is top left numpad macro.
uint8_t key_map[TOTAL_BITS] = {
    HID_KEY_KEYPAD_DIVIDE/**/, HID_KEY_NUM_LOCK/*ORIG NUMLCK*/, HID_KEY_KEYPAD_MULTIPLY/**/, HID_KEY_F21, HID_KEY_KEYPAD_8/**/, HID_KEY_KEYPAD_7/**/, HID_KEY_F22, HID_KEY_KEYPAD_ADD/**/,
    HID_KEY_KEYPAD_2/**/, HID_KEY_KEYPAD_1/**/, HID_KEY_KEYPAD_3, HID_KEY_KEYPAD_9/**/, HID_KEY_KEYPAD_6/**/, HID_KEY_KEYPAD_5/**/, HID_KEY_KEYPAD_4/**/, HID_KEY_GUI_LEFT/**/, //left win
    HID_KEY_CONTROL_LEFT/**/, HID_KEY_KEYPAD_ENTER/**/, HID_KEY_SHIFT_LEFT, HID_KEY_F24, HID_KEY_KEYPAD_DECIMAL, HID_KEY_KEYPAD_0, HID_KEY_KEYPAD_SUBTRACT, HID_KEY_GRAVE,
    HID_KEY_TAB/**/, HID_KEY_A/**/, HID_KEY_Q/**/, HID_KEY_ESCAPE/**/, HID_KEY_CAPS_LOCK/**/, HID_KEY_Z/**/, HID_KEY_ALT_LEFT, HID_KEY_S/**/,
    HID_KEY_F/**/, HID_KEY_G/*n*/, HID_KEY_D/**/, HID_KEY_B/**/, HID_KEY_X/**/, HID_KEY_C/**/, HID_KEY_V/**/, HID_KEY_3, // Continue with unique codes
    HID_KEY_Y/**/, HID_KEY_T/**/, HID_KEY_2/*n*/, HID_KEY_1, HID_KEY_R/*n*/, HID_KEY_W/**/, HID_KEY_E/*n*/, HID_KEY_7/*n*/,
    HID_KEY_6/*n*/, HID_KEY_5/*n*/, HID_KEY_4, HID_KEY_F1, HID_KEY_F3/**/, HID_KEY_F2/*n*/, HID_KEY_F4/**/, HID_KEY_F6,
    HID_KEY_F7, HID_KEY_F5/**/, HID_KEY_F8, HID_KEY_9/*n*/, HID_KEY_MINUS/*n*/, HID_KEY_0/*n*/, HID_KEY_8/*n*/, 0x30,
    0x2f, HID_KEY_P, HID_KEY_EQUAL/**/, HID_KEY_L, HID_KEY_O/**/, HID_KEY_G, HID_KEY_E, HID_KEY_APOSTROPHE/**/,
    HID_KEY_K/**/, HID_KEY_J/**/, HID_KEY_H/**/, HID_KEY_U/**/, HID_KEY_SEMICOLON/**/, HID_KEY_L/**/, HID_KEY_I/**/, HID_KEY_F6,
    HID_KEY_N/**/, HID_KEY_F9/**/, HID_KEY_F10, HID_KEY_PERIOD/**/, HID_KEY_SLASH/**/, HID_KEY_M/**/, HID_KEY_COMMA/**/, HID_KEY_F10, HID_KEY_P, HID_KEY_I, HID_KEY_U,
    HID_KEY_F12, HID_KEY_K, HID_KEY_DELETE/**/, HID_KEY_F11, HID_KEY_GUI_RIGHT/**/, HID_KEY_ALT_RIGHT/**/, HID_KEY_SPACE/**/,
    HID_KEY_CONTROL_RIGHT, HID_KEY_BACKSLASH, HID_KEY_SHIFT_RIGHT, HID_KEY_ENTER, HID_KEY_BACKSPACE/**/, HID_KEY_ARROW_UP/**/, HID_KEY_ARROW_LEFT/**/,
    HID_KEY_ARROW_DOWN/**/, HID_KEY_ARROW_RIGHT/**/, HID_KEY_HOME, HID_KEY_PAGE_UP/**/, HID_KEY_PAGE_DOWN, HID_KEY_INSERT/**/

};



void read_keys(uint8_t* key_state) {
    static uint8_t last_state[TOTAL_BITS] = {0};
    static uint32_t last_time[TOTAL_BITS] = {0};

    gpio_put(MATRIX_SHLD, 0); // Low
    sleep_us(1);              // Short delay
    gpio_put(MATRIX_SHLD, 1); // High
    sleep_us(1);              // Short delay

    for (int i = 0; i < TOTAL_BITS; i++) {
        gpio_put(MATRIX_CLK, 1);  // Pulse the clock to shift the data
        sleep_us(1);              // Short delay
        bool bit = gpio_get(MATRIX_QH); // Read the bit

        uint32_t current_time = board_millis();
        if (bit != last_state[i] && (current_time - last_time[i] >= DEBOUNCE_DELAY_MS)) {
            last_state[i] = bit;
            last_time[i] = current_time;
        }

        key_state[i] = last_state[i] ? 0 : 1; // Store the bit (invert logic: 0 means pressed)
        gpio_put(MATRIX_CLK, 0);  // Reset clock to low
        sleep_us(1);              // Short delay
    }
}

//static uint32_t key_press_time[TOTAL_BITS] = {0};  // Tracks when a key was first pressed
//static bool key_repeated[TOTAL_BITS] = {false};    // Tracks if the key has started repeating
static uint8_t previous_key_state[TOTAL_BITS] = {0};


bool key_is_modifier(uint8_t key) {
    return (key >= HID_KEY_CONTROL_LEFT && key <= HID_KEY_GUI_RIGHT);
}

// Function to get the corresponding bit for a modifier key
uint8_t key_modifier_bit(uint8_t key) {
    return 1 << (key - HID_KEY_CONTROL_LEFT);
}



static void send_keyboard() {
    if (!tud_hid_ready()) return;

    uint8_t key_state[TOTAL_BITS] = {0};
    read_keys(key_state);

    uint8_t key_report[8] = {0};  // Key report to be sent (8 bytes)
    int key_index = 2;  // Start filling regular key codes from the third byte
    uint32_t current_time = board_millis();  // Get current time in milliseconds
    bool key_pressed = false;  // Flag to check if any key is pressed

    for (int i = 0; i < TOTAL_BITS; i++) {
        if (key_state[i]) {
            uint8_t key = key_map[i];
            if (global.gameMode && (key == HID_KEY_GUI_LEFT || key == HID_KEY_GUI_RIGHT)) { //if game mode is active, skip windows.
                continue;  
            }
            key_pressed = true;

            // Handle modifier keys (e.g., ALT, CTRL)
            if (key_is_modifier(key)) { 
                key_report[0] |= key_modifier_bit(key);
            } else {
                // Handle regular keys
                if (!previous_key_state[i]) {
                    // Key has just been pressed
                    if (key_index < 8) {
                        key_report[key_index++] = key;
                        if (key != HID_KEY_SPACE) {
                            global.characters_typed++;  // Only count the initial press
                        }
                    }
                } else {
                    // Key is held down, continue sending the same report
                    if (key_index < 8) {
                        key_report[key_index++] = key;
                    }
                }
            }
        }

        previous_key_state[i] = key_state[i];  // Update the previous state
    }

    // If no key is pressed, send an empty report (all keys released)
    if (!key_pressed) {
        memset(key_report, 0, sizeof(key_report));
    }

    if (key_report[0] & key_modifier_bit(HID_KEY_CONTROL_LEFT) && key_report[2] == HID_KEY_COMMA) {
        global.gameMode = !global.gameMode;
    }

    // Send key report
    tud_hid_keyboard_report(REPORT_ID_KEYBOARD, key_report[0], &key_report[2]);

    // Optional: Handle additional functions
    if (gpio_get(ENC_SW) == 0) {
        uint16_t play_pause = HID_USAGE_CONSUMER_PLAY_PAUSE;
        tud_hid_report(REPORT_ID_CONSUMER_CONTROL, &play_pause, sizeof(play_pause));
    }

    calculate_wpm(current_time);
}

// Every 10ms, we will sent 1 report for each HID profile (keyboard, mouse etc ..)
// tud_hid_report_complete_cb() is used to send the next report after previous one is complete
void hid_task(void)
{

  //uint32_t const btn = board_button_read();

  // Remote wakeup
  if ( tud_suspended())
  {
    // Wake up host if we are in suspend mode
    // and REMOTE_WAKEUP feature is enabled by host
    tud_remote_wakeup();
  }else
  {
    send_keyboard();
    // Send the 1st of report chain, the rest will be sent by tud_hid_report_complete_cb()
    //send_hid_report(REPORT_ID_KEYBOARD, btn);
  }
}

// Invoked when sent REPORT successfully to host
// Application can use this to send the next report
// Note: For composite reports, report[0] is report ID
void tud_hid_report_complete_cb(uint8_t instance, uint8_t const* report, uint16_t len)
{
  (void) instance;
  (void) len;

  uint8_t next_report_id = report[0] + 1u;

  if (next_report_id < REPORT_ID_COUNT)
  {
    //send_hid_report(next_report_id, board_button_read());
    send_keyboard();
  }
}

// Invoked when received GET_REPORT control request
// Application must fill buffer report's content and return its length.
// Return zero will cause the stack to STALL request
uint16_t tud_hid_get_report_cb(uint8_t instance, uint8_t report_id, hid_report_type_t report_type, uint8_t* buffer, uint16_t reqlen)
{
  (void) instance;
  (void) report_id;
  (void) report_type;
  (void) buffer;
  (void) reqlen;

  return 0;
}

// Invoked when received SET_REPORT control request or
// received data on OUT endpoint ( Report ID = 0, Type = 0 )
void tud_hid_set_report_cb(uint8_t instance, uint8_t report_id, hid_report_type_t report_type, uint8_t const* buffer, uint16_t bufsize)
{
  (void) instance;
}

//--------------------------------------------------------------------+
// Device callbacks
//--------------------------------------------------------------------+

// Invoked when device is mounted
void tud_mount_cb(void)
{
  //blink_interval_ms = BLINK_MOUNTED;
}

// Invoked when device is unmounted
void tud_umount_cb(void)
{
  //blink_interval_ms = BLINK_NOT_MOUNTED;
}

// Invoked when usb bus is suspended
// remote_wakeup_en : if host allow us  to perform remote wakeup
// Within 7ms, device must draw an average of current less than 2.5 mA from bus
void tud_suspend_cb(bool remote_wakeup_en)
{
  (void) remote_wakeup_en;
  //blink_interval_ms = BLINK_SUSPENDED;
}

// Invoked when usb bus is resumed
void tud_resume_cb(void)
{
  //blink_interval_ms = tud_mounted() ? BLINK_MOUNTED : BLINK_NOT_MOUNTED;
}

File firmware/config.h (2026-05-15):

#ifndef CONFIG_H
#define CONFIG_H

#include "stdint.h"
#include <stdbool.h>
#include "pico/stdlib.h"



// GPIO PIN DEFINITIONS

#define USB_BOOT 0      


#define RIGHT_CHECK 12
#define NUMPAD_CHECK 13
#define NUM_LOCK_SCROLL_LOCK_LED 2
#define CAPS_LOCK_LED 3

#define NUM_ENC_A_I2C_SDA 4
#define NUM_ENC_B_I2C_SCL 5

#define MAIN_ENC_SW 18
#define MAIN_ENC_A 20
#define MAIN_ENC_B 19


#define SHIFT_REG_SH_LD 10
#define SHIFT_REG_CLK 11
#define SHIFT_REG_SERIAL_OUT 1

#define OLED_SDA 22
#define OLED_SCL 23

// END GPIO PIN DEFINITIONS

#define TOTAL_BITS 120 //The total number of keys on the keyboard. 8-bits x 15 shift regs = 120 bits.

#define TOTAL_KEYS 120  //Modify this to add keys not handled by the shift registers: e.g. encoder button.




#define WPM_CALC_INTERVAL_MS 5000  // Interval to calculate WPM in milliseconds (e.g., 5 seconds)
#define CHARACTERS_PER_WORD 5

#define IDLE_SPEED 10  // below this wpm value the animation will idle

#define ACTIVE_SPEED 40  // above this wpm value typing animation to trigger

#define TIME_BUFFER_SIZE 8


typedef struct {
    uint32_t last_interrupt_time;
    uint32_t characters_typed;      // Counts characters typed
    uint32_t last_wpm_calc_time;    // Last time WPM was calculated
    volatile int wpm;               // Words per minute
    uint8_t currentFrame;
    bool gameMode;
    volatile bool rightSideConnected;
    volatile bool numpadConnected;
    volatile uint8_t lastEncoderState;
} globalVariables;

extern globalVariables global; 



#endif

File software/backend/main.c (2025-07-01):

#include <stdio.h>
#include <stdlib.h>
#include <string.h>
#include <winsock2.h>
#include <windows.h>
#include <time.h>
#include <stdbool.h>
#include <tlhelp32.h>


#include "cJSON.h"

#pragma comment(lib, "ws2_32.lib")

#define SERVER_IP "127.0.0.1"
#define SERVER_PORT 8080
#define BUFFER_SIZE 256
#define QUEUE_SIZE 100


HANDLE hSerial;
DWORD bytesWritten;

FILETIME lastModified = {0};
volatile bool autoGameMode = false; 

enum timeZones {
    deviceTime = 0,
    EST = 1,
    CST = 2,
    JST = 3
};

int timeZone = deviceTime;

typedef struct {
    char message[BUFFER_SIZE];
} queueItem;

typedef struct{
    queueItem items[QUEUE_SIZE];
    int front, rear, size;
    CRITICAL_SECTION lock;
} messageQueue;

void initQueue(messageQueue *queue){
    queue->front = 0;
    queue->rear = -1;
    queue->size = 0;
    InitializeCriticalSection(&queue->lock);
}



int isQueueFull(messageQueue *queue){
    return queue->size == QUEUE_SIZE;
}

int isQueueEmpty(messageQueue *queue){
    return queue->size == 0;
}

void enqueue(messageQueue *queue, const char *message){
    EnterCriticalSection(&queue->lock);

    if (isQueueFull(queue)){
        LeaveCriticalSection(&queue->lock);
        return;
    }

    queue->rear = (queue->rear + 1) % QUEUE_SIZE;
    strcpy(queue->items[queue->rear].message, message);
    queue->size++;

    LeaveCriticalSection(&queue->lock);
}

int dequeue(messageQueue *queue, char *message){
    EnterCriticalSection(&queue->lock);

    if (isQueueEmpty(queue)){
        LeaveCriticalSection(&queue->lock);
        return 0;
    }

    strcpy(message, queue->items[queue->front].message);
    queue->front = (queue->front + 1) % QUEUE_SIZE;
    queue->size--;

    LeaveCriticalSection(&queue->lock);
    return 1;
}

void freeQueue(messageQueue *queue){
    DeleteCriticalSection(&queue->lock);
}

void setLowPriority() {
    if (!SetPriorityClass(GetCurrentProcess(), BELOW_NORMAL_PRIORITY_CLASS)) {
        printf("Failed to set low priority. Error: %lu\n", GetLastError());
    } else {
        printf("Process priority set to below normal.\n");
    }
}

SOCKET connectToServer(const char *serverIp, int port) {
    WSADATA wsaData;
    SOCKET sock = INVALID_SOCKET;
    struct sockaddr_in serverAddr;

    if (WSAStartup(MAKEWORD(2, 2), &wsaData) != 0) {
        printf("WSAStartup failed. Error: %d\n", WSAGetLastError());
        return INVALID_SOCKET;
    }

    sock = socket(AF_INET, SOCK_STREAM, IPPROTO_TCP);
    if (sock == INVALID_SOCKET) {
        printf("Socket creation failed. Error: %d\n", WSAGetLastError());
        WSACleanup();
        return INVALID_SOCKET;
    }

    serverAddr.sin_family = AF_INET;
    serverAddr.sin_addr.s_addr = inet_addr(serverIp);
    serverAddr.sin_port = htons(port);

    if (connect(sock, (struct sockaddr *)&serverAddr, sizeof(serverAddr)) == SOCKET_ERROR) {
        printf("Connection failed. Error: %d\n", WSAGetLastError());
        closesocket(sock);
        WSACleanup();
        return INVALID_SOCKET;
    }

    printf("Connected to server at %s:%d\n", serverIp, port);
    return sock;
}

void sendMessage(SOCKET sock, const char *message) {
    if (send(sock, message, strlen(message), 0) == SOCKET_ERROR) {
        printf("Failed to send message. Error: %d\n", WSAGetLastError());
    } else {
        printf("Message sent: %s\n", message);
    }
}

void getDesiredTime(char *buffer, size_t bufferSize, int timeZone) {
    time_t t = time(NULL);
    struct tm *timeinfo = gmtime(&t);
    if (timeZone == CST) {
        timeinfo->tm_hour -= 6;
    } else if (timeZone == JST) {
        timeinfo->tm_hour += 9;
    } else if (timeZone == EST) {
        timeinfo->tm_hour -= 5;
    } else if (timeZone == deviceTime) {
        timeinfo = localtime(&t);
    }
    strftime(buffer, bufferSize, "%I:%M%p", timeinfo);

}


bool file_has_changed(const char* filename) {
    HANDLE hFile = CreateFile(filename, GENERIC_READ, FILE_SHARE_READ, 
                             NULL, OPEN_EXISTING, FILE_ATTRIBUTE_NORMAL, NULL);
    
    if (hFile == INVALID_HANDLE_VALUE) return false;
    
    FILETIME currentModified;
    bool changed = false;
    
    if (GetFileTime(hFile, NULL, NULL, &currentModified)) {
        // Compare with stored time
        if (CompareFileTime(&lastModified, &currentModified) != 0) {
            lastModified = currentModified;  // Update stored time
            changed = true;
        }
    }
    
    CloseHandle(hFile);
    return changed;
}

char **gameList;
int gameListSize = 0;

int loadCJSON() {
     //extract list of games from JSON.
    FILE *fptr; 
    fptr = fopen("../frontend/settings/gameModeAppsList.json", "r");
    if (!fptr) return -1;

    fseek(fptr, 0, SEEK_END);
    long fileSize = ftell(fptr);
    fseek(fptr, 0, SEEK_SET);

    char* gameListStr = malloc(fileSize + 1);
    fread(gameListStr, 1, fileSize, fptr);

    fclose(fptr);

    cJSON *gameListJson = cJSON_Parse(gameListStr);
    free(gameListStr);
    if (!gameListJson) {
        printf("Error parsing JSON\n");
        return 1;
    }

    cJSON *gameModeApps = cJSON_GetObjectItem(gameListJson, "gameModeApps");
    if (!cJSON_IsArray(gameModeApps)) {
        printf("gameModeApps not array\n");
        cJSON_Delete(gameListJson);
        return 1;
    }

    gameListSize = cJSON_GetArraySize(gameModeApps);
    if (gameList) {
        free(gameList);
    }
    gameList = malloc(gameListSize * sizeof(char*));

    for (int i = 0; i < gameListSize; i++){
        cJSON *item = cJSON_GetArrayItem(gameModeApps, i);
        if (cJSON_IsString(item)) {
            char *appName = cJSON_GetStringValue(item);
            gameList[i] = strdup(appName);
        }
    }

    cJSON_Delete(gameListJson);
    return 0;
}

bool game_in_running_programs(){


    if (file_has_changed ("../frontend/settings/gameModeAppsList.json")){ 
        int success = loadCJSON();
        if (success) {
            return -1;
        }
    }

    HANDLE hSnapshot = CreateToolhelp32Snapshot(TH32CS_SNAPPROCESS, 0);
    PROCESSENTRY32 pe32;
    pe32.dwSize = sizeof(PROCESSENTRY32);

    if (hSnapshot == INVALID_HANDLE_VALUE) {
        printf("Error: unable to handle snapshot\n");
    }

    pe32.dwSize = sizeof(PROCESSENTRY32);

    if (Process32First(hSnapshot, &pe32)) {
        do {
            for (int i = 0; i < gameListSize; i++) {
                if (strcmp(pe32.szExeFile, gameList[i]) == 0) {
                    printf("Game found: %s\n", gameList[i]);
                    CloseHandle(hSnapshot);
                    return true;
                }
            }
        } while (Process32Next(hSnapshot, &pe32));
    }

    CloseHandle(hSnapshot);

    printf("No game found\n");

    return false;
    
}

void send_to_usb(const char* message){
    if (hSerial == INVALID_HANDLE_VALUE){
        printf("Error opening COM port\n");
        return;
    }
    WriteFile(hSerial, message, strlen(message), &bytesWritten, NULL);
    printf("%d bytes written", bytesWritten);
}
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

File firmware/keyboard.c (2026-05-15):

#include "config.h"
#include "keyboard.h"
#include "keymap.h"
#include "pico/stdlib.h"
#include "pico/time.h"
#include <tusb.h>
#include "usb_descriptors.h"
#include <string.h>
#include <stdio.h>
#include "hardware/gpio.h"
#include "bsp/board_api.h"


//static uint8_t last_state = 0b11;  // Initialize with the idle state (11)
    
/* Called when the encoder is rotated in clockwise or counterclockwise direction. */



typedef struct {
    uint8_t lastEightSamples;
    bool held;
} keyStatus_t;

keyStatus_t keyStatus[TOTAL_BITS];


void encoderCallBack(uint gpio, uint32_t events) {

    static uint32_t lastValidTime = 0;
    uint32_t currentTime = board_millis();

    if ((currentTime - lastValidTime) < 20) {
        return;
    }
    lastValidTime = currentTime;


    uint8_t enc_a_state = gpio_get(MAIN_ENC_A);
    uint8_t enc_b_state = gpio_get(MAIN_ENC_B);

    uint8_t currentEncoderState = (enc_a_state << 1) | enc_b_state;

    uint16_t volumeUp = HID_USAGE_CONSUMER_VOLUME_INCREMENT;
    uint16_t volumeDown = HID_USAGE_CONSUMER_VOLUME_INCREMENT;
    uint16_t release = 0;
    // Determine direction by comparing the current state to the previous state
    if ((global.lastEncoderState == 0b11 && currentEncoderState == 0b01) ||
        (global.lastEncoderState == 0b01 && currentEncoderState == 0b00) ||
        (global.lastEncoderState == 0b00 && currentEncoderState == 0b10) ||
        (global.lastEncoderState == 0b10 && currentEncoderState == 0b11)) {
        tud_hid_report(REPORT_ID_CONSUMER_CONTROL, &volumeUp, 2);
	sleep_ms(10);
	tud_hid_report(REPORT_ID_CONSUMER_CONTROL, &release, 2);
    } else if ((global.lastEncoderState == 0b11 && currentEncoderState == 0b10) ||
               (global.lastEncoderState == 0b10 && currentEncoderState == 0b00) ||
               (global.lastEncoderState == 0b00 && currentEncoderState == 0b01) ||
               (global.lastEncoderState == 0b01 && currentEncoderState == 0b11)) {
 
        tud_hid_report(REPORT_ID_CONSUMER_CONTROL, &volumeDown, 2);
	tud_hid_report(REPORT_ID_CONSUMER_CONTROL, &release, 2);	
    }
    

    // Update the last state with the current state
    global.lastEncoderState = currentEncoderState;
}




static bool key_is_modifier(uint8_t key) {
    return (key >= HID_KEY_CONTROL_LEFT && key <= HID_KEY_GUI_RIGHT);
}

// Function to get the corresponding bit for a modifier key
static uint8_t key_modifier_bit(uint8_t key) {
    return 1 << (key - HID_KEY_CONTROL_LEFT);
}


void get_keyboard_status(uint8_t* key_report, size_t len){
    uint8_t keyState[TOTAL_KEYS] = {0};

    int keyIndex = 2;  // Start filling regular key codes from the third byte
    bool anyKeyPressed = false;  // Flag to check if any key is pressed

    uint8_t *key_map= (global.rightSideConnected && !global.numpadConnected) ? key_map_noright:key_map_standard;

    

    gpio_put(SHIFT_REG_SH_LD, 0); // Set shift register shift/~load pin low to load in data.
    sleep_us(1);              // Short delay
    gpio_put(SHIFT_REG_SH_LD, 1); // Set  shift register shift/~load pin high to prepare to shift data.
    sleep_us(1);              // Short delay
    
    //This loop shifts the data for n number of keys to read the state of each key.
    for (int i = 0; i < TOTAL_BITS; i++) {
        gpio_put(SHIFT_REG_CLK, 1);  // Pulse the clock to shift the data
        sleep_us(1);              // Short delay

  

        bool currentPressed = gpio_get(SHIFT_REG_SERIAL_OUT) ? 0 : 1; // Read the bit, flip it so 0 means not pressed, 1 means pressed.

        keyStatus[i].lastEightSamples = ((keyStatus[i].lastEightSamples << 1) | (currentPressed & 1)) & 0xFF;
        
        if (currentPressed && !keyStatus[i].held && ((keyStatus[i].lastEightSamples & 0x1F) == 0)) {           //we check against the last 5 keys.          
            //new press, last five presses were 0.
            keyState[i] = true;
        } else if (currentPressed && ((keyStatus[i].held) ||((keyStatus[i].lastEightSamples & 0x1F) == 0x1F))) {
            keyStatus[i].held = true;
            keyState[i] = true;
        } else if (!currentPressed) {
            keyStatus[i].held = false;
            keyState[i] = false;
        }

        if (keyState[i]){
            uint8_t key = key_map[i];
            if (global.gameMode && (key == HID_KEY_GUI_LEFT || key == HID_KEY_GUI_RIGHT)) { //if game mode is active, skip windows.
                continue;  
            }
            anyKeyPressed = true;

            if (key_is_modifier(key)) { 
                key_report[0] |= key_modifier_bit(key);
            } else {
                if (keyIndex < 8) {
                    key_report[keyIndex++] = key;
                    if ((key != HID_KEY_SPACE) && (keyStatus[i].held == false)) {
                        global.characters_typed++;
                    }
                }
            }

        }

        gpio_put(SHIFT_REG_CLK, 0);  // Reset clock to low
        sleep_us(1);              // Short delay
    }
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

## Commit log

2023-05-24 Setting Up.
    [Schematic.SchDoc]
2023-07-24 Gerber files
    [PCB1.GBL, PCB1.GBO, PCB1.GBP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]
2023-07-24 Create gerber
2023-07-24 Update and rename PCB/PCB1-BoardEdgeRout.TXT to PCB/Keyboard-Gerber/PCB1-BoardEdgeRout.TXT
2023-07-24 Update and rename PCB/PCB1-RoundHoles.TXT to PCB/Keyboard-Gerber/PCB1-RoundHoles.TXT
2023-07-24 Update and rename PCB/PCB1-SlotHoles.TXT to PCB/Keyboard-Gerber/PCB1-SlotHoles.TXT
2023-07-24 Update and rename PCB/PCB1-macro.APR_LIB to PCB/Keyboard-Gerber/PCB1-macro.APR_LIB
2023-07-24 Update and rename PCB/Status Report.Txt to PCB/Keyboard-Gerber/Status Report.Txt
2023-07-24 Update and rename PCB/PCB1.DRR to PCB/Keyboard-Gerber/PCB1.DRR
2023-07-24 Update and rename PCB/PCB1.EXTREP to PCB/Keyboard-Gerber/PCB1.EXTREP
2023-07-24 Update and rename PCB/PCB1.GBL to PCB/Keyboard-Gerber/PCB1.GBL
    [PCB1.GBL]
2023-07-24 Update and rename PCB/PCB1.GBO to PCB/Keyboard-Gerber/PCB1.GBO
    [PCB1.GBO]
2023-07-24 Update and rename PCB/PCB1.GBP to PCB/Keyboard-Gerber/PCB1.GBP
    [PCB1.GBP]
2023-07-24 Update and rename PCB/Keyboard-Gerber/PCB1-BoardEdgeRout.TXT to PCB/Keyboard-Gerber/Keyboard-Gerber/PCB1-BoardEdgeRout.TXT
2023-07-24 Update and rename PCB/PCB1.GBS to PCB/Keyboard-Gerber/PCB1.GBS
    [PCB1.GBS]
2023-07-24 Update and rename PCB/PCB1.apr to PCB/Keyboard-Gerber/PCB1.apr
2023-07-24 Moved Files
    [PCB1.GM1, PCB1.GTL, PCB1.GTO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]
2023-07-24 Gerbers for HUB
    [PCB2.GBL, PCB2.GBO, PCB2.GBS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]
2023-07-27 Images of PCB
2023-07-28 Altium Files
    [PCB2.PcbDoc, Sheet1.SchDoc, Sheet2.SchDoc]
2023-08-02 Deleted Old Files.
    [PCB2.GBL, PCB2.GBO, PCB2.GBS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]
2023-08-02 Hub PCB
    [PCB2.GBL, PCB2.GBO, PCB2.GBS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]
2024-10-20 game mode
    Added a game mode: ctrl + comma (placeholder shortcut) will disable the windows key.
    [main.c]
2024-10-22 Setting up version 2
    [PCB1.GBL, PCB1.GBO, PCB1.GBP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]
2024-11-07 continuing work on firmware
    prerelease firmware. Board not made yet, so untested. (not even compiled)
2024-12-22 GUI to Sockets working.
    Python GUI to C Software bridge is done.
    Next step is: Program C background program, connect to keyboard.
2024-12-29 GUI now has the server, backend is now client.
    Flipped it so that the GUI now posses the server, making the backend lighter in terms of resources.
    Next steps are to implement USB comm, optimize resource usage.
    [main.c]
2025-01-06 Fixed socket issues
    Updated so backend can be running 24/7 and the GUI will have no further problems connecting to the backend.
    [main.c]
2025-06-26 began adding CDC functionality; will not work right now
    [main.c, tusb_config.h]
2025-06-26 Patched out simple errors, move to CDC+HID
    [main.c]
2025-06-26 got rid of all compile errors, next step is to implement CDC protocols.
    [tusb_config.h]
2025-06-26 Did some cppcheck fixes.
    [main.c]
2025-06-27 Finally pushing updated hardware
    [ComponentsSheet.xlsx]
2025-06-27 Refactored file structure for hardware.
    [BOM-numlocked_HUB.csv, BOM-numlocked_left_plate.csv, BOM-numlocked_numpad.csv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]
2025-07-01 Added hotswap connectors image
2025-07-01 uploaded LED picture
2025-07-01 keycap commit
    [4_Numpad.0001.ipt, 4_Numpad.ipt, 5_Numpad.ipt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]
2025-07-16 New PCB renders
2025-08-03 Hardware V3 (changing)
    [BOM-Numlocked_shift_stencil.csv, BOM-numlocked_HUB.csv, BOM-numlocked_left_plate.csv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]
2025-08-25 I am stupid. I am stupid
    https://youtu.be/aS4Me48wayM?si=ZLHS1zHPjDahWzTt
    Fixed the dumbest hardware issue known to man.
    [BOM-Numlocked_shift_stencil.csv, BOM-numlocked_HUB.csv, BOM-numlocked_left_plate.csv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]
2025-09-08 Another quick hardware push. Sorry Github servers.
    [BOM-Numpad_stencil.csv, BOM-numlocked_numpad.csv, BOM-numlocked_numpad_plate.csv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]
2025-12-17 fixed rotary encoder, potentially fixed linux issues
    [config.h, keyboard.c, main.c]
